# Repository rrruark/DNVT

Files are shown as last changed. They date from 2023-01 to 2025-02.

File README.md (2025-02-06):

# DNVT
Digital Non-secure Voice Terminal Test Code and Switch PCBA Design Files.

http://robruark.com/projects/DNVT/DNVT_overview.html

This repo contains the PCBA design files for the DNVT test interface boards, four phone switches which run Nick Andre's code, and the crappy support code I wrote to initially reverse engineering DNVTs. 

The Arduino code encodes and decodes Differential Manchester, and the Python scripts determine the codewords. There is also a Python script which decodes differential manchester based on a CSV capture from an oscilloscope. Example files are provided.

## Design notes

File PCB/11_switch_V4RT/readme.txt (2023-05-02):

Eagle Schematic: DNVT_box3rt.sch
Eagle Layout: DNVT_box3rt.brd
Schematic PDF: DNVT_box3rt.pdf

JLCPCB Gerbers: DNVT_box3rt_2023-05-02.zip
JLCPCB Top Placement: DNVT_box3rt_top_cpl.csv
JLCPCB BOM: DNVT_box3rt_top_bom.csv

Through Hole BOM: DNVT_box3rt_th_bom.csv
Additional BOM: DNVT_box3r_aux_bom.csv

Notes:

-The JLCPCB BOM maps all surface mount parts and all through hole parts aside from the DC barrel jack and transformers to parts available in JLCPCB's parts library.
-The bottom side parts are optional (additional chassis ground to Pico Ground capacitors and uSD card holder)
-The Digikey BOM lists through hole parts (DC barrel jack and transformers) which must be manually assembled.
-The additional BOM lists parts not captured in the Eagle BOM export: the case, OLED screen, Front and back plates, screws, nuts, cable for screen, and 48V power supply.

Designer Contact: Robert Ruark: rob@robruark.com

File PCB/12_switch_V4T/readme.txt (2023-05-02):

Eagle Schematic: DNVT_box4t.sch
Eagle Layout: DNVT_box4t.brd
Schematic PDF: DNVT_box4t.pdf

JLCPCB Gerbers: DNVT_box4t_2023-05-02.zip
JLCPCB Top Placement: DNVT_box4t_top_cpl.csv
JLCPCB BOM: DNVT_box4t_top_bom.csv

Through Hole BOM: DNVT_box4t_th_bom.csv
Additional BOM: DNVT_box4_aux_bom.csv

Notes:

-The JLCPCB BOM maps all surface mount parts and all through hole parts aside from the DC barrel jack, terminal blocks, and transformers to parts available in JLCPCB's parts library.
-The bottom side parts are optional (additional chassis ground to Pico Ground capacitors and uSD card holder)
-The Digikey BOM lists through hole parts which must be manually assembled as well as the LCSC alternatives for these parts where available.
-The additional BOM lists parts not captured in the Eagle BOM export: headers for the Pico, the case, OLED screen, Front and back plates, screws, nuts, cable for screen, and 48V power supply.

Designer Contact: Robert Ruark: rob@robruark.com

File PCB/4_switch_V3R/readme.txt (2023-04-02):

Eagle Schematic: DNVT_box3r.sch
Eagle Layout: DNVT_box3r.brd
Schematic PDF: DNVT_box3r.pdf

JLCPCB Gerbers: DNVT_box3r_2023-01-16.zip
JLCPCB Top Placement: DNVT_box3r_top_cpl.csv
JLCPCB BOM: DNVT_box3r_top_bom.csv

Through Hole BOM: DNVT_box3r_th_bom.csv
Additional BOM: DNVT_box3r_aux_bom.csv

Notes:

-The rotation of the inductors and RS422 transceivers must be manually corrected at the placement review step after uploading to JLCPCB.
-The JLCPCB BOM maps all surface mount parts to parts available in JLCPCB's parts library.
-The bottom side parts are optional (additional chassis ground to Pico Ground capacitors and uSD card holder)
-The Digikey BOM lists through hole parts which must be manually assembled as well as the LCSC alternatives for these parts where available.
-The additional BOM lists parts not captured in the Eagle BOM export: headers for the Pico, the case, OLED screen, Front and back plates, screws, nuts, cable for screen, and 48V power supply.

Designer Contact: Robert Ruark: rob@robruark.com

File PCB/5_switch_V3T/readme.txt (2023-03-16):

Eagle Schematic: DNVT_box3t.sch
Eagle Layout: DNVT_box3t.brd
Schematic PDF: DNVT_box3t.pdf

JLCPCB Gerbers: DNVT_box3t_2023-02-21.zip
JLCPCB Top Placement: DNVT_box3t_top_cpl.csv
JLCPCB BOM: DNVT_box3t_top_bom.csv

Through Hole BOM: DNVT_box3t_th_bom.csv
Additional BOM: DNVT_box3_aux_bom.csv

Notes:

-The rotation of the inductors and RS422 transceivers must be manually corrected at the placement review step after uploading to JLCPCB.
-The JLCPCB BOM maps all surface mount parts to parts available in JLCPCB's parts library.
-The bottom side parts are optional (additional chassis ground to Pico Ground capacitors and uSD card holder)
-The Digikey BOM lists through hole parts which must be manually assembled as well as the LCSC alternatives for these parts where available.
-The additional BOM lists parts not captured in the Eagle BOM export: headers for the Pico, the case, OLED screen, Front and back plates, screws, nuts, cable for screen, and 48V power supply.

Engineer Contact: Robert Ruark: rob@robruark.com

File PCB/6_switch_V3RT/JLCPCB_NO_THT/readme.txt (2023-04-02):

Eagle Schematic: DNVT_box3rt.sch
Eagle Layout: DNVT_box3rt.brd
Schematic PDF: DNVT_box3rt.pdf

JLCPCB Gerbers: DNVT_box3rt_2023-02-21.zip
JLCPCB Top Placement: DNVT_box3rt_top_cpl.csv
JLCPCB BOM: DNVT_box3rt_top_bom.csv

Through Hole BOM: DNVT_box3rt_th_bom.csv
Additional BOM: DNVT_box3r_aux_bom.csv

Notes:

-With this set of files, JLCPCB will only assemble the surface mount parts. This was used to order initial runs of the DNVT switch prior to when I figured out how to get them to assemble through holes parts (their scripts do not handle through hole parts, so you have to manually add them to the BOM and placement file).
-The rotation of the inductors and RS422 transceivers must be manually corrected at the placement review step after uploading to JLCPCB.
-The JLCPCB BOM maps all surface mount parts to parts available in JLCPCB's parts library.
-The bottom side parts are optional (additional chassis ground to Pico Ground capacitors and uSD card holder)
-The Digikey BOM lists through hole parts which must be manually assembled as well as the LCSC alternatives for these parts where available.
-The additional BOM lists parts not captured in the Eagle BOM export: headers for the Pico, the case, OLED screen, Front and back plates, screws, nuts, cable for screen, and 48V power supply.

Designer Contact: Robert Ruark: rob@robruark.com

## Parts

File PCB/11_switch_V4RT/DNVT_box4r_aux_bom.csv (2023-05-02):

Part | Quantity | Supplier 1 | Link or Ordering Number 1 | Supplier 2 | Link or Ordering Number 2
48V power supply | 1 | Digikey | 993-1303-ND
M3x6 Screw | 8 | Amazon | https://www.amazon.com/dp/B09D93RW6L?psc=1&ref=ppx_yo2ov_dt_b_product_details
M2x6 Screw | 4 | Amazon | https://www.amazon.com/dp/B09D93RW6L?psc=1&ref=ppx_yo2ov_dt_b_product_details
M2 Nut | 3 | Digikey | H761-ND | Amazon | https://a.co/d/bEnPR0s
4-pin Dupont Cable | 1 | Amazon | https://www.amazon.com/gp/product/B0789F523N/ref=ppx_yo_dt_b_search_asin_title?ie=UTF8&psc=1
OLED Screed | 1 | Amazon | https://www.amazon.com/gp/product/B09C5K91H7/ref=ppx_yo_dt_b_search_asin_title?ie=UTF8&psc=1
Front Plate | 1 | JLCPCB | https://github.com/rrruark/DNVT/tree/master/PCB/7_box_front
Back Plate | 1 | JLCPCB | https://github.com/rrruark/DNVT/tree/master/PCB/8_box_back_rj45
RASPBERRY PI PICO H | 1 | Digikey | 2648-SC0917-ND | Amazon | https://a.co/d/59dRezT

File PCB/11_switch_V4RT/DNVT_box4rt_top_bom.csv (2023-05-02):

Comment | Designator | Footprint | LCSC Part #
0 | R7 R34 R44 R54 | R0805
0.1uF | C6 C9 C12 C14 C41 C45 | 603
1M | R8 | 1206 | C17927
1k | R18 R19 | 603
1nF | C2 C3 C4 C7 C8 C10 | 805
1nF | C16 | 1206 | C9196
1nF | C18 C19 C20 C21 C22 C23 C25 C26 C27 C28 C29 C30 C32 C33 C34 C35 C36 C37 | 805
1uF | C1 C5 C11 C13 C15 C17 C24 C31 | 805
1uF | C40 | 1206
1uF | C42 | 805
10 | R1 R2 R4 R10 R17 R20 R21 R22 R23 R24 R25 R26 R27 R28 | 603
10 | R29 | 1206
10 | R31 | 603
10k | R3 R9 R15 | 603
33uH | L1 L2 L3 L4 L5 L6 L7 L8 L9 L10 L11 L12 L13 L14 L15 L16 | SDR0403 | C341014
49.9 | R12 R13 R37 R38 R47 R48 R57 R58 | R0805
100pF | C43 C44 | 603
120 | R14 R41 R51 R61 | 1206
470 | R5 R11 R32 R36 R42 R46 R52 R56 | R0805
600V | GDT1 GDT2 GDT3 GDT4 GDT5 GDT6 GDT7 GDT8 | 2036_GDT | C2908079
1206_FUSE | F1 F2 F3 F4 | 1206 | C135333
ES1JFL | CR1 CR2 | SOD123(AK) | C64898
ISL83490IBZ-T | U1 U2 U3 U5 | SOIC8 | C2932177
SMAJ5.0CA/TR7 | D3 D4 D8 D9 D10 D11 D12 D13 | DO-214AC_NO_POL | C78402
RJ45 | J1 J2 |  | C3010550
Welding terminal | J3 | 7779 or 8190 | C238168
6 pin header | JP1 |  | C2935935
4 pin header | JP3 |  | C2691448
20 pin header | JP4 JP5 |  | C429947
RA tactile sw | SW1 |  | C2845272
4 dip switch | SW2 |  | C962226

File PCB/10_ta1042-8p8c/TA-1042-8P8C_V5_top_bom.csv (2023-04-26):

Comment | Designator | Footprint | LCSC Part #
TPTP20R | BLUE BLUE-WHITE GREEN GREEN-WHITE | TP20R
RJ45 | J1 J2 |  | C3010550

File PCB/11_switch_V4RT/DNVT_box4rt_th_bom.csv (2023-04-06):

Qty | Value | Device | Package | Parts | Description | Assembled by JLCPCB | PARTNO
8 | 78615/9C | 78615/9C | 786T | T1, T2, T3, T4, T5, T6, T7, T8 | 10mH General Purpose Pulse Transformer 1CT:1CT 56Vus | No | 811-1261-5-ND
1 | PJ-002A | PJ-002A | PJ-002A | J4 | Power Barrel Connector Jack 2.10mm ID (0.083"), 5.50mm OD (0.217") Through Hole, Right Angle | No | CP-002A-ND

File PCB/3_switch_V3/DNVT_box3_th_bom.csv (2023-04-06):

Qty | Value | Device | Package | Parts | Description | Assembled by JLCPCB | PARTNO | LCSC | SPICEPREFIX | VALUE
1 |  | PINHD-1X4 | 1X04 | JP3 | PIN HEADER | No | 2057-PH1-04-UA-ND | C2691448
1 |  | PINHD-2X3/90 | 2X03/90 | JP1 | PIN HEADER | No | 2057-PH2RA-06-UA-ND | C2935935
1 |  | SW_DIP-4 | EDG-04 | SW2 | DIP SWITCH | No | 2449-KG04E-ND | C962226
4 | 0 | R-US_R0805 | R0805 | R7, R34, R44, R54 | RESISTOR, American symbol | Yes |  |  | R
5 | 0.1uF | 0603_CAPACITOR | 603 | C6, C9, C12, C14, C41 | 0603 Capacitor -- WARNING: NO DEFINED VALUE OR PART NUMBER | Yes |  |  |  | sel
15 | 10 | 0603_RESISTOR | 603 | R1, R2, R4, R10, R17, R20, R21, R22, R23, R24, R25, R26, R27, R28, R31 | 0603 Resistor -- WARNING: NO DEFINED PART NUMBER OR VALUE | Yes |  |  |  | sel
1 | 10 | 1206_RESISTOR | 1206 | R29 | NO DEFINED PN | Yes |  |  |  | sel
3 | 10k | 0603_RESISTOR | 603 | R3, R9, R15 | 0603 Resistor -- WARNING: NO DEFINED PART NUMBER OR VALUE | Yes |  |  |  | sel
4 | 120 | 1206_RESISTOR | 1206 | R14, R41, R51, R61 | NO DEFINED PN | Yes |  |  |  | sel
4 | 1206_FUSE | 1206_FUSE | 1206 | F1, F2, F3, F4 |  | Yes
1 | 1M | 1206_RESISTOR | 1206 | R8 | NO DEFINED PN | Yes |  |  |  | sel
2 | 1k | 0603_RESISTOR | 603 | R18, R19 | 0603 Resistor -- WARNING: NO DEFINED PART NUMBER OR VALUE | Yes |  |  |  | sel
24 | 1nF | 0805_CAPACITOR | 805 | C2, C3, C4, C7, C8, C10, C18, C19, C20, C21, C22, C23, C25, C26, C27, C28, C29, C30, C32, C33, C34, C35, C36, C37 | NO DEFINED PN | Yes
1 | 1nF | 1206_CAPACITOR | 1206 | C16 | NO DEFINED PN | Yes |  |  |  | sel
9 | 1uF | 0805_CAPACITOR | 805 | C1, C5, C11, C13, C15, C17, C24, C31, C42 | NO DEFINED PN | Yes
1 | 1uF | 1206_CAPACITOR | 1206 | C40 | NO DEFINED PN | Yes |  |  |  | sel
16 | 33uH | SDR0403-330KL | SDR0403 | L1, L2, L3, L4, L5, L6, L7, L8, L9, L10, L11, L12, L13, L14, L15, L16 | 33 µH Unshielded Drum Core, Wirewound Inductor 640 mA 540mOhm Max Nonstandard | Yes | SDR0403-330KLCT-ND |  |  | 33uH
8 | 470 | R-US_R0805 | R0805 | R5, R11, R32, R36, R42, R46, R52, R56 | RESISTOR, American symbol | Yes |  |  | R
8 | 49.9 | R-US_R0805 | R0805 | R12, R13, R37, R38, R47, R48, R57, R58 | RESISTOR, American symbol | Yes |  |  | R
8 | 600V | 2036-60-SM-RPLF | 2036_GDT | GDT1, GDT2, GDT3, GDT4, GDT5, GDT6, GDT7, GDT8 | Gas Discharge Tube 600 V 10000A (10kA) ±20% 3 Pole Surface Mount | Yes | 2036-60-SM-RPLFCT-ND |  |  | 600V
8 | 78602/9JC | 78602/9JC | 786 | T1, T2, T3, T4, T5, T6, T7, T8 | 10mH General Purpose Pulse Transformer 1CT:1CT Surface Mount 56Vus | No | 811-1261-5-ND
1 | 8190 | 8190 | 7781 | J3 | 4 Pin Screw Terminal, Power Tap 6-32 Through Hole, Right Angle | No | 36-8190-ND
2 | 1841513 | 1841513 | 1841513 | J6, J7 | 4x2 Position Wire to Board Terminal Block Horizontal with Board 0.138 | (3.50mm) | Through | Hole. | Compatible | with | Cixi | Kefa | Elec | KF207RH-3.5-2*4P" | 277-10317-ND
3 | DNP | 0603_RESISTOR | 603 | R16, R30, R35 | 0603 Resistor -- WARNING: NO DEFINED PART NUMBER OR VALUE | No |  |  |  | sel
2 | DNP | 1206_CAPACITOR | 1206 | C38, C39 | NO DEFINED PN | No |  |  |  | sel
4 | DNP | R-US_R0805 | R0805 | R6, R33, R43, R53 | RESISTOR, American symbol | No |  |  | R
2 | ES1JFL | ES1JFL | SOD123(AK) | CR1, CR2 | Diode Standard 600 V 1A Surface Mount SOD-123F | Yes | ES1JFLCT-ND
1 | EVQ-PF008K | EVQ-PF008K | EVQ-PF008K | SW1 | Tactile Switch SPST-NO Side Actuated Through Hole, Right Angle | No | P10880S-ND
1 | PJ-002A | PJ-002A | PJ-002A | J4 | Power Barrel Connector Jack 2.10mm ID (0.083"), 5.50mm OD (0.217") Through Hole, Right Angle | No | CP-002A-ND
4 | ISL83490IBZ-T | ISL83490IBZ-T | SOIC8 | U1, U2, U3, U5 | 1/1 Transceiver Full RS422, RS485 8-SOIC 3.3V | Yes | ISL83490IBZ-TCT-ND
1 | MEM2080-00-128-00-A | MEM2080-00-128-00-A | MEM2080 | J5 | 9 (8 + 1) Position Card Connector Secure Digital - microSD™ Surface Mount, Right Angle Gold | No | 2073-MEM2080-00-128-00-ACT-ND
1 | RASPBERRY_PICOTH | RASPBERRY_PICOTH | PICO-PKG-TH | U7 | Raspberry Pi Pico | No | 2648-SC0917-ND
8 | SMAJ5.0CA/TR7 | SMAJ5.0CA/TR7 | DO-214AC_NO_POL | D3, D4, D8, D9, D10, D11, D12, D13 | 9.2V Clamp 43.5A Ipp Tvs Diode Surface Mount DO-214AC (SMA) | Yes

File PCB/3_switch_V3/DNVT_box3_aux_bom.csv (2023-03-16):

Part | Quantity | Supplier 1 | Link or Ordering Number 1 | Supplier 2 | Link or Ordering Number 2
1x20 female header | 2 | Digikey | 952-1905-ND | LCSC | C5224030
48V power supply | 1 | Digikey | 993-1303-ND
M3x6 Screw | 8 | Amazon | https://www.amazon.com/dp/B09D93RW6L?psc=1&ref=ppx_yo2ov_dt_b_product_details
M2x6 Screw | 4 | Amazon | https://www.amazon.com/dp/B09D93RW6L?psc=1&ref=ppx_yo2ov_dt_b_product_details
M2 Nut | 3 | Digikey | H761-ND | Amazon | https://www.amazon.com/gp/product/B01KCOH60K/ref=ppx_yo_dt_b_search_asin_title?ie=UTF8&th=1
4-pin Dupont Cable | 1 | Amazon | https://www.amazon.com/gp/product/B0789F523N/ref=ppx_yo_dt_b_search_asin_title?ie=UTF8&psc=1
OLED Screen | 1 | Amazon | https://www.amazon.com/gp/product/B09C5K91H7/ref=ppx_yo_dt_b_search_asin_title?ie=UTF8&psc=1
Front Plate | 1 | JLCPCB | https://github.com/rrruark/DNVT/tree/master/PCB/7_box_front
Back Plate | 1 | JLCPCB | https://github.com/rrruark/DNVT/tree/master/PCB/9_box_back

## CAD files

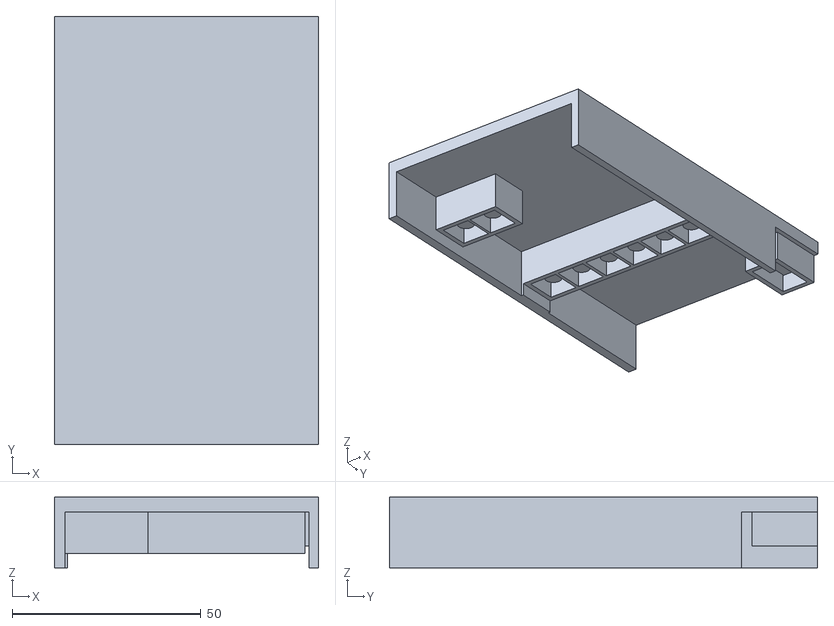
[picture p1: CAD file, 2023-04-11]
PCB/Soldring_fixture.stl
70.0 x 113.4 x 18.8

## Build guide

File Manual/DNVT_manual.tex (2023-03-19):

%% Example data sheet
%% Feel free to modify and use this file for any purpose, under
%% either the LaTeX Project Public License or under public domain.

% Options here are passed to the article class.
% Most common options: 10pt, 11pt, 12pt
\documentclass[10pt]{datasheet}

% Input encoding and typographical rules for English language
\usepackage[utf8]{inputenc}
\usepackage[english]{babel}
\usepackage[english]{isodate}
\usepackage[final]{pdfpages}

% tikz is used to draw images in this example, but you can
% also use \includegraphics{}.
\usepackage{tikz}
\usepackage{pgfplots}
\usepackage{circuitikz}

\usetikzlibrary{calc}

% These define global texts that are used in headers and titles.
\title{DNVT Switch}
\author{Robert Ruark}
\date{March 2023}
\revision{Revision 1}
\companylogo{\Huge }

\begin{document}
\maketitle

\section{Features}

\begin{itemize}
\item{4 DNVT (Digital Non-Secure Voice Terminal) Phone Interfaces supporting 16 kHz or 32 kHz operation.}
\item{Rugged extruded aluminum case.}
\item{128x64 pixel OLED display.}
\item{Front panel expansion header.}
\item{Foolproof USB firmware update.}
\item{Terminal block and RJ45 DNVT interface options.}
\item{Transient voltage protection.}
\end{itemize}

\section{Applications}

\begin{itemize}
\item{Stand-alone local switching of four DNVTs}
\item{VOIP to DNVT adapters.}
\item{DNVT operation for functional film props.}
\end{itemize}

\section{Supported Phones}

\begin{itemize}
\item{TA-1042/U}
\item{TA-1035/U}
\item{TA-954/TT}
\item{CA-67A/U (Untested)}
\item{KY-68 (Assumed compatible in non-secure mode)}
\end{itemize}

\section{General Description}
This PCBA is a Raspberry Pi Pico carrier board which interfaces DNVTs with a Raspberry Pi Pico. This document describes the function of the carrier board subassembly and does not cover custom software which may run on the Raspberry Pi Pico microcontroller.

DNVTs are powered in common battery (CB) mode through center-tapped isolation transformers from a 48 V DC barrel jack input allowing phones to operate at a distance of up to 4 km from the switch through CAT5e or equivilent wiring. RS422 transceivers translate the 3.3 V logic level signals of the Raspberry Pi Pico to the differential signals required to interface with the DNVTs.

The design files for this switch can be found in the project's \href{https://github.com/PetteriAimonen/latex-datasheet-template/}{Github repository}, and Nick Andre's example firmware can be found in his \href{https://github.com/PetteriAimonen/latex-datasheet-template/}{Github repository}. Details on the design of this board and the process of reverse engineering the DNVT's control codes can be found \href{https://github.com/PetteriAimonen/latex-datasheet-template/}{here}.

This project is entirely open source. Design files for the PCBAs and vill of materials for the case and auxillary components can be found at the above linked repository.

\begin{figure}
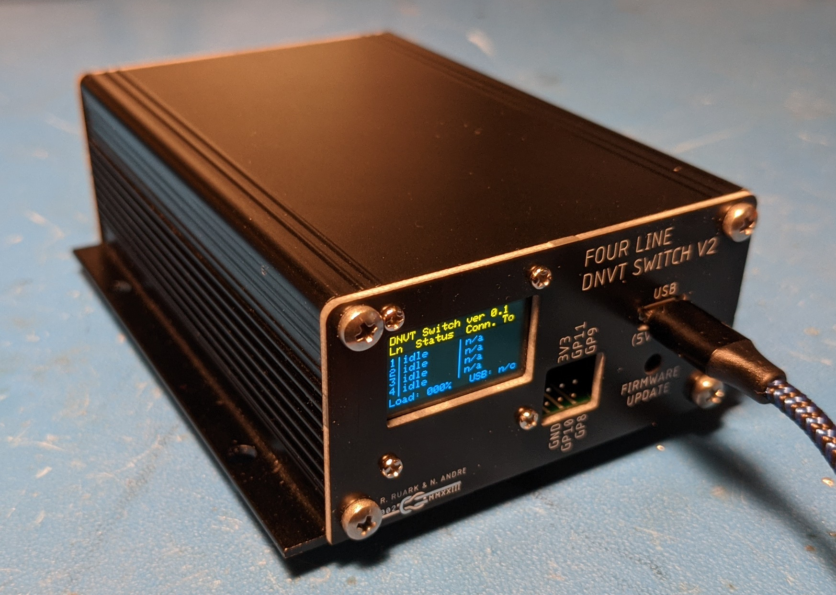
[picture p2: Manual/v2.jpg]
  
  \caption{Front View of DNVT Switch}
  \label{fig:boat1}
\end{figure}

% For wide tables, a single column layout is better. It can be switched
% page-by-page.
\onecolumn

\section{Electrical Specifications}
All specifications are in $0\degree C \leq T_A \leq 70\degree C$. All components are rated to -40 to +85 aside from the line transformers which are rated to $0\degree C$ to $70\degree C$ but which have been tested in qualification to $-20\degree C$ to $+85\degree C$.

\begin{table}[h]
\begin{threeparttable}
\caption{Example Data Sheet Specifications}
\begin{tabularx}{\textwidth}{l | c | c c c | c | X}
    \thickhline
    \textbf{Parameter} & \textbf{Symbol} & \textbf{Min.} & \textbf{Typ.} & \textbf{Max.} &
    \textbf{Unit} & \textbf{Conditions} \\
    \hline
    DNVT PWR Input Voltage  & $V_{in}$ & 24 & 48 & 56 & $V$ & {Standard A4 paper} \\
    \hline
    DNVT PWR Input Current & $I_{in}$ & 29.6 & 29.7 & 29.8 & $A$ & All phones consuming maximum specified power with 4 km CAT5e Cable\\
    \hline
    DNVT Current Limit & $I_{ph-max}$ &  & 150 &  & $mA$ & Current limit per phone\\    
    \hline
    Input Differential Swing & $\Delta V_{TH}$ & 50 &  & & $mV$ & $VIN_{P}-VIN_N$\\
    \hline
    Output Differential Swing & $E_{max}$ & & 3 & & $V$ & $VOUT_P-VOUT_N$\\        
    \thickhline
\end{tabularx}
\end{threeparttable}
\end{table}

\section{Absolute Maximum Ratings}

\begin{table}[h]
\caption{Absolute Maximum Ratings of Example Data Sheet}
\begin{tabularx}{\textwidth}{l | X}
    \thickhline
    \textbf{Parameter} & \textbf{Rating} \hspace{5cm} \\
    \hline
    DNVT PWR Input Voltage & 60 V \\
    \hline
    Storage Temperature & 100$\degree C$ \\
    \hline
    Operating Temperature & 85$\degree C$ \\
    \thickhline
\end{tabularx}
\end{table}

\textbf{Note:} Stresses above those listed under Absolute Maximum Ratings can
cause permanent damage to the device. This is a stress rating only. Functional
operation of the device is not implied in any conditions above those indicated
in the Electrical Specifications section.

\includepdf[pages=-]{DNVT_box3rt.pdf}

\subsection{Important Notice}

Information relating to this product and the application or design described herein is believed to be reliable, however such information
is provided as a guide only and the author assumes no liability for any errors in this document, or for the application or design described
herein.

THIS PRODUCT IS NOT DESIGNED, INTENDED, AUTHORIZED OR WARRANTED TO BE SUITABLE FOR USE IN LIFE-SUPPORT
APPLICATIONS, SEARH AND RESCUE APPLICATIONS, OR IN APPLICATIONS IN WHICH THE FAILURE COULD BE REASONABLY EXPECTED TO
RESULT IN PERSONAL INJURY, LOSS OF LIFE OR SEVERE PROPERTY OR ENVIRONMENTAL DAMAGE. INCLUSION OF THIS PRODUCT IN
SUCH APPLICATIONS IS UNDERSTOOD TO BE UNDERTAKEN SOLELY AT THE CUSTOMER’S OWN RISK. 

This product alone does not provide protection to structures from the ingress of lightning and other hazardous transient conditions. Any installation of this product in a structure (house, barn, telephone exchange, etc.) must be made in compliance with NFPA 70 article 800 which requires the use of a secondary protection device at the point of entry to the structure.

Should a customer purchase or use this product for any such unauthorized application, the customer shall indemnify and hold Robert Ruark, Nick Andre, affiliates, and distributors harmless against all claims, costs damages and attorney fees which could arise. The product described in this document may be altered or discontinued without further
notice. No warranty, representation or guarantee, express or implied, regarding the suitability of its products for any
particular purpose is conveyed by the contents of this document. 

© Robert Ruark 2023
\end{document}

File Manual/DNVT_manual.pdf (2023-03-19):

# DNVT Switch

## Features

4 DNVT (Digital Non-Secure Voice Terminal) Phone Interfaces supporting 16 kHz or 32 kHz operation.

Rugged extruded aluminum case.

128x64 pixel OLED display.

Front panel expansion header.

Foolproof USB firmware update.

Terminal block and RJ45 DNVT interface options.

Transient voltage protection.

## Applications

Stand-alone local switching of four DNVTs

VOIP to DNVT adapters.

DNVT operation for functional film props.

## Supported Phones

TA-1042/U

TA-1035/U

TA-954/TT

CA-67A/U (Untested)

KY-68 (Assumed compatible in non-secure mode)


Figure 1: Front View of DNVT Switch

## General Description

This PCBA is a Raspberry Pi Pico carrier board which interfaces DNVTs with a Raspberry Pi Pico. This document describes the function of the carrier board sub-assembly and does not cover custom software which may run on the Raspberry Pi Pico microcontroller.

DNVTs are powered in common battery (CB) mode through center-tapped isolation transformers from a 48 V DC barrel jack input allowing phones to operate at a distance of up to 4 km from the switch through CAT5e or equivilent wiring. RS422 transceivers translate the 3.3 V logic level signals of the Raspberry Pi Pico to the differential signals required to interface with the DNVTs.

The design files for this switch can be found in the project’s Github repository, (https://github.com/PetteriAimonen/latex-datasheet-template/) and Nick Andre’s example firmware can be found in his Github repository. (https://github.com/PetteriAimonen/latex-datasheet-template/) Details on the design of this board and the process of reverse en-gineering the DNVT’s control codes can be found here. (https://github.com/PetteriAimonen/latex-datasheet-template/)

This project is entirely open source. Design files for the PCBAs and vill of materials for the case and auxillary components can be found at the above linked repository.

Revision 1 | March 2023 | Page 1 of 6

Robert Ruark | DNVT Switch | March 2023

## Electrical Specifications

All specifications are in 0◦C ≤ TA ≤ 70◦C. All components are rated to -40 to +85 aside from the line transformers which are rated to 0◦C to 70◦C but which have been tested in qualification to −20◦C to +85◦C.

Table 1: Example Data Sheet Specifications

Parameter | Symbol | Min. | Typ. | Max. | Unit | Conditions
DNVT PWR Input Voltage | Vin | 24 | 48 | 56 | V | Standard A4 paper
DNVT PWR Input Current | Iin | 29.6 | 29.7 | 29.8 | A | All phones consuming maximum specified power with 4 km CAT5e Cable
DNVT Current Limit | Iph−max | | 150 | | mA | Current limit per phone
Input Differential Swing | ∆VTH | 50 | | | mV | V INP − V INN
Output Differential Swing | Emax | | 3 | | V | V OUTP − V OUTN

## Absolute Maximum Ratings

Table 2: Absolute Maximum Ratings of Example Data Sheet

Parameter | Rating
DNVT PWR Input Voltage | 60 V
Storage Temperature | 100◦C
Operating Temperature | 85◦C

Note: Stresses above those listed under Absolute Maximum Ratings can cause permanent damage to the device. This is a stress rating only. Functional operation of the device is not implied in any conditions above those indicated in the Electrical Specifications section.

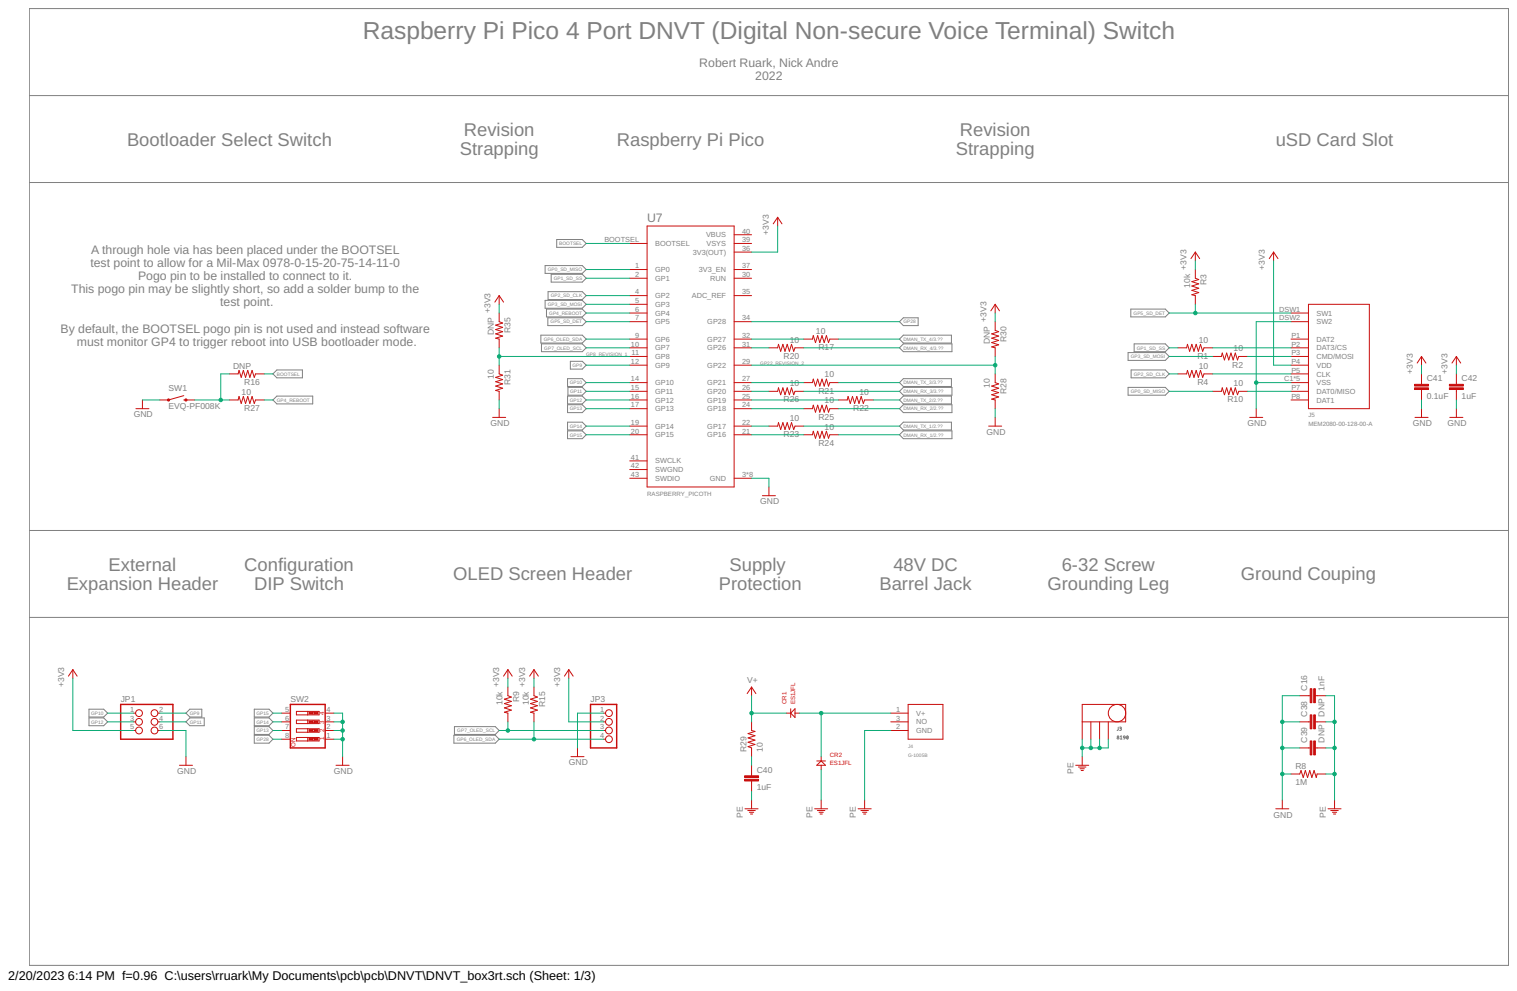
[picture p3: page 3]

Raspberry Pi Pico 4 Port DNVT (Digital Non-secure Voice Terminal) Switch

Robert Ruark, Nick Andre

A through hole via has been placed under the BOOTSEL
test point to allow for a Mil-Max 0978-0-15-20-75-14-11-0
Pogo pin to be installed to connect to it. This pogo pin may be slightly short, so add a solder bump to the

test point. By default, the BOOTSEL pogo pin is not used and instead software

must monitor GP4 to trigger reboot into USB bootloader mode. Configuration

2/20/2023 6:14 PM f=0.96 C:\users\rruark\My Documents\pcb\pcb\DNVT\DNVT_box3rt.sch (Sheet: 1/3)

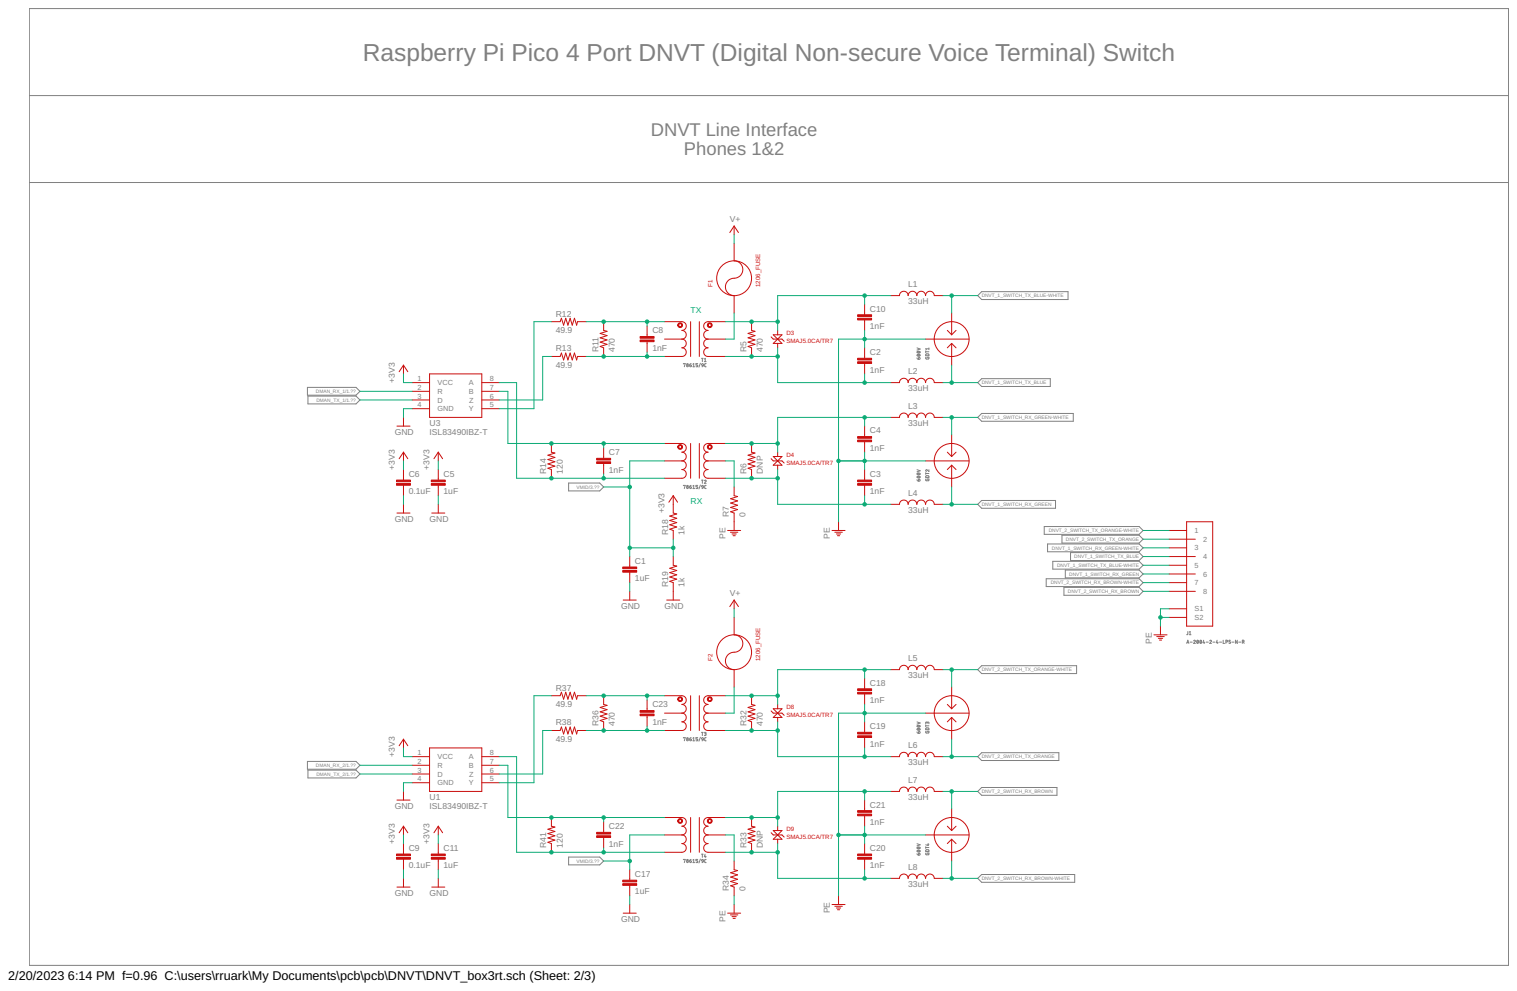
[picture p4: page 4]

Raspberry Pi Pico 4 Port DNVT (Digital Non-secure Voice Terminal) Switch

2/20/2023 6:14 PM f=0.96 C:\users\rruark\My Documents\pcb\pcb\DNVT\DNVT_box3rt.sch (Sheet: 2/3)

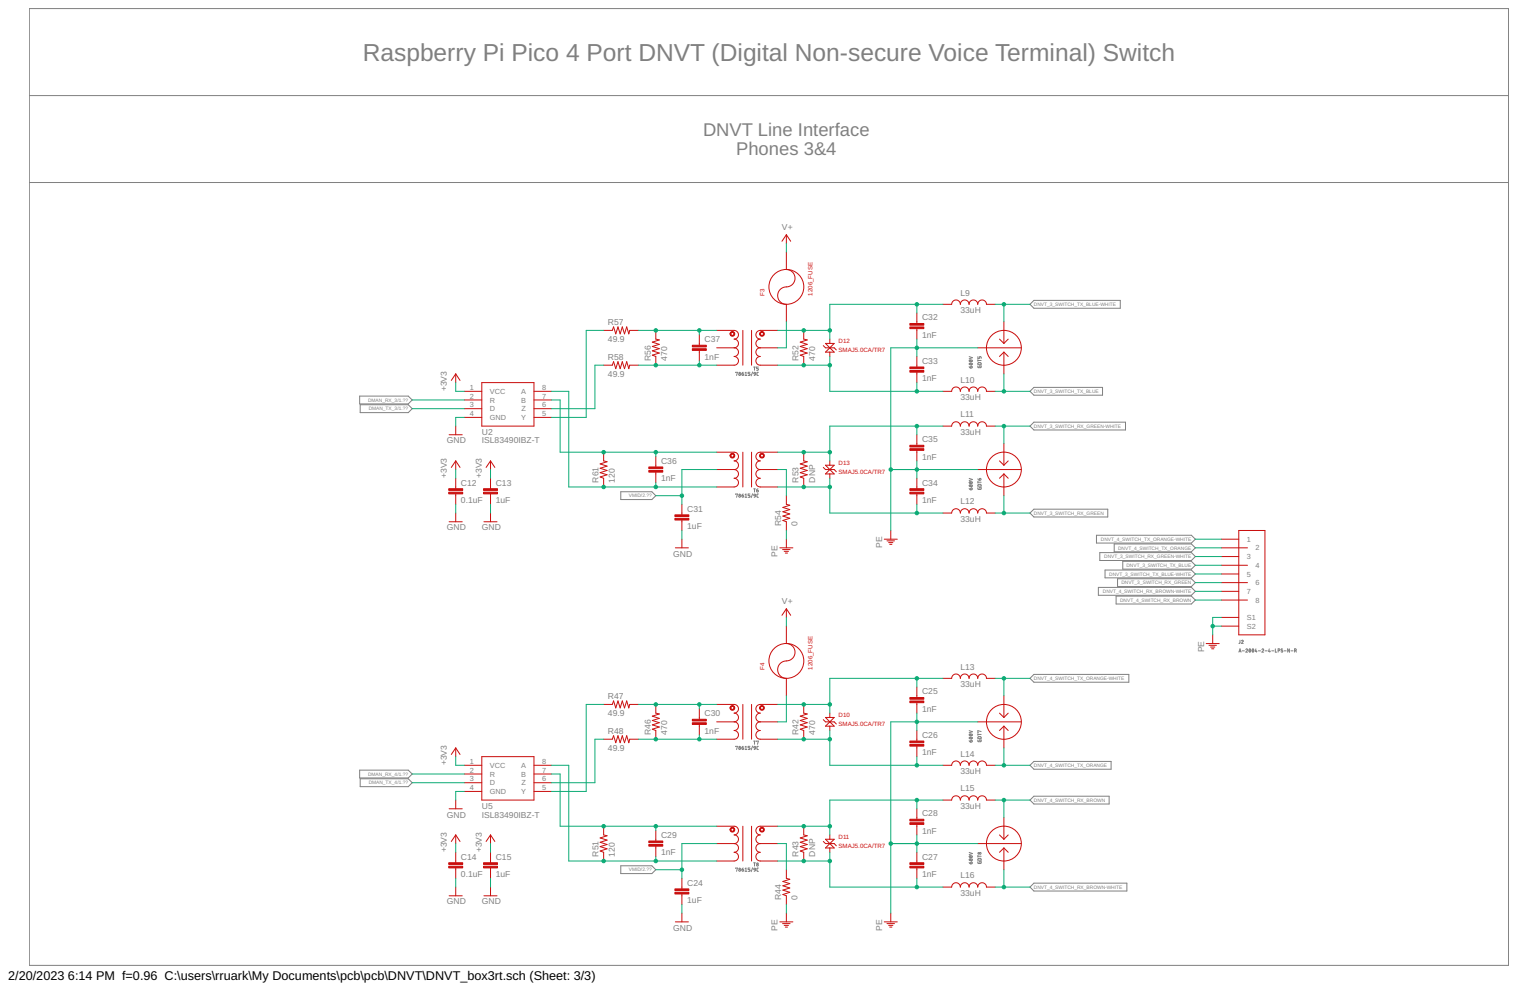
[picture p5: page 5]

Raspberry Pi Pico 4 Port DNVT (Digital Non-secure Voice Terminal) Switch

2/20/2023 6:14 PM f=0.96 C:\users\rruark\My Documents\pcb\pcb\DNVT\DNVT_box3rt.sch (Sheet: 3/3)

Robert Ruark | DNVT Switch | March 2023

Important Notice

Information relating to this product and the application or design described herein is believed to be reliable, however such information is provided as a guide only and the author assumes no liability for any errors in this document, or for the application or design described herein.

THIS PRODUCT IS NOT DESIGNED, INTENDED, AUTHORIZED OR WARRANTED TO BE SUITABLE FOR USE IN LIFE-SUPPORT APPLICATIONS, SEARH AND RESCUE APPLICATIONS, OR IN APPLICATIONS IN WHICH THE FAILURE COULD BE REASONABLY EXPECTED TO RESULT IN PERSONAL INJURY, LOSS OF LIFE OR SEVERE PROPERTY OR ENVIRONMENTAL DAMAGE. INCLUSION OF THIS PROD-UCT IN SUCH APPLICATIONS IS UNDERSTOOD TO BE UNDERTAKEN SOLELY AT THE CUSTOMER’S OWN RISK.

This product alone does not provide protection to structures from the ingress of lightning and other hazardous transient conditions. Any installation of this product in a structure (house, barn, telephone exchange, etc.) must be made in compliance with NFPA 70 article 800 which requires the use of a secondary protection device at the point of entry to the structure.

Should a customer purchase or use this product for any such unauthorized application, the customer shall indemnify and hold Robert Ruark, Nick Andre, affiliates, and distributors harmless against all claims, costs damages and attorney fees which could arise. The product described in this document may be altered or discontinued without further notice. No warranty, representation or guarantee, express or implied, regarding the suitability of its products for any particular purpose is conveyed by the contents of this document.

© Robert Ruark 2023

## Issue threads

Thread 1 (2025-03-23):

Looking for CVSD help

elitewill1200, 2025-03-23:
I saw on your website that you included a pretty good CVSD implementation in this project. I’ve been working on my own implementation but have been struggling getting it to the point where it produces intelligible voice. Did you include your implementation in this repo somewhere for reference? I couldn’t find it.

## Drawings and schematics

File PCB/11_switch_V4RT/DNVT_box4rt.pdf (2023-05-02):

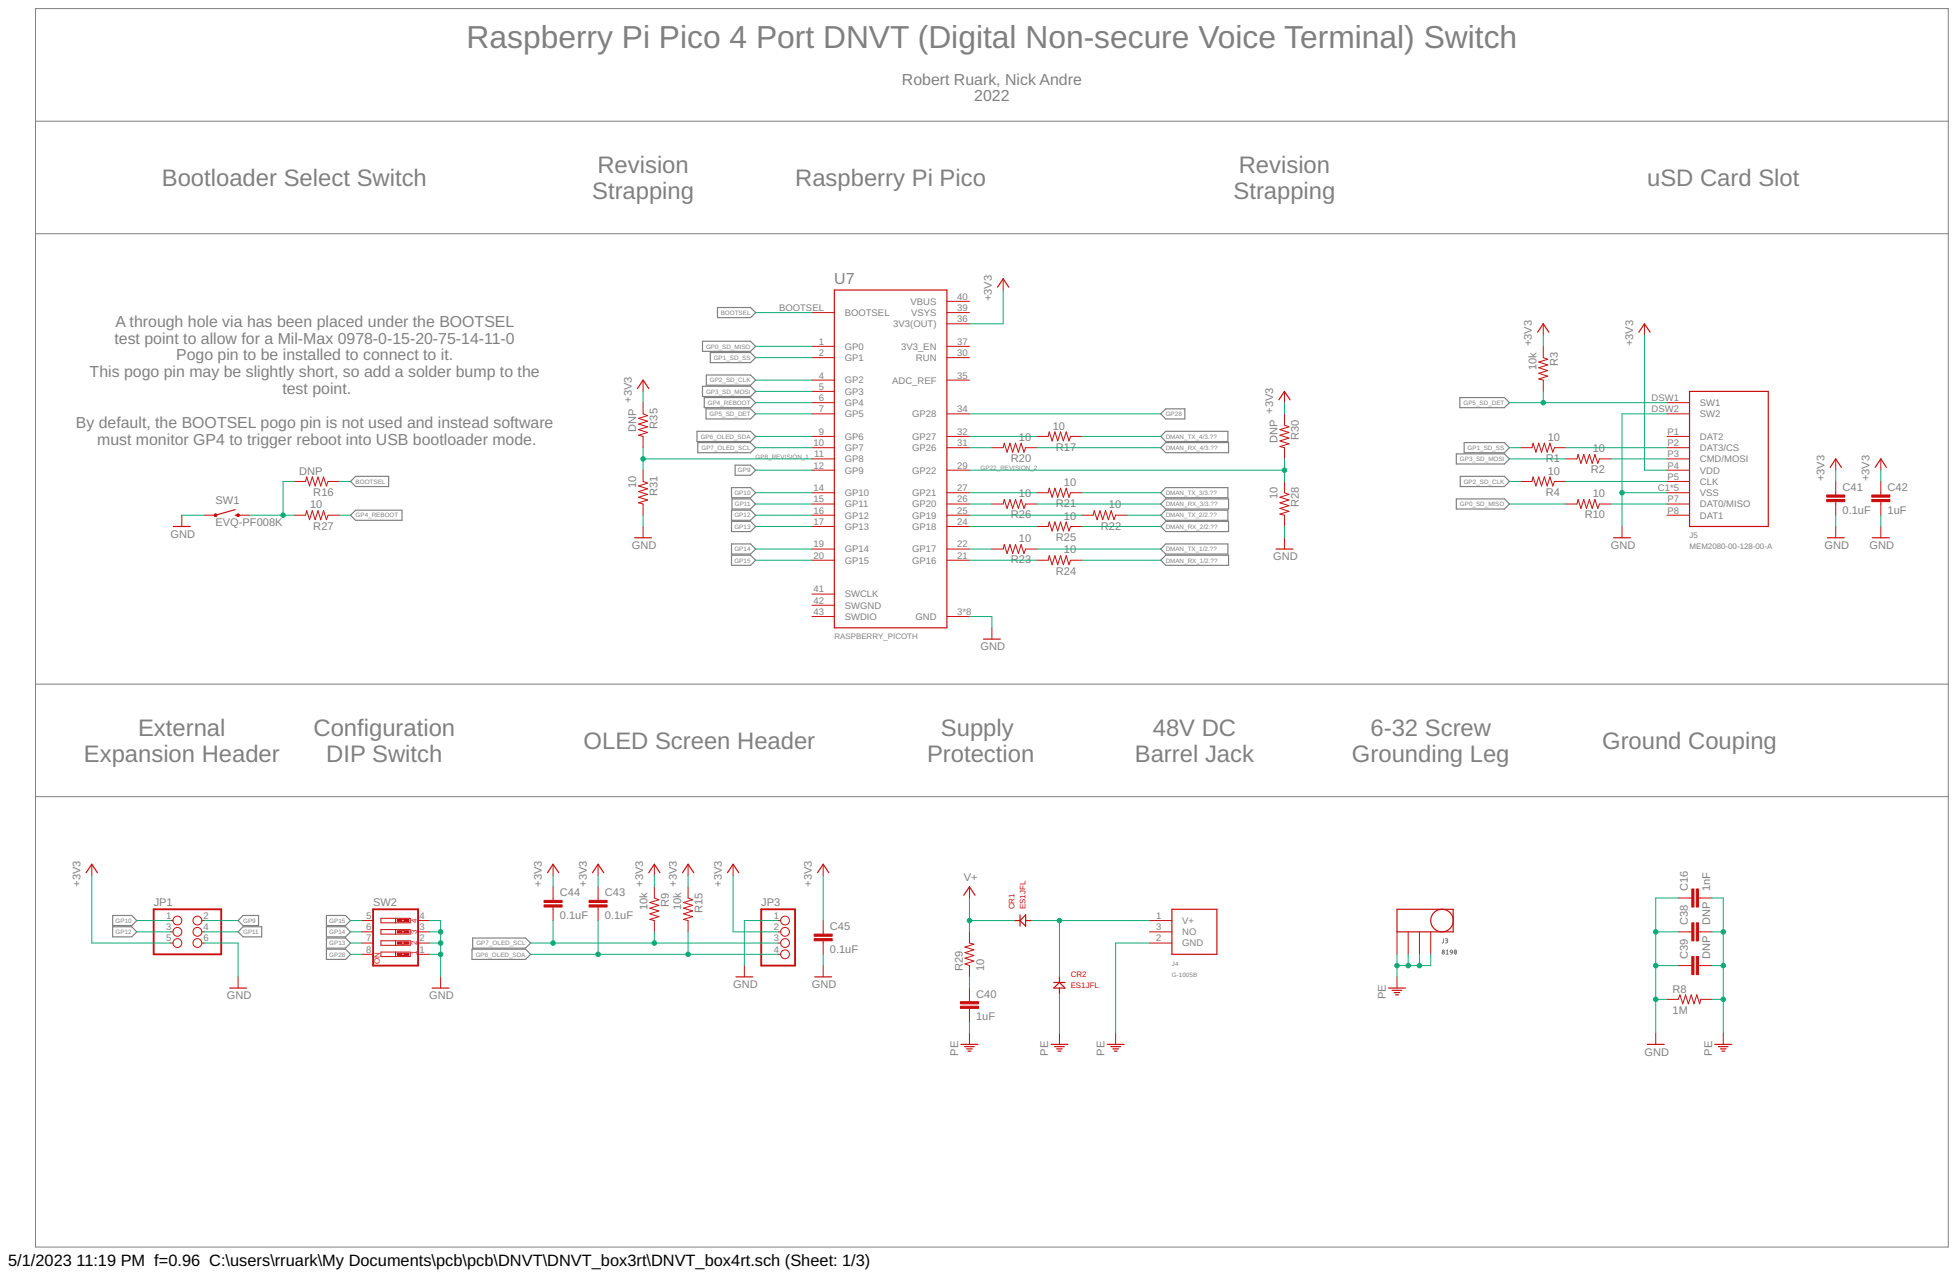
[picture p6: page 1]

Raspberry Pi Pico 4 Port DNVT (Digital Non-secure Voice Terminal) Switch

Robert Ruark, Nick Andre

A through hole via has been placed under the BOOTSEL
test point to allow for a Mil-Max 0978-0-15-20-75-14-11-0
Pogo pin to be installed to connect to it. This pogo pin may be slightly short, so add a solder bump to the

test point. By default, the BOOTSEL pogo pin is not used and instead software

must monitor GP4 to trigger reboot into USB bootloader mode.

5/1/2023 11:19 PM f=0.96 C:\users\rruark\My Documents\pcb\pcb\DNVT\DNVT_box3rt\DNVT_box4rt.sch (Sheet: 1/3)

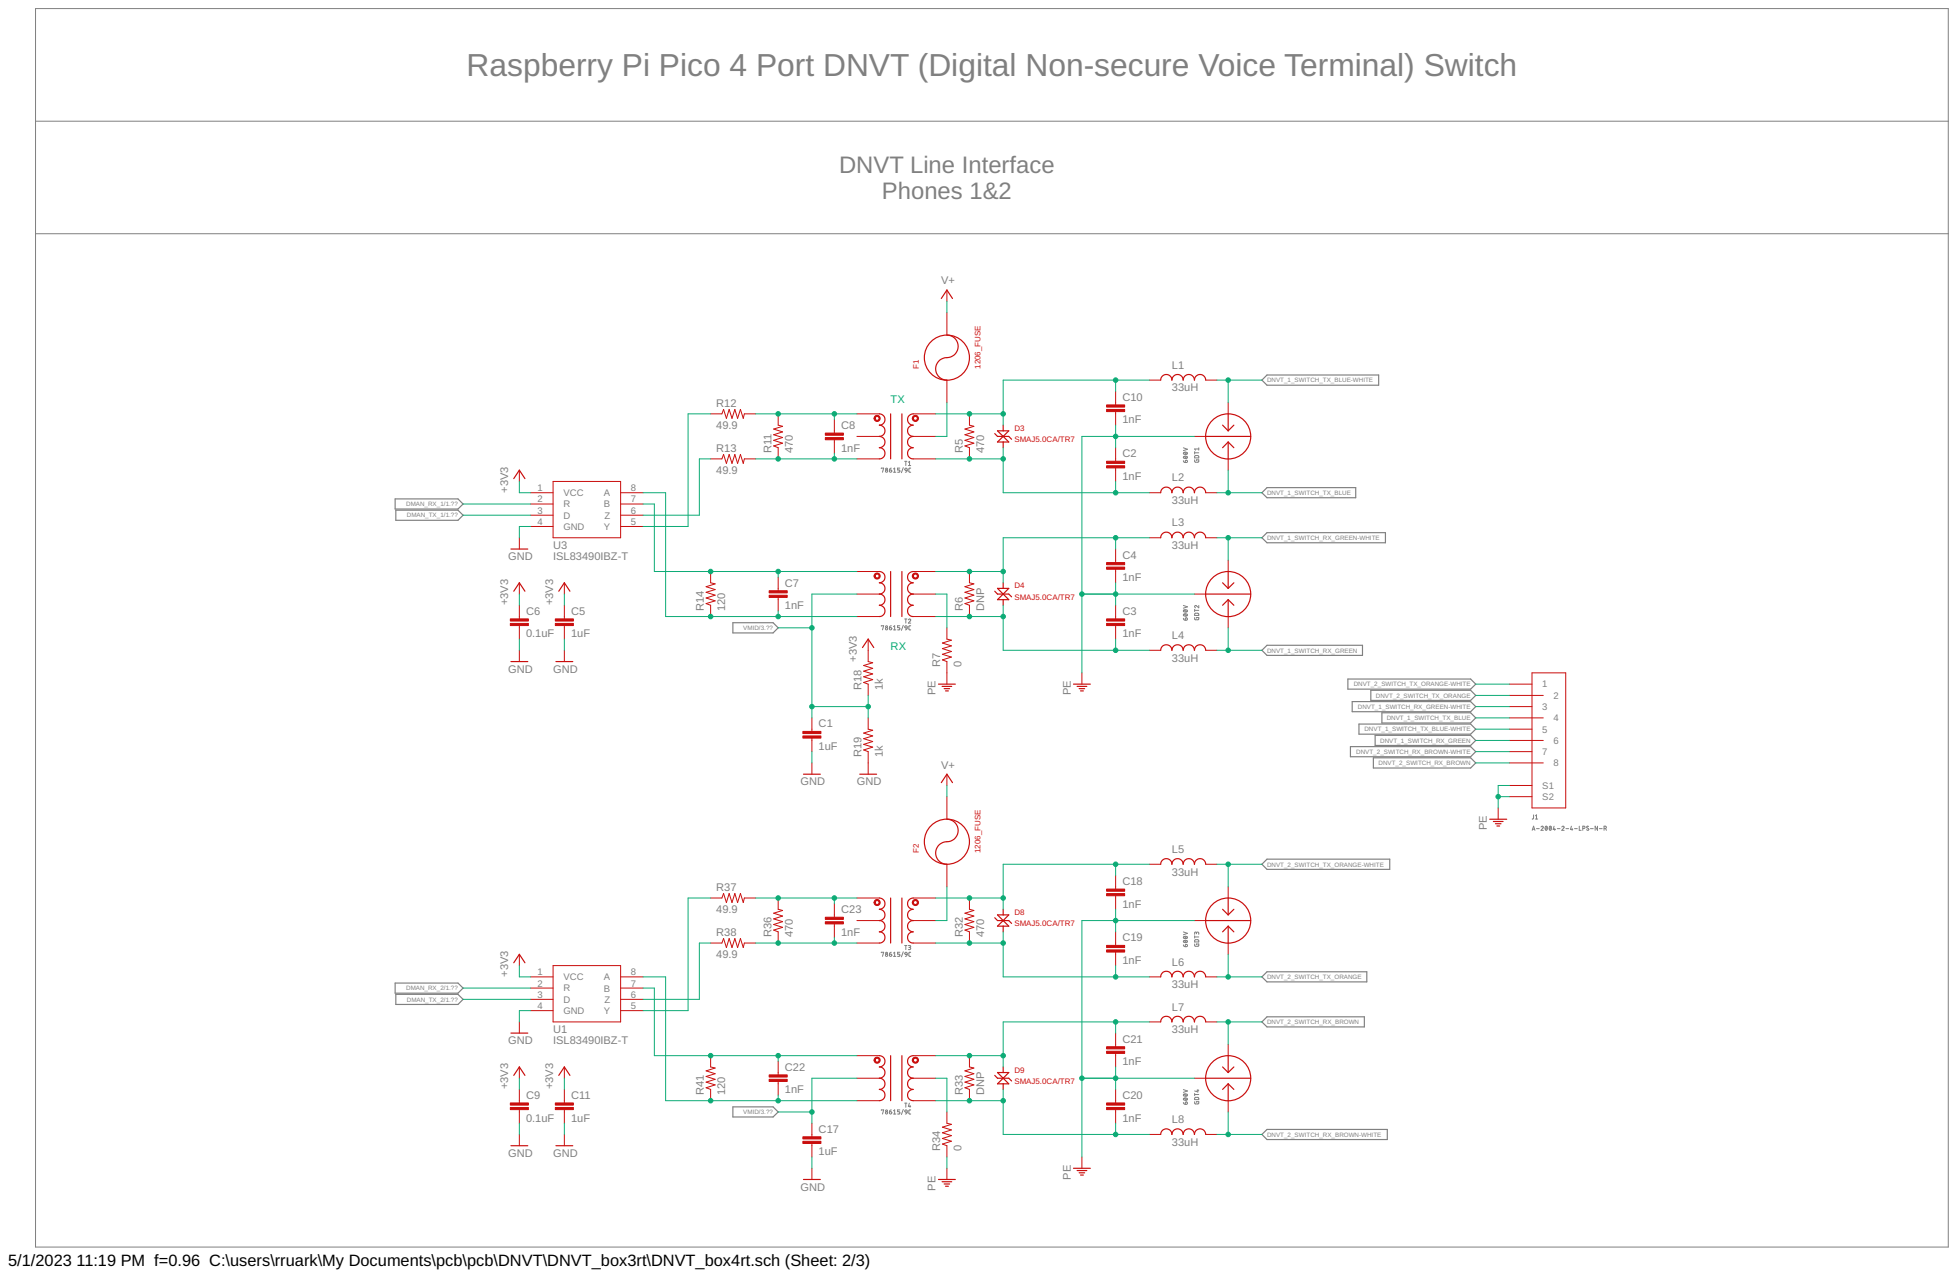
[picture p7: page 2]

5/1/2023 11:19 PM f=0.96 C:\users\rruark\My Documents\pcb\pcb\DNVT\DNVT_box3rt\DNVT_box4rt.sch (Sheet: 2/3)

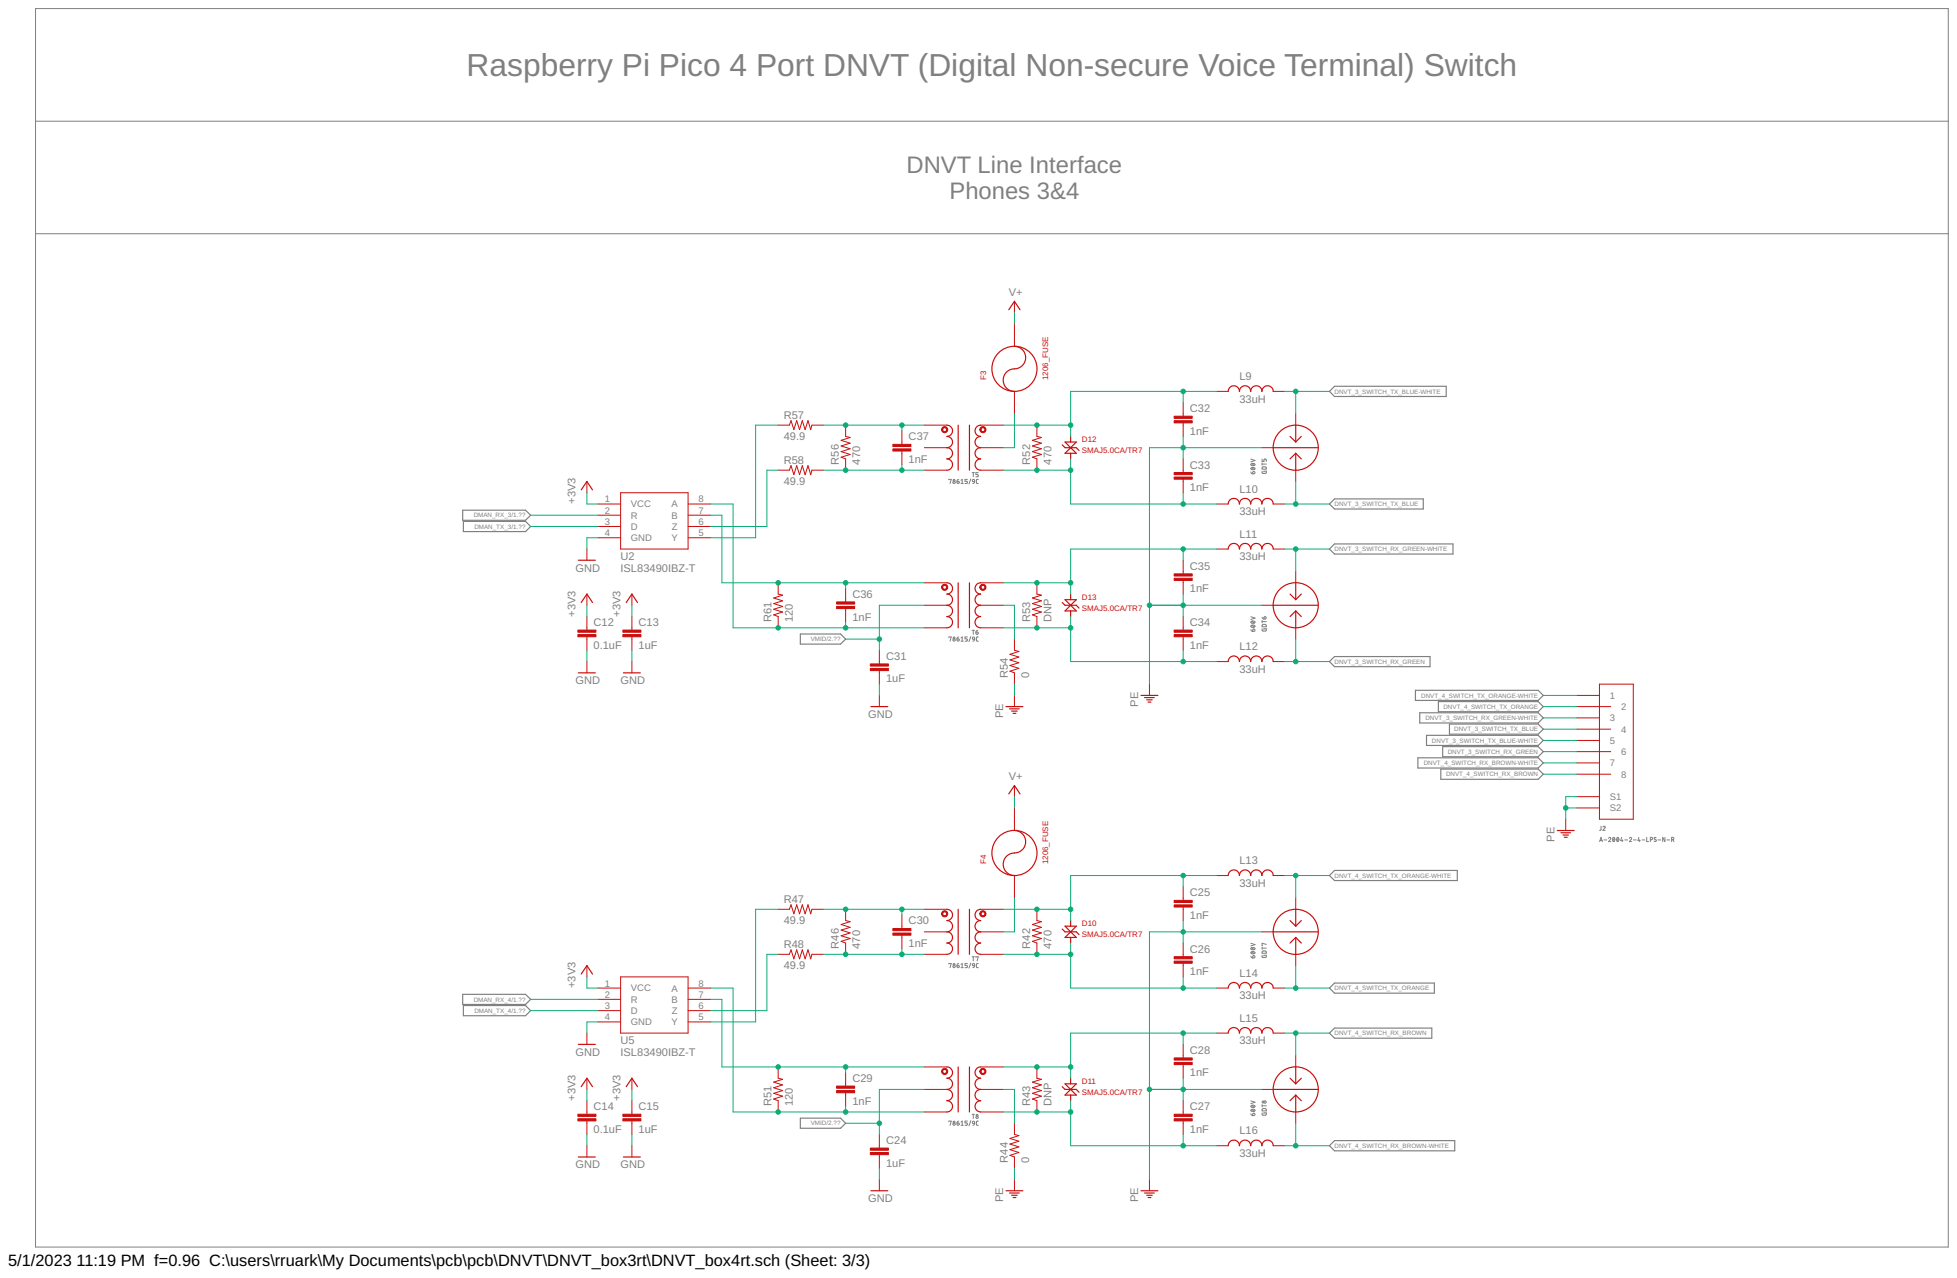
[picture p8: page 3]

5/1/2023 11:19 PM f=0.96 C:\users\rruark\My Documents\pcb\pcb\DNVT\DNVT_box3rt\DNVT_box4rt.sch (Sheet: 3/3)

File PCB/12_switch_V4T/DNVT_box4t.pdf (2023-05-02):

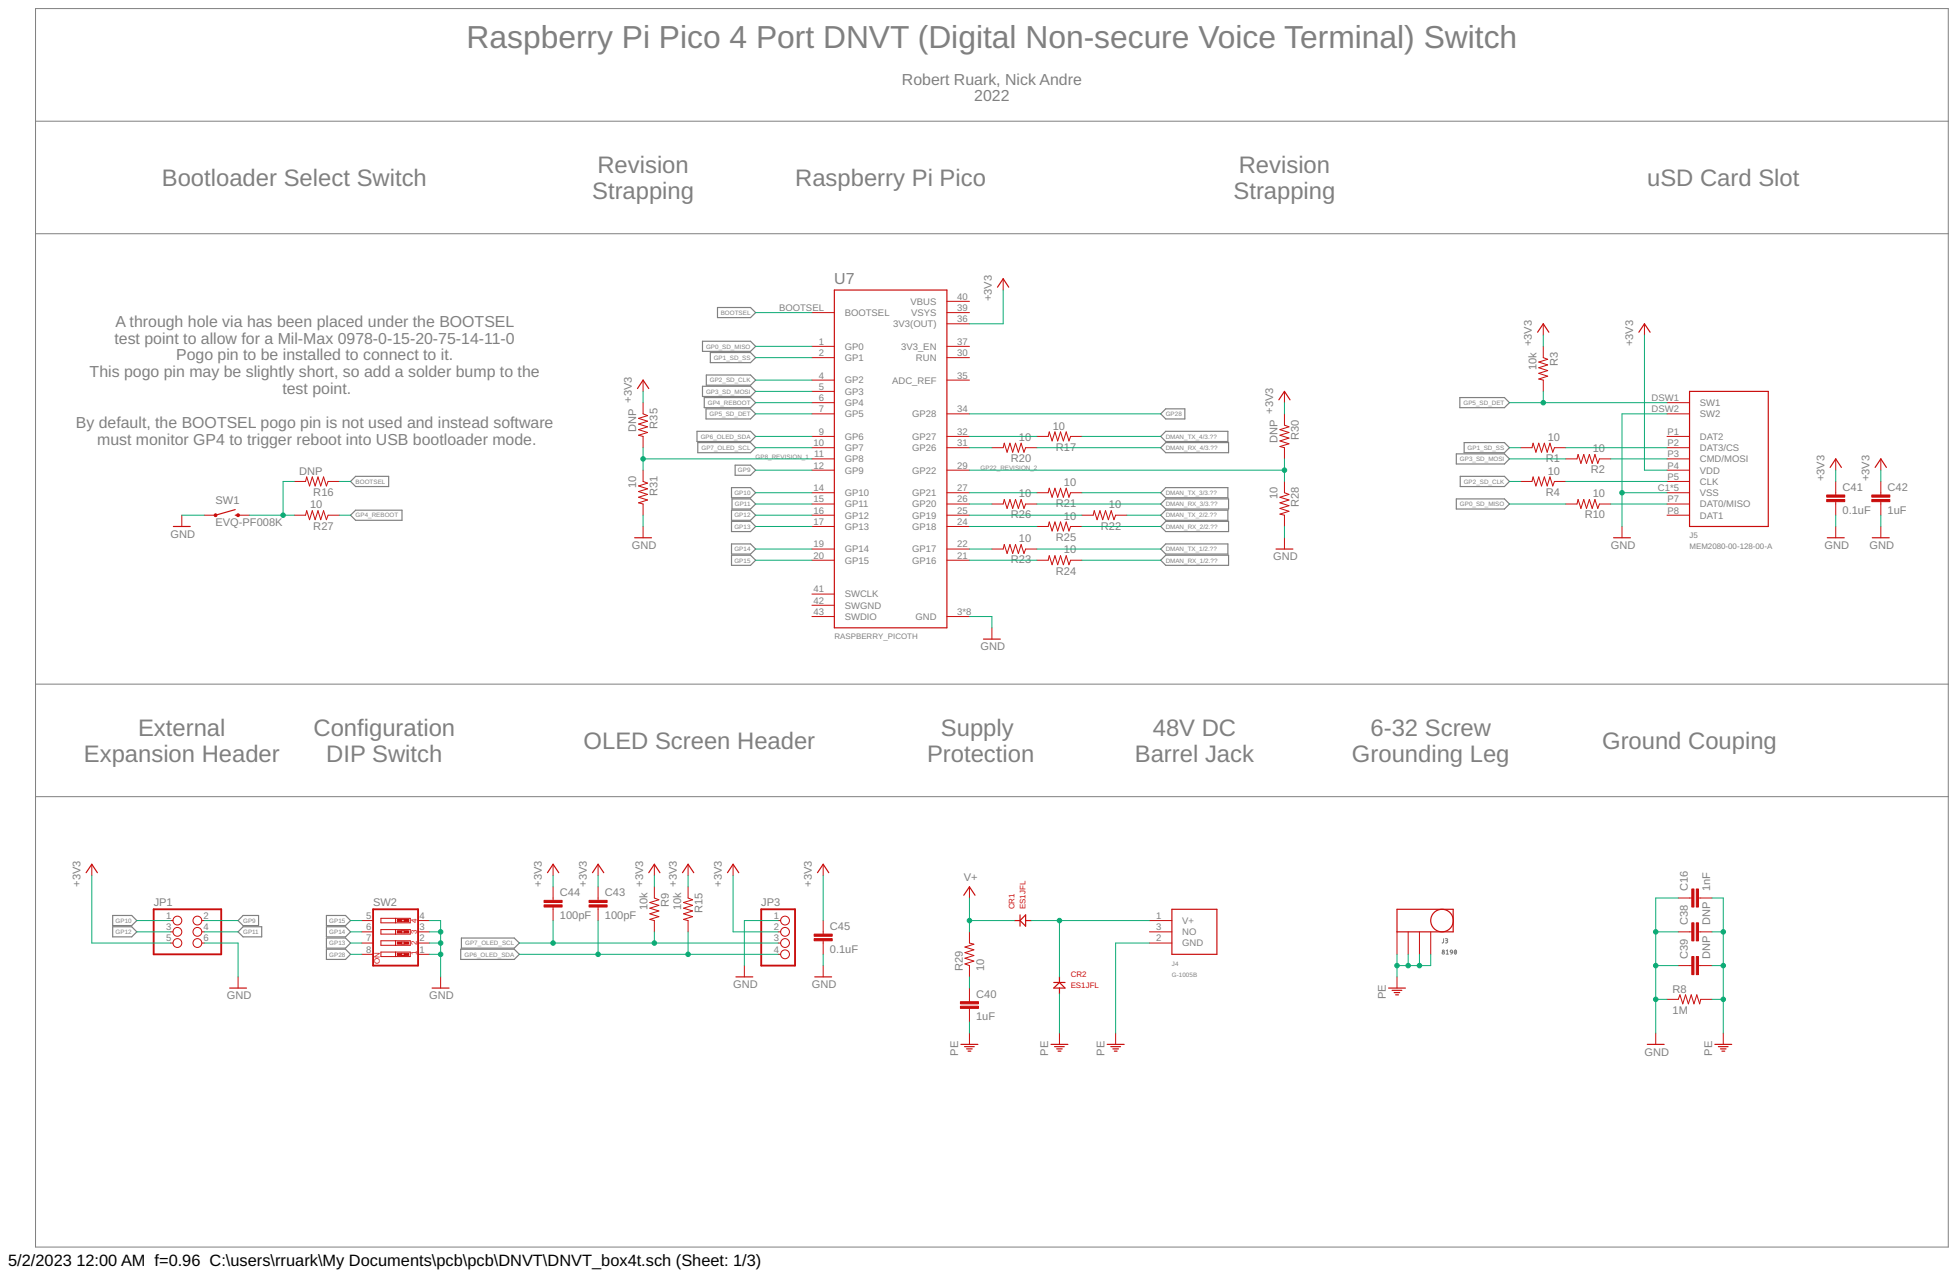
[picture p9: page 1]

Raspberry Pi Pico 4 Port DNVT (Digital Non-secure Voice Terminal) Switch

Robert Ruark, Nick Andre

A through hole via has been placed under the BOOTSEL
test point to allow for a Mil-Max 0978-0-15-20-75-14-11-0
Pogo pin to be installed to connect to it. This pogo pin may be slightly short, so add a solder bump to the

test point. By default, the BOOTSEL pogo pin is not used and instead software

must monitor GP4 to trigger reboot into USB bootloader mode.

5/2/2023 12:00 AM f=0.96 C:\users\rruark\My Documents\pcb\pcb\DNVT\DNVT_box4t.sch (Sheet: 1/3)

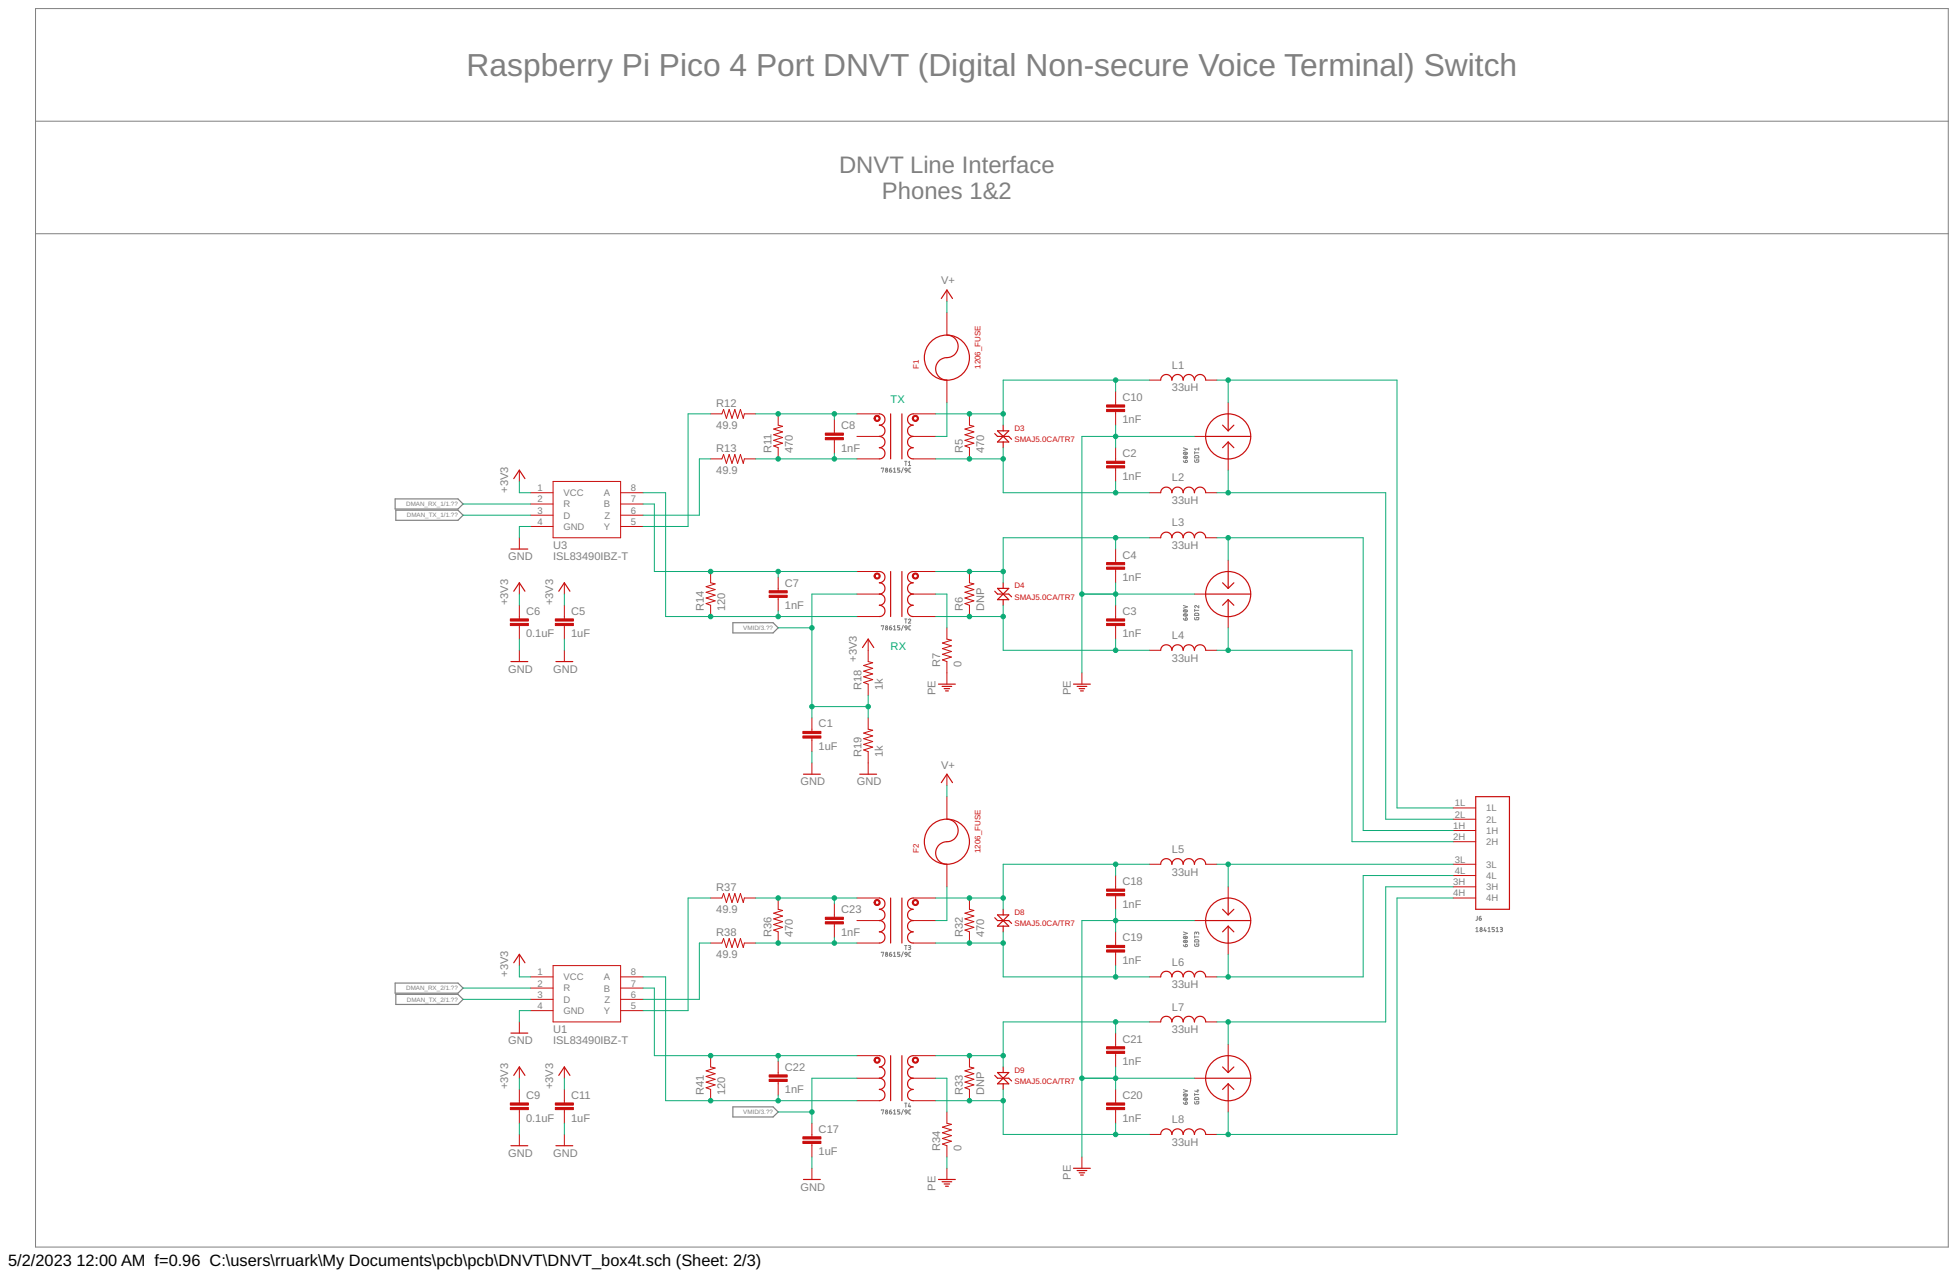
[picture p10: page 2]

5/2/2023 12:00 AM f=0.96 C:\users\rruark\My Documents\pcb\pcb\DNVT\DNVT_box4t.sch (Sheet: 2/3)

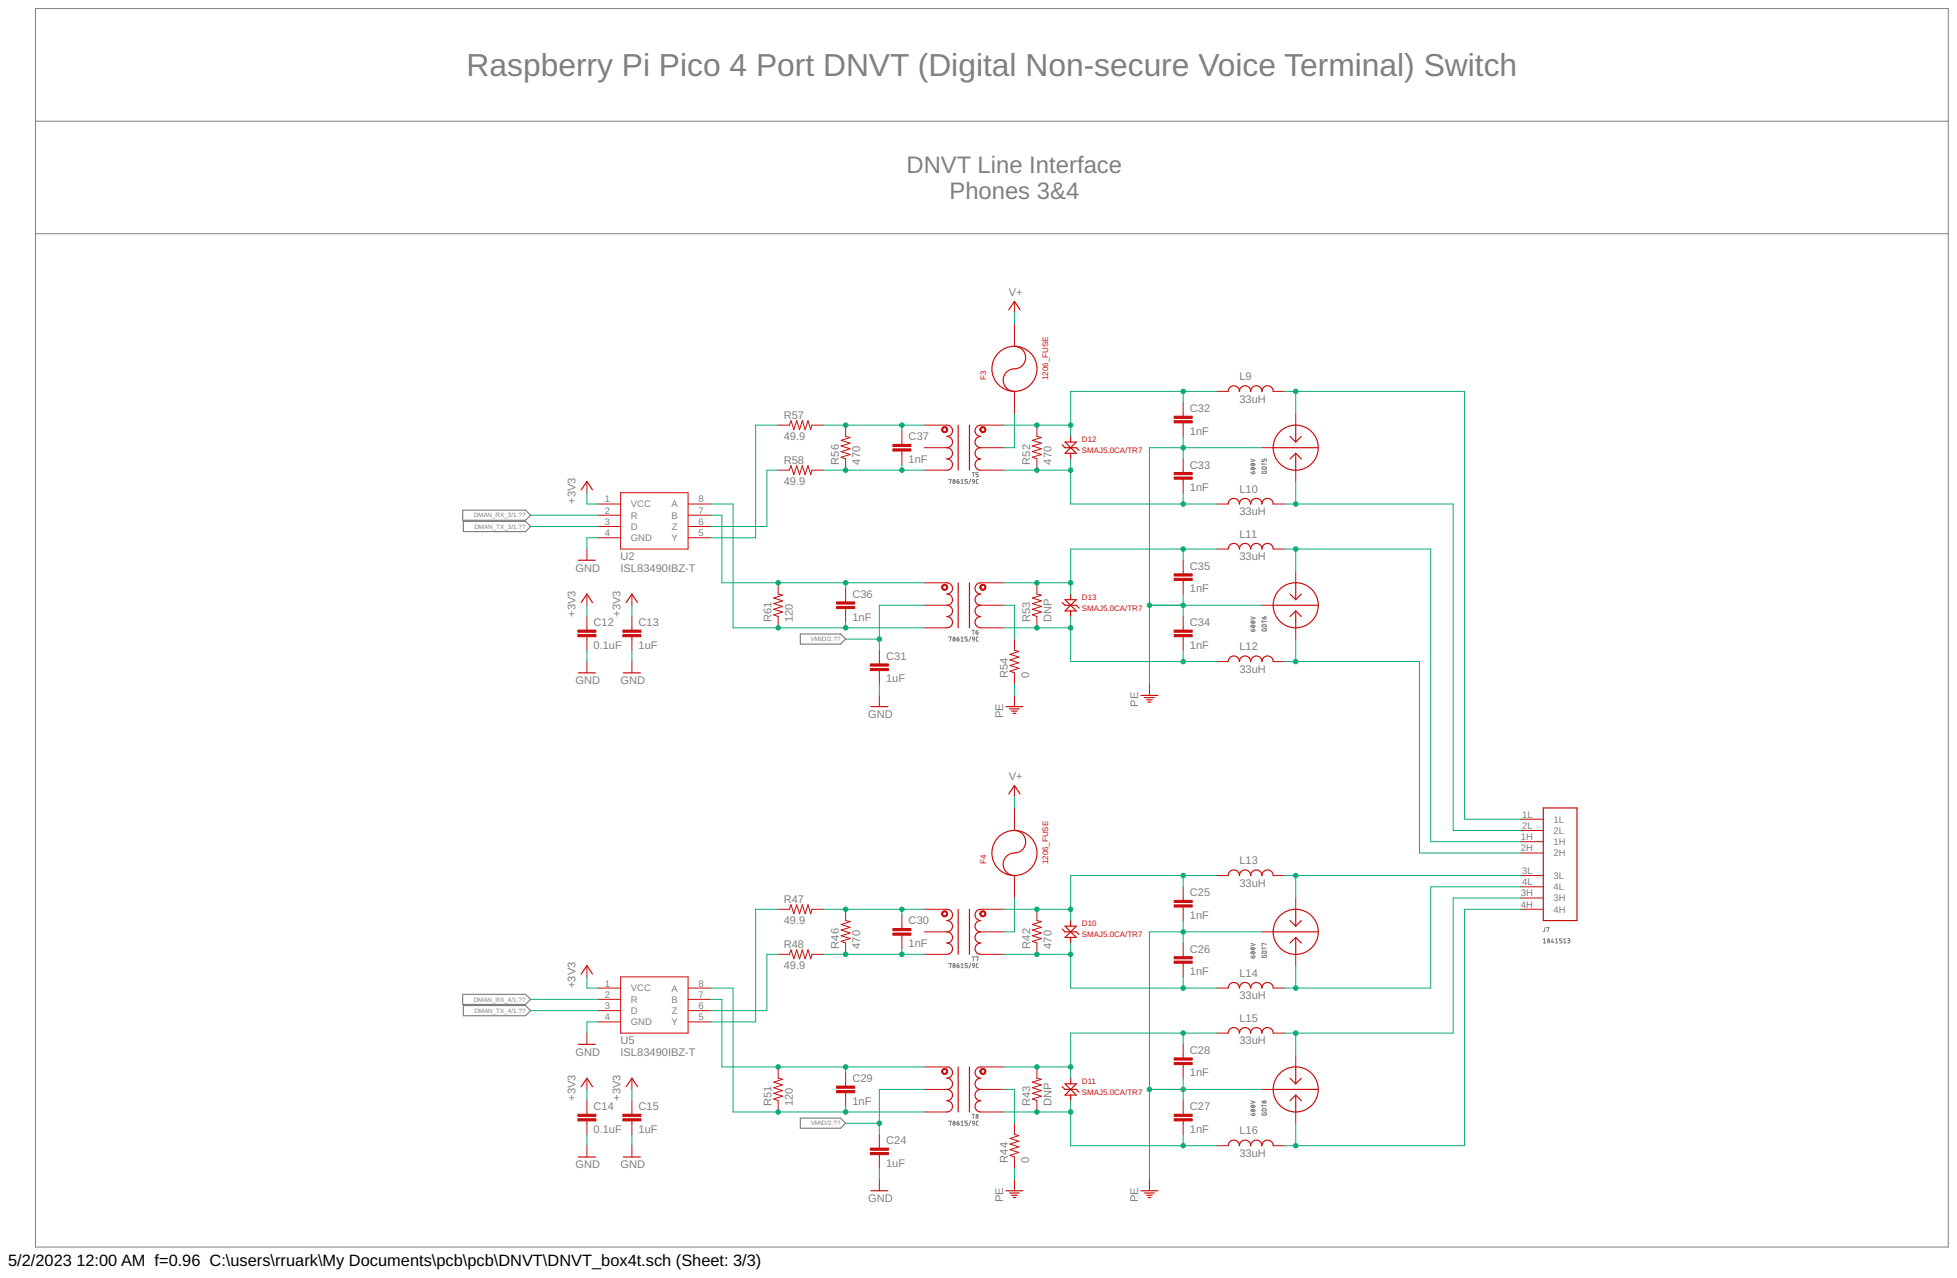
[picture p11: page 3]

5/2/2023 12:00 AM f=0.96 C:\users\rruark\My Documents\pcb\pcb\DNVT\DNVT_box4t.sch (Sheet: 3/3)

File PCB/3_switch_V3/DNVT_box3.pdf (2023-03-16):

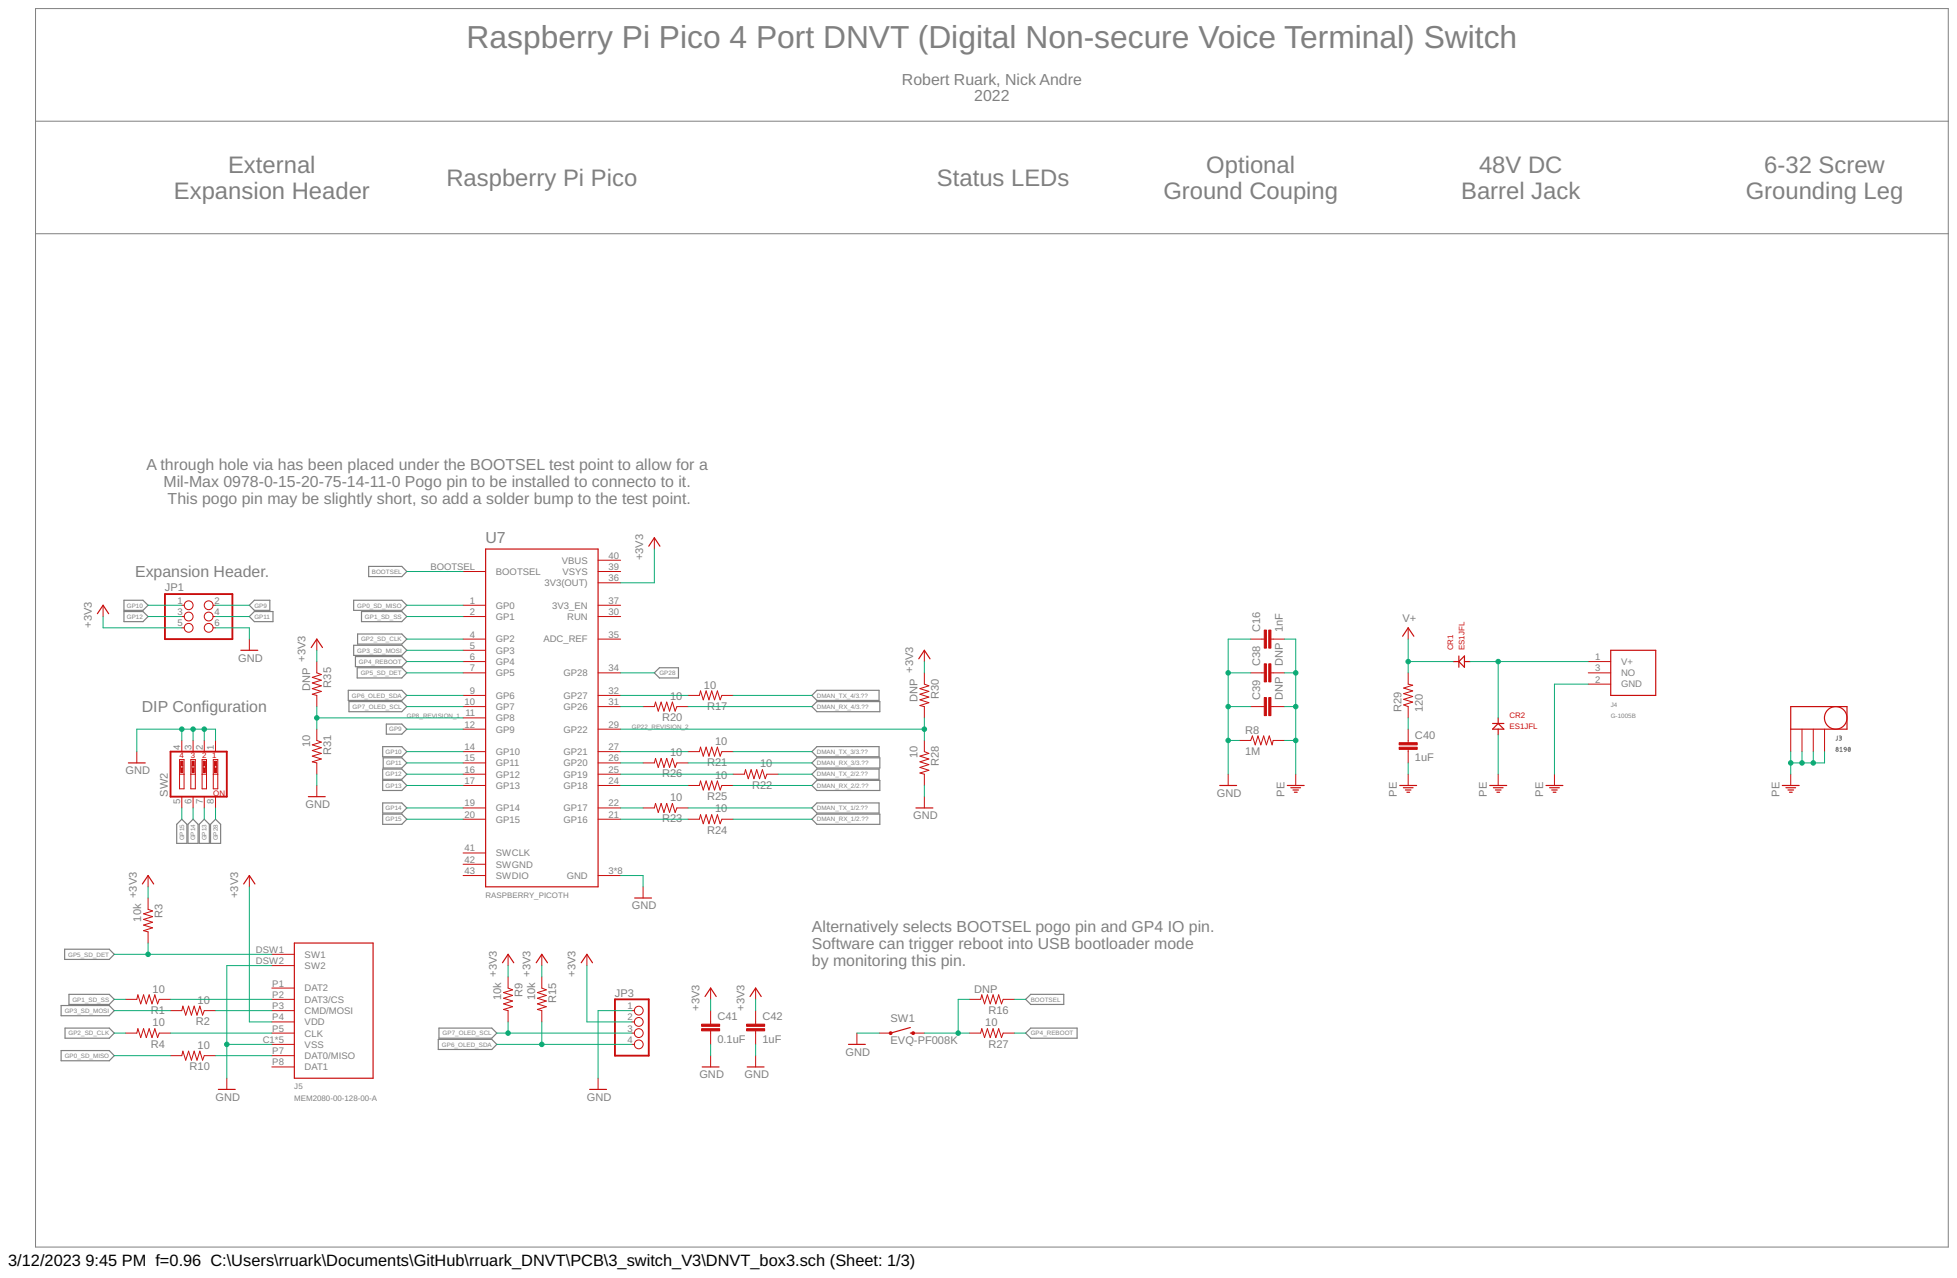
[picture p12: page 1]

Raspberry Pi Pico 4 Port DNVT (Digital Non-secure Voice Terminal) Switch

Robert Ruark, Nick Andre

A through hole via has been placed under the BOOTSEL test point to allow for a
Mil-Max 0978-0-15-20-75-14-11-0 Pogo pin to be installed to connecto to it. This pogo pin may be slightly short, so add a solder bump to the test point.

Alternatively selects BOOTSEL pogo pin and GP4 IO pin. Software can trigger reboot into USB bootloader mode

by monitoring this pin.

3/12/2023 9:45 PM f=0.96 C:\Users\rruark\Documents\GitHub\rruark_DNVT\PCB\3_switch_V3\DNVT_box3.sch (Sheet: 1/3)

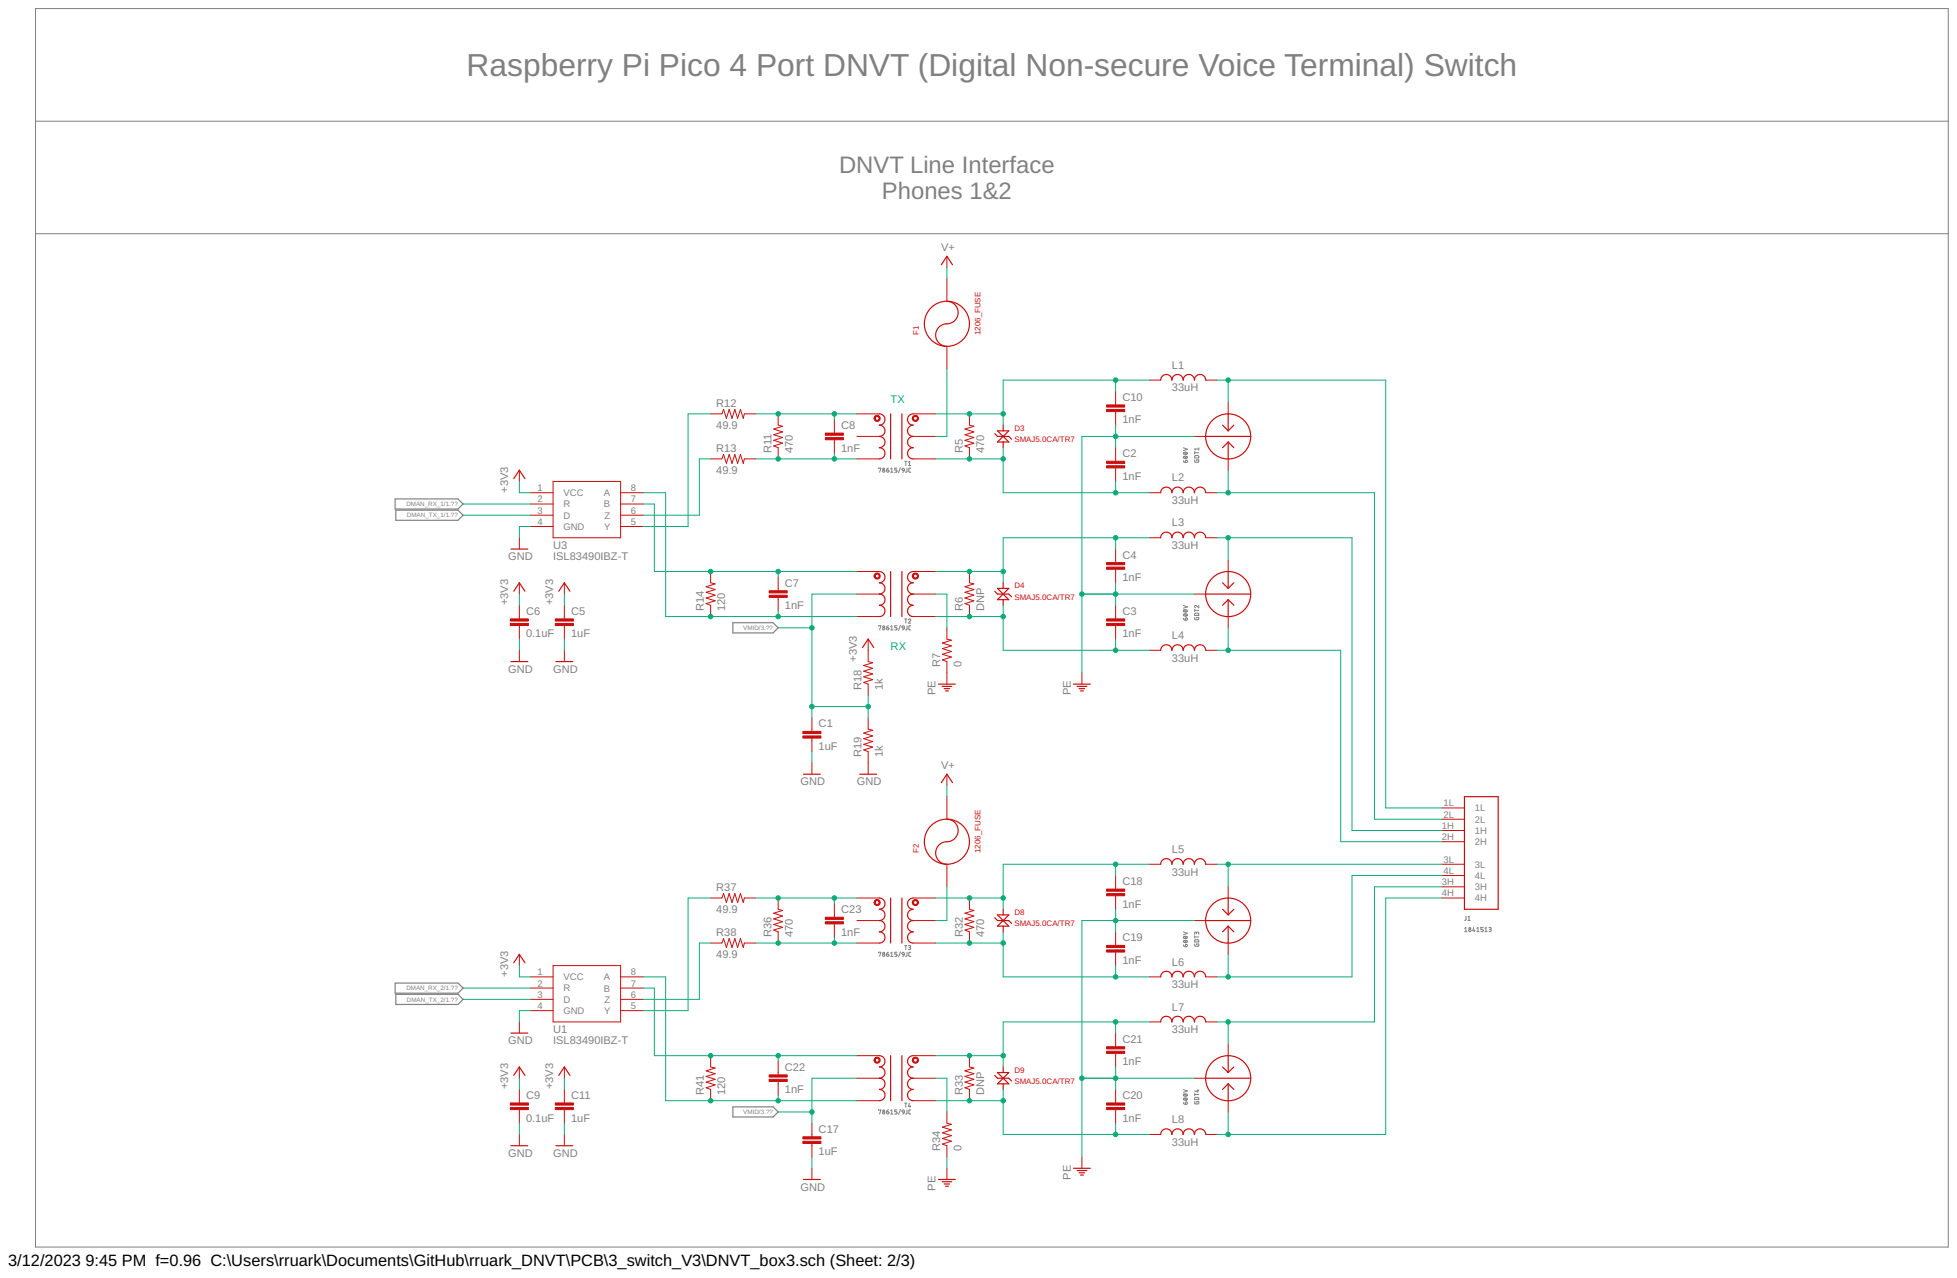
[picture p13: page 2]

3/12/2023 9:45 PM f=0.96 C:\Users\rruark\Documents\GitHub\rruark_DNVT\PCB\3_switch_V3\DNVT_box3.sch (Sheet: 2/3)

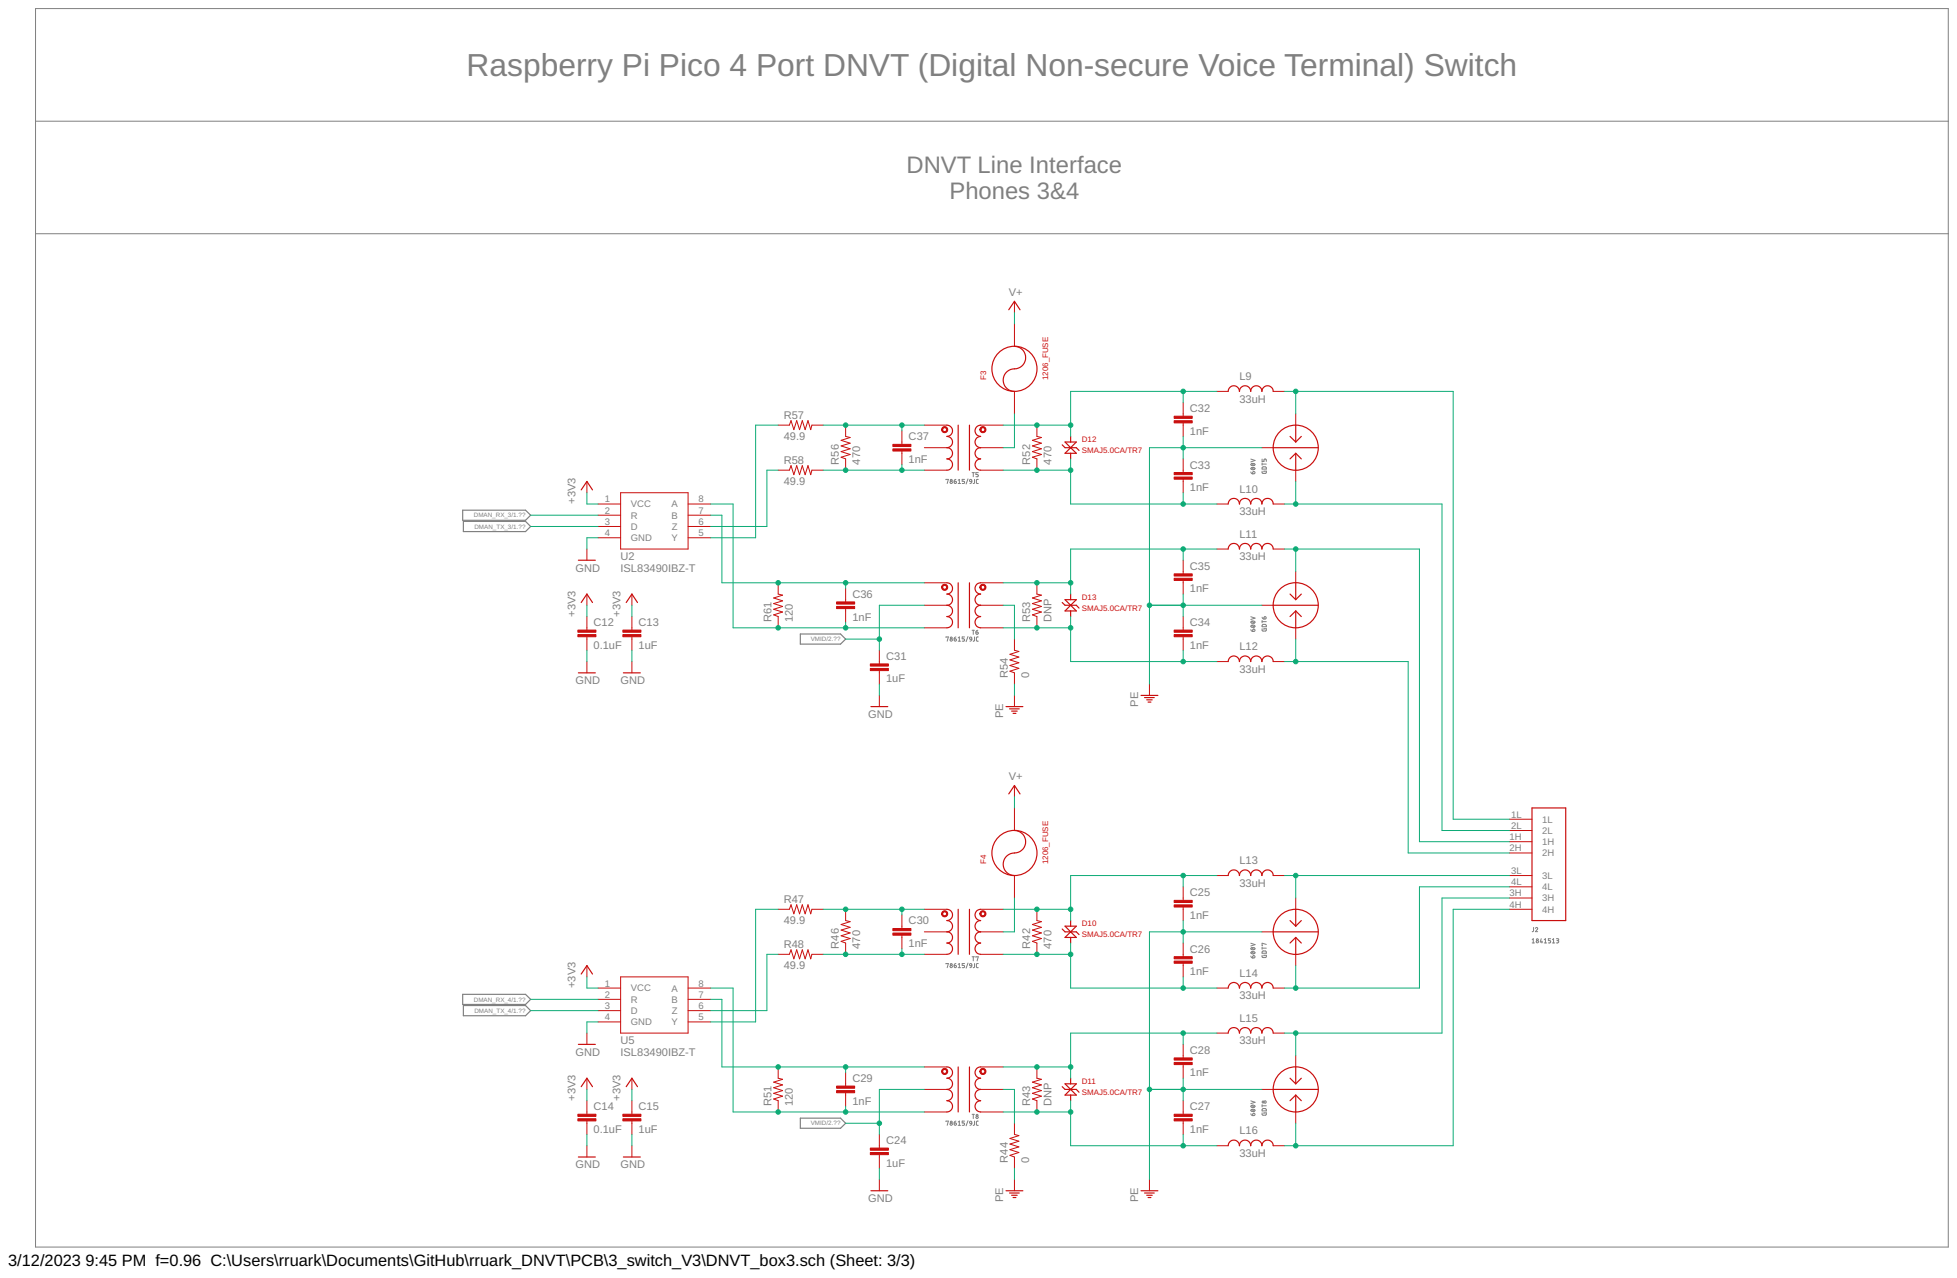
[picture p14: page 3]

3/12/2023 9:45 PM f=0.96 C:\Users\rruark\Documents\GitHub\rruark_DNVT\PCB\3_switch_V3\DNVT_box3.sch (Sheet: 3/3)

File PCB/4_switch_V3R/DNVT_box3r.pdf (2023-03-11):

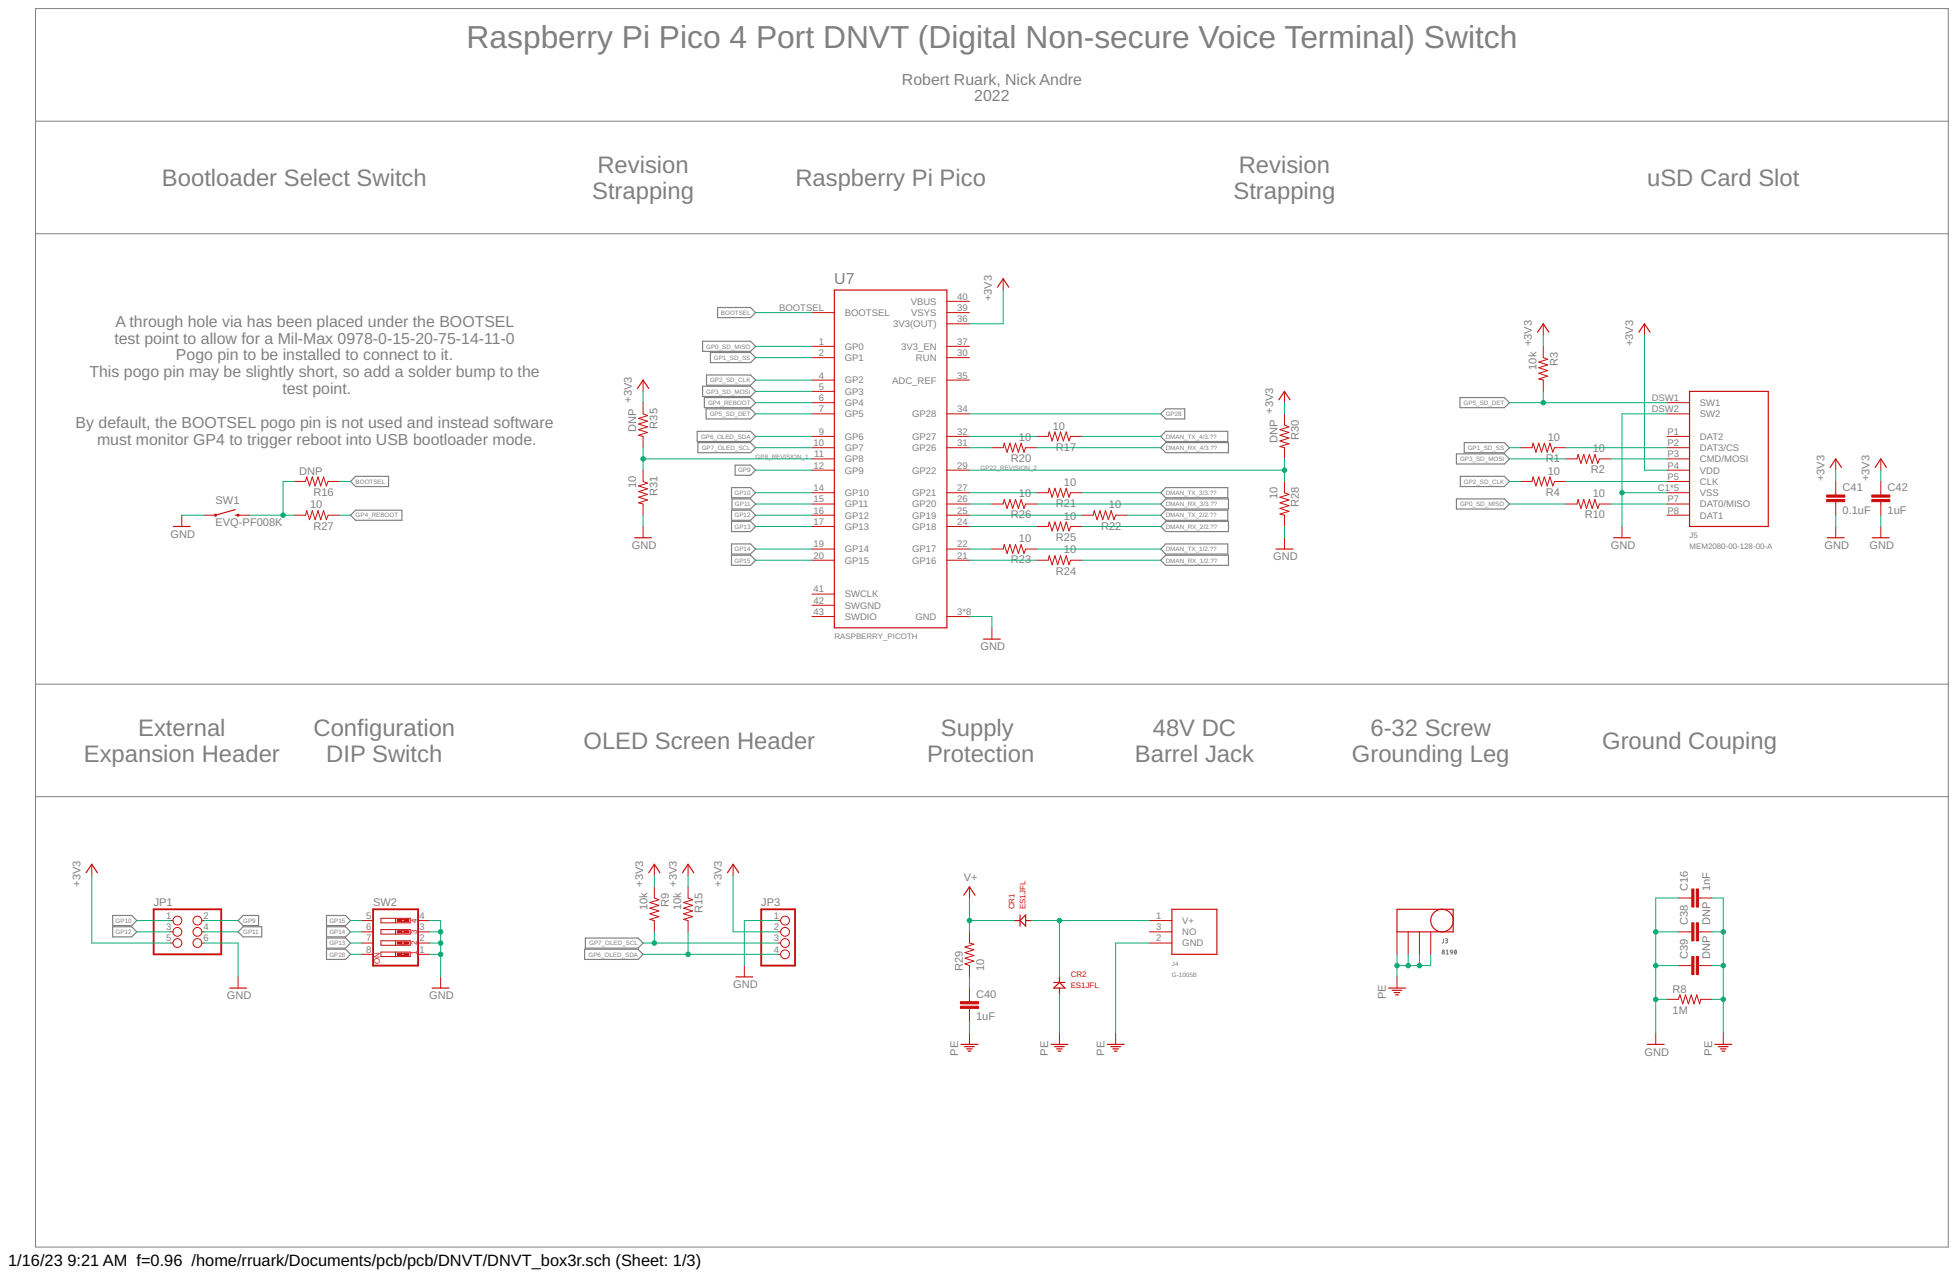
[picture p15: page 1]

Raspberry Pi Pico 4 Port DNVT (Digital Non-secure Voice Terminal) Switch

Robert Ruark, Nick Andre

A through hole via has been placed under the BOOTSEL
test point to allow for a Mil-Max 0978-0-15-20-75-14-11-0
Pogo pin to be installed to connect to it. This pogo pin may be slightly short, so add a solder bump to the
test point. By default, the BOOTSEL pogo pin is not used and instead software

must monitor GP4 to trigger reboot into USB bootloader mode.

1/16/23 9:21 AM f=0.96 /home/rruark/Documents/pcb/pcb/DNVT/DNVT_box3r.sch (Sheet: 1/3)

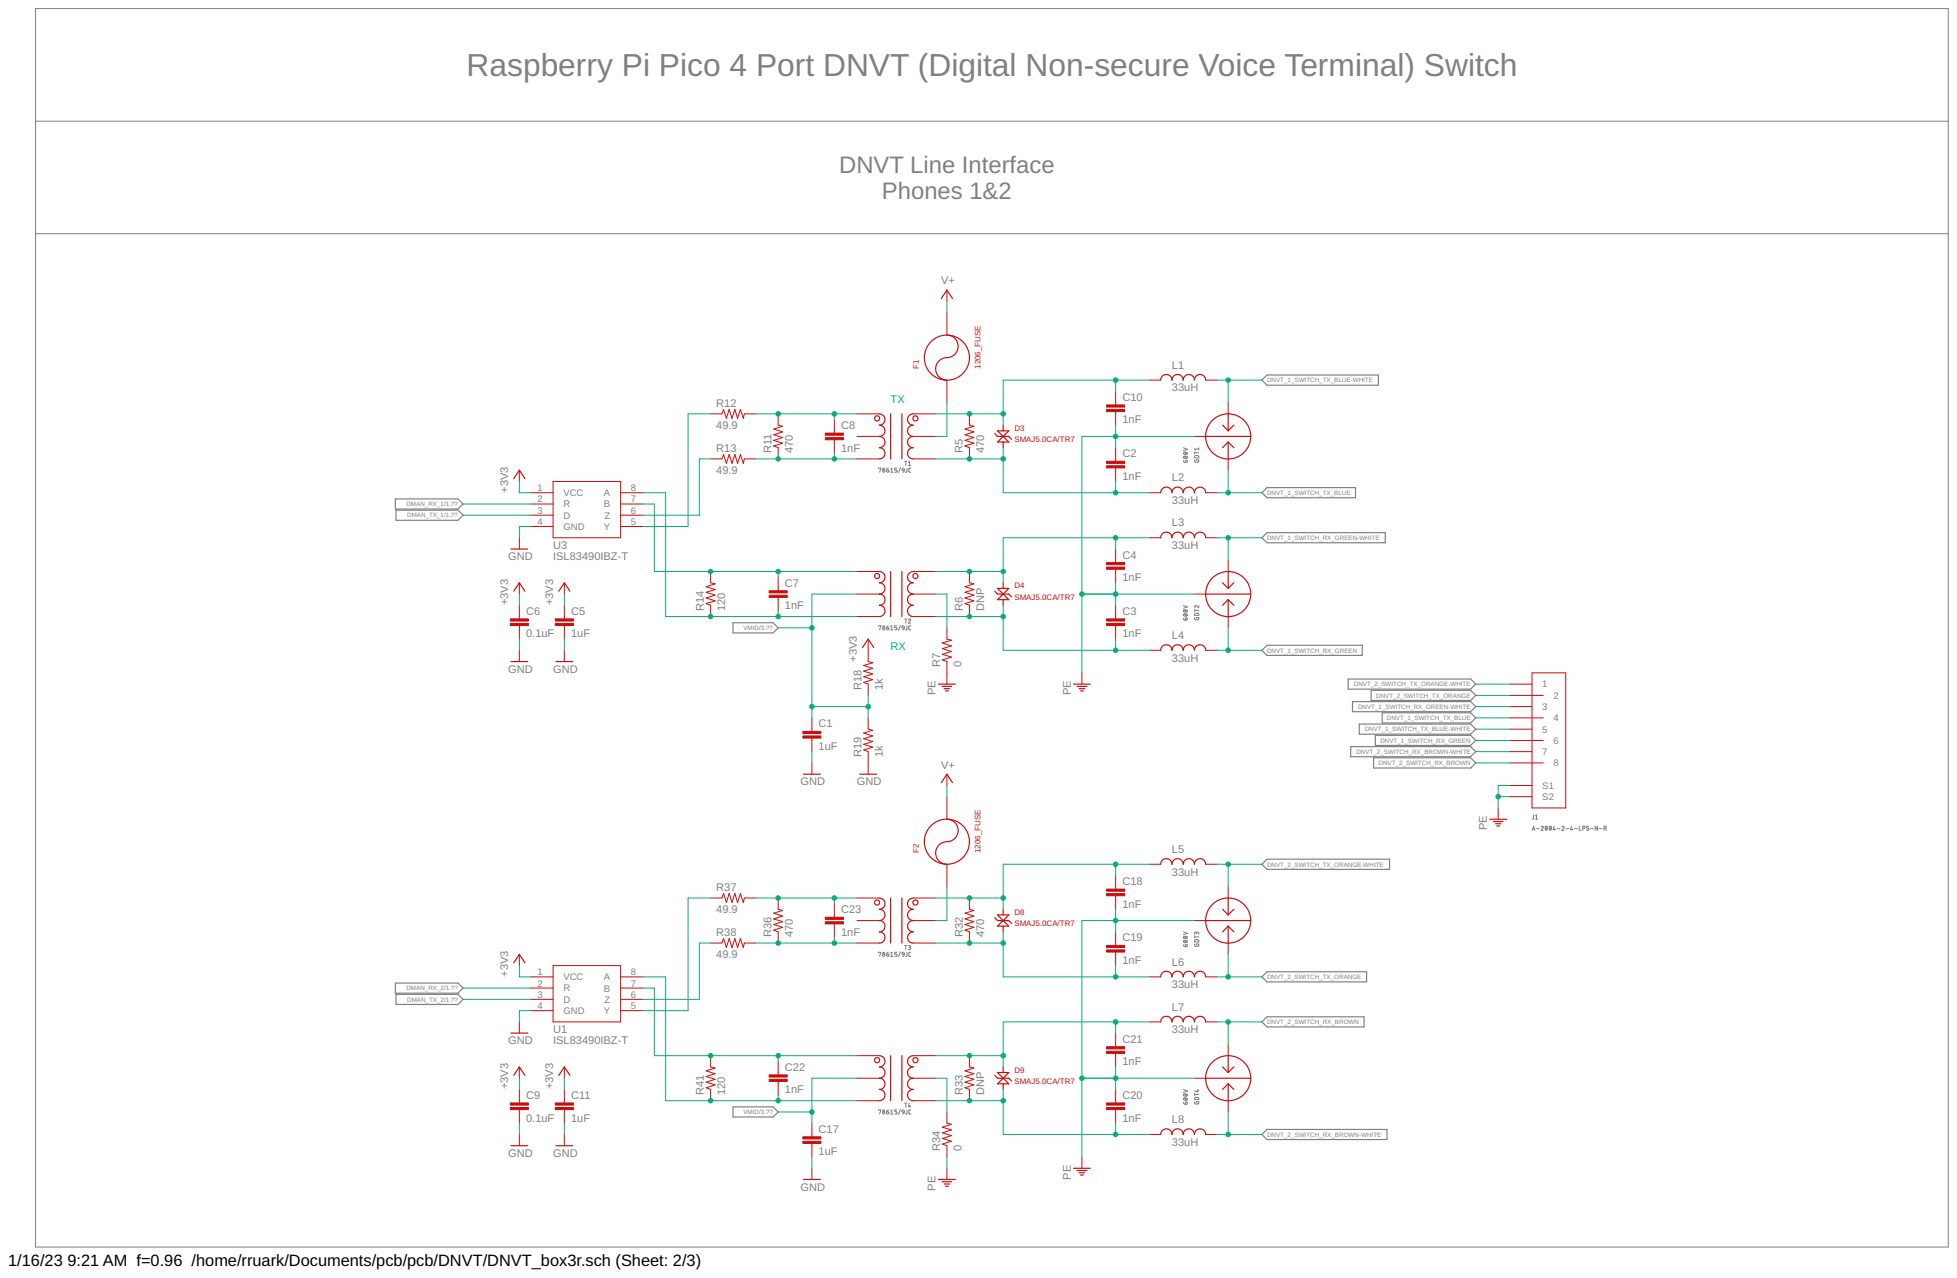
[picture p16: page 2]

1/16/23 9:21 AM f=0.96 /home/rruark/Documents/pcb/pcb/DNVT/DNVT_box3r.sch (Sheet: 2/3)

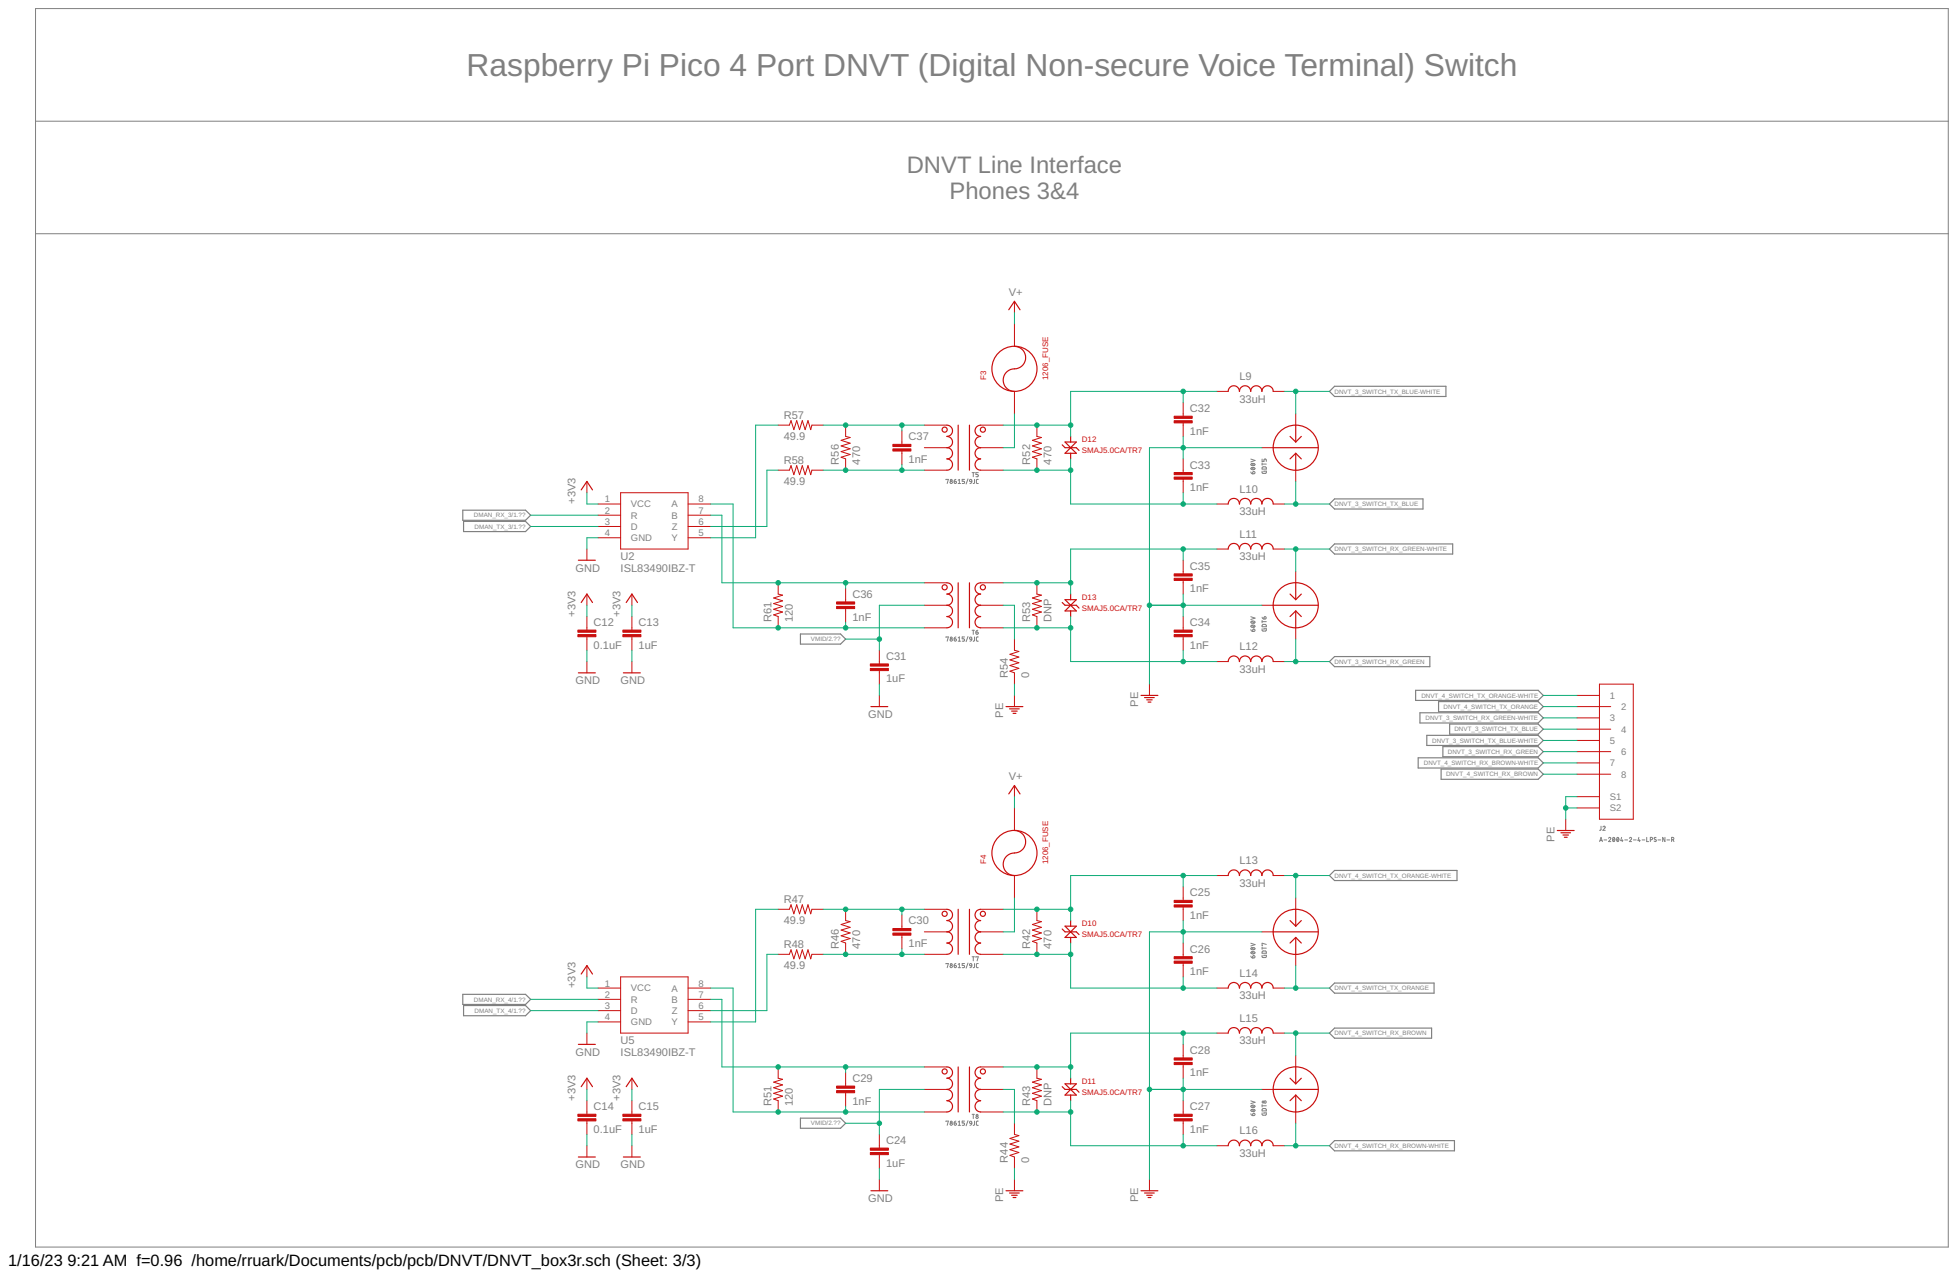
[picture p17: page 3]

1/16/23 9:21 AM f=0.96 /home/rruark/Documents/pcb/pcb/DNVT/DNVT_box3r.sch (Sheet: 3/3)

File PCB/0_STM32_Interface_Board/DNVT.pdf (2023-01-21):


1/21/2023 10:49 AM C:\Users\rruark\Documents\GitHub\rruark_DNVT\PCB\0_STM32_Interface_Board\DNVT.sch (Sheet: 1/1)

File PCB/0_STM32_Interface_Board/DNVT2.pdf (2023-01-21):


1/21/2023 10:50 AM f=0.94 C:\Users\rruark\Documents\GitHub\rruark_DNVT\PCB\0_STM32_Interface_Board\DNVT2.sch (Sheet: 1/1)

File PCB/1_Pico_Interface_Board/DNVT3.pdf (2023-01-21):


NOTE: The 5V net is actually 3.3V

This is a leftover from using a 5V line driver. Configurable LEDs for debugging

This board can be used in master mode or in slave mode depending on whether or not the Raspberry Pi Pico is installed. When the Pico is installed, the board is in master mode and when it is not installed the board is in slave mode. Each board has one line driver and set of transformers to interface with a phone. P1 is connected to this line driver. Connector P1 on boards in slave mode is connected to connectors P2-P4 on the master board. This allows the Pico on the Master board to use the line drivers of the slave boards so that a single Pico can interface with four phones. Slave boards are powered through these headers.

Expansion Header. This has all the pins needed to

Line Driver and Common Battery Power Injection

10/30/2022 1:16 PM f=0.96 C:\EAGLE-7.2.0\DNVT\DNVT3.sch (Sheet: 1/1)

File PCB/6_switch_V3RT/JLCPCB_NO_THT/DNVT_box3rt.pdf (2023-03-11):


Raspberry Pi Pico 4 Port DNVT (Digital Non-secure Voice Terminal) Switch

Robert Ruark, Nick Andre

A through hole via has been placed under the BOOTSEL
test point to allow for a Mil-Max 0978-0-15-20-75-14-11-0
Pogo pin to be installed to connect to it. This pogo pin may be slightly short, so add a solder bump to the

test point. By default, the BOOTSEL pogo pin is not used and instead software

must monitor GP4 to trigger reboot into USB bootloader mode.

2/20/2023 6:14 PM f=0.96 C:\users\rruark\My Documents\pcb\pcb\DNVT\DNVT_box3rt.sch (Sheet: 1/3)


2/20/2023 6:14 PM f=0.96 C:\users\rruark\My Documents\pcb\pcb\DNVT\DNVT_box3rt.sch (Sheet: 2/3)


2/20/2023 6:14 PM f=0.96 C:\users\rruark\My Documents\pcb\pcb\DNVT\DNVT_box3rt.sch (Sheet: 3/3)

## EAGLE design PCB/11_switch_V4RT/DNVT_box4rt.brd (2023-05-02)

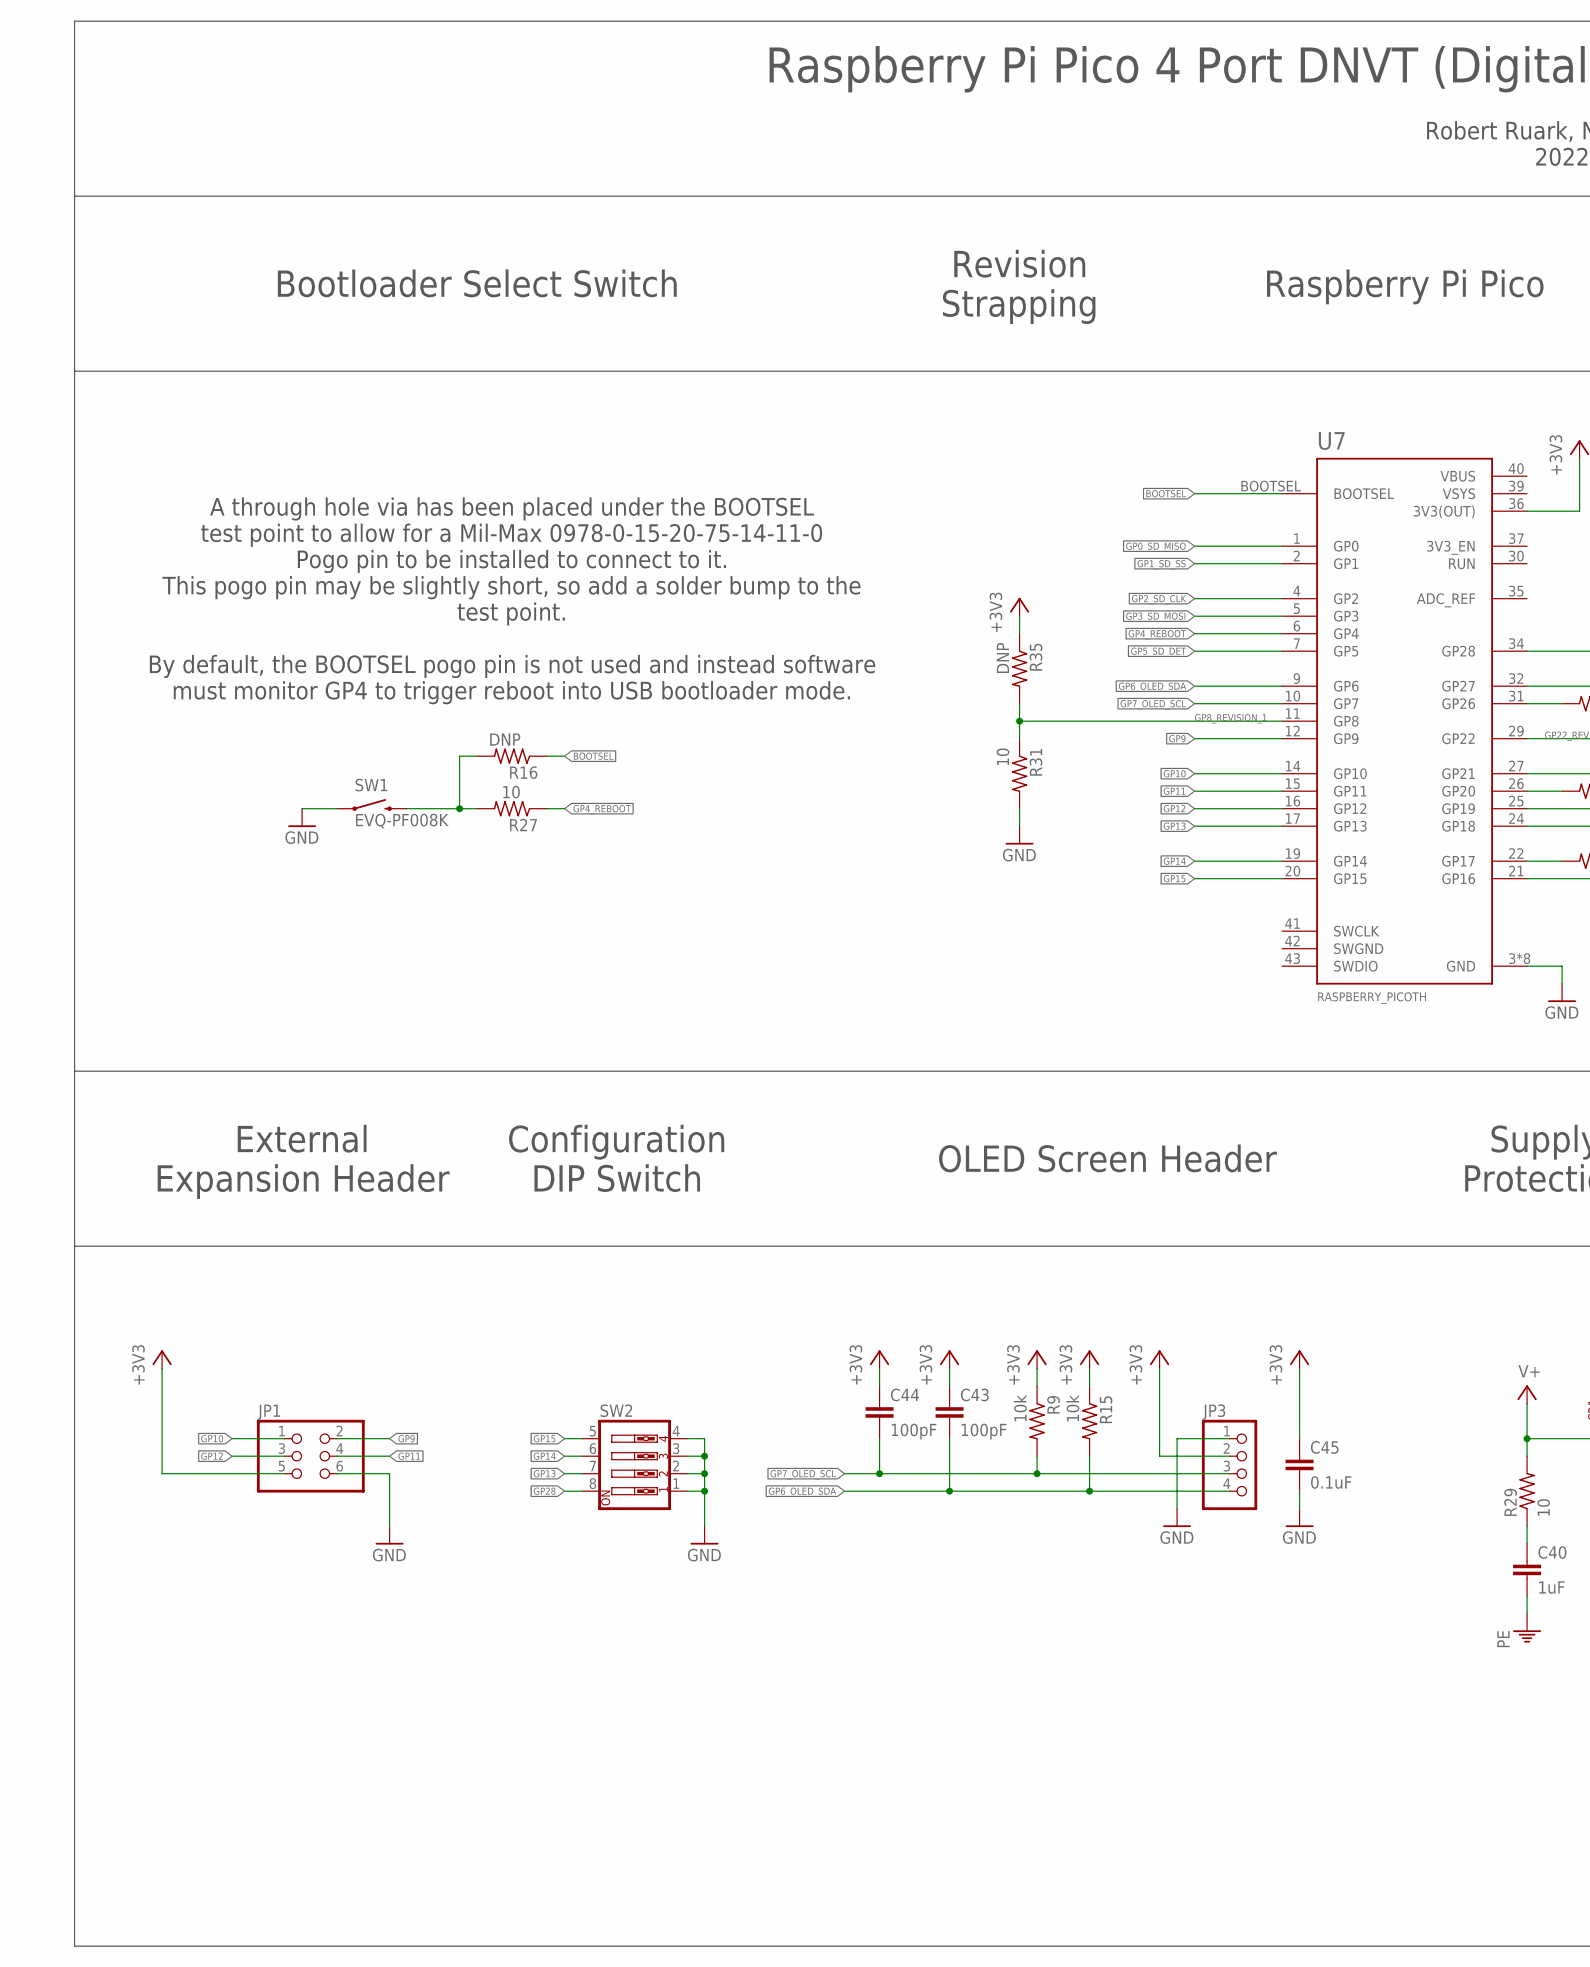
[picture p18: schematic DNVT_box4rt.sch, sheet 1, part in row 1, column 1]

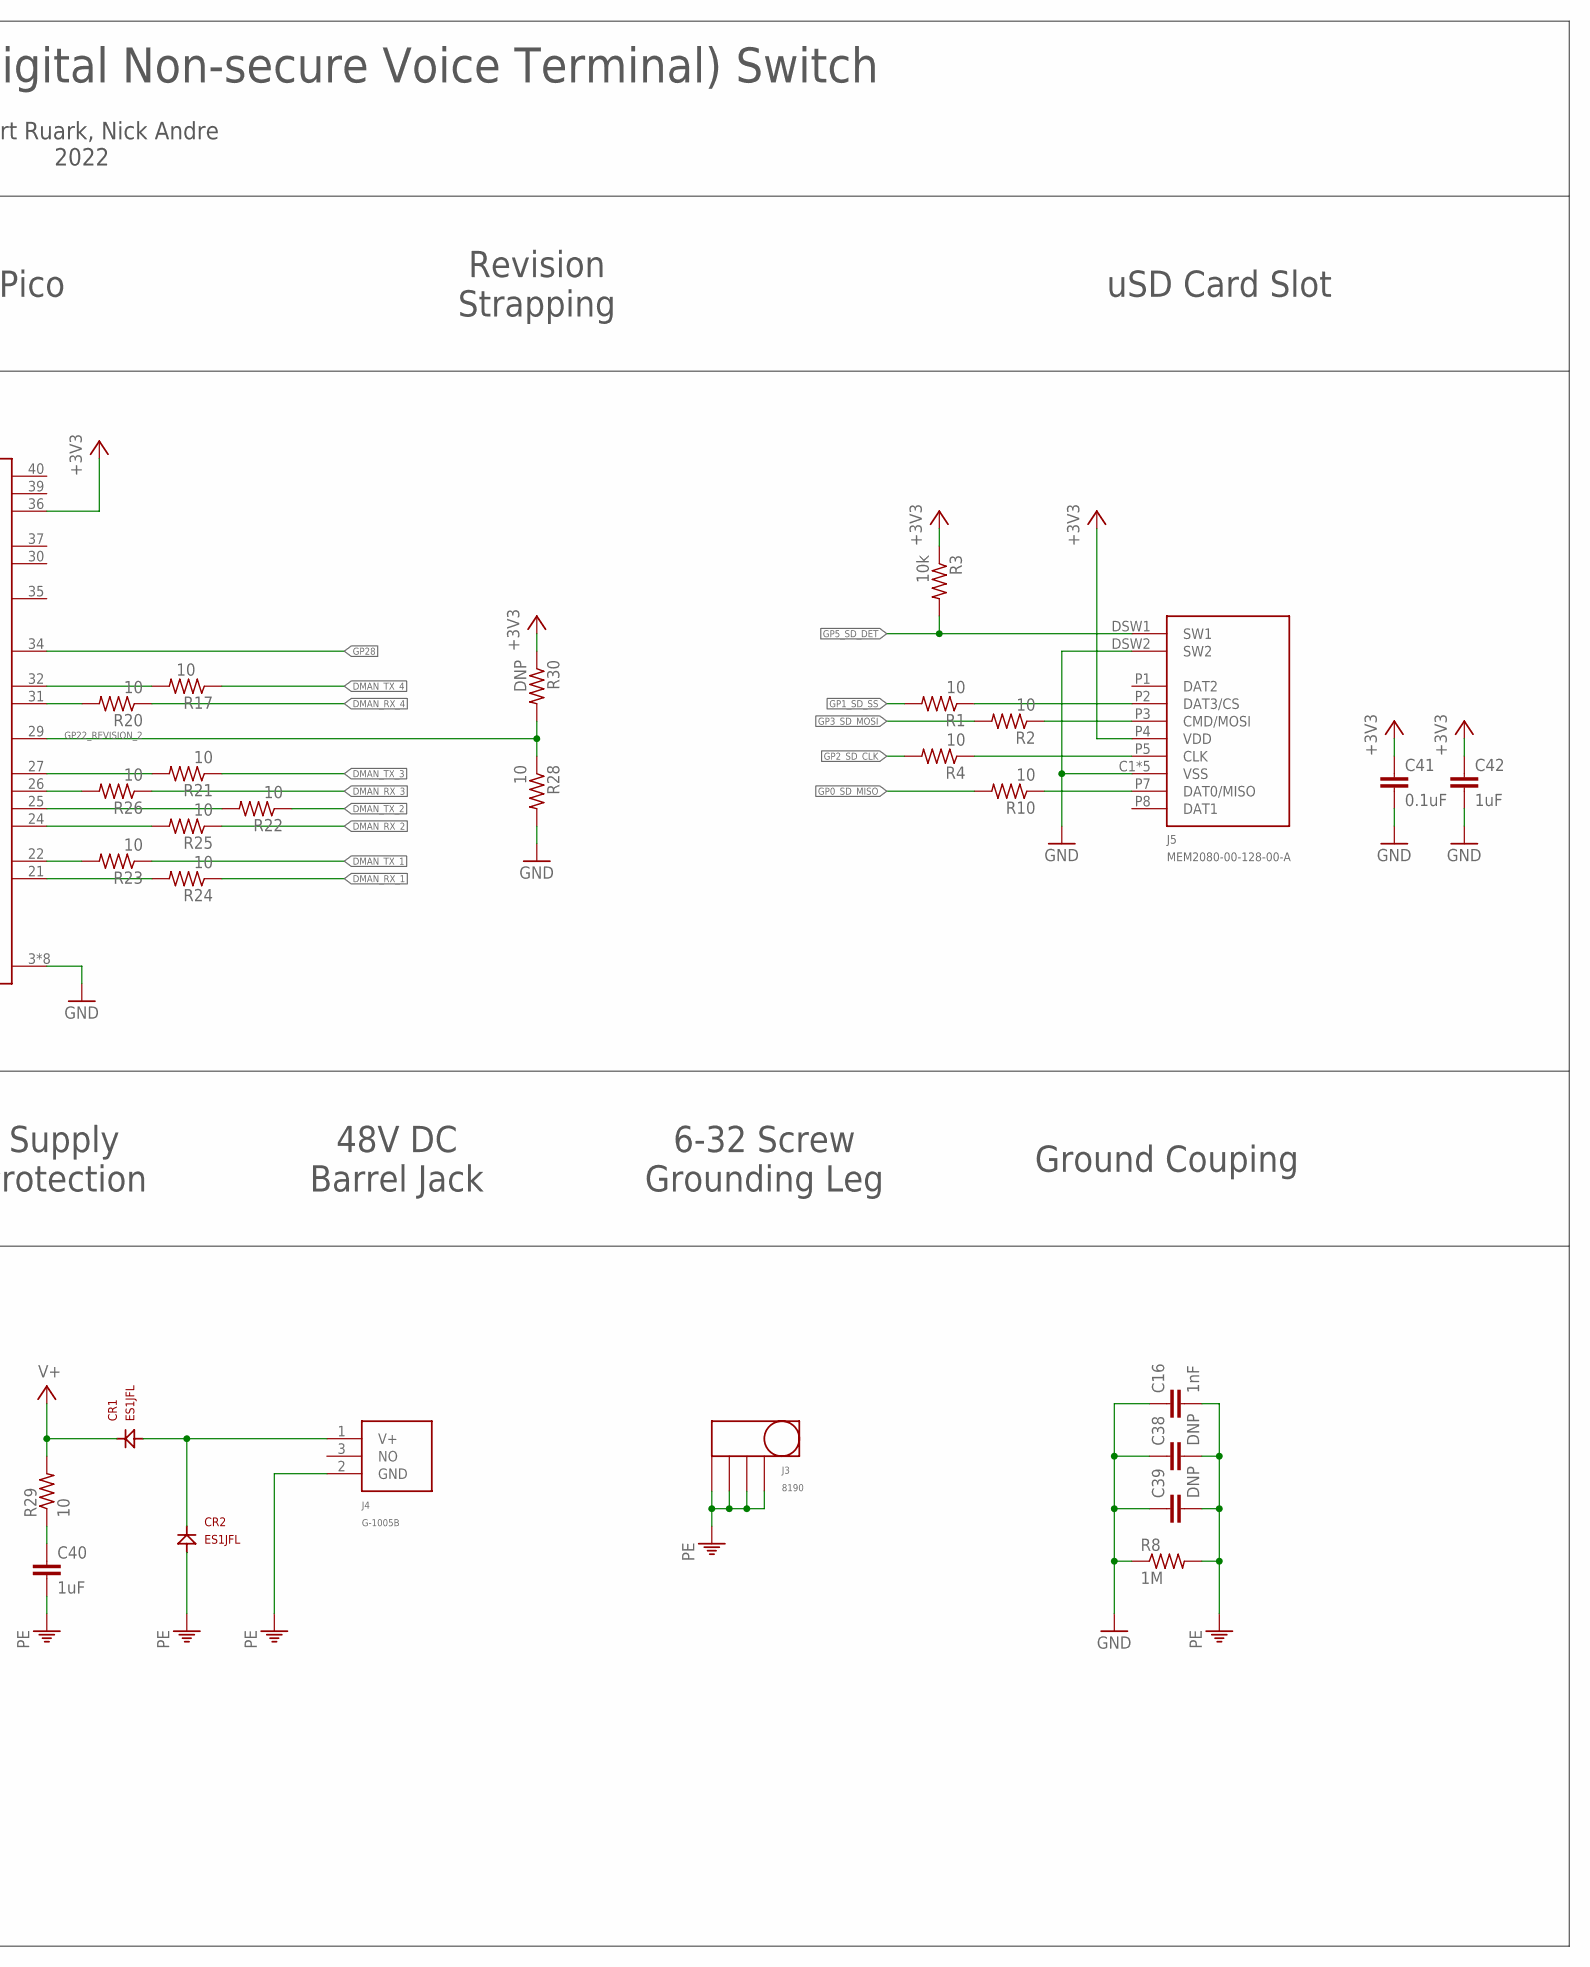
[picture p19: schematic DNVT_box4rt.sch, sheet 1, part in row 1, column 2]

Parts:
C16: 1nF; 1206
C38, C39: DNP; 1206
C40: 1uF; 1206
C41, C45: 0.1uF; 0603
C42: 1uF; 0805
C43, C44: 100pF; 0603
CR1, CR2: ES1JFL; SOD123(AK)
J3: 8190; 7781
J4: G-1005B
J5: MEM2080-00-128-00-A; MEM2080
JP1: PINHD-2X3/90; 2X03/90
JP3: PINHD-1X4; 1X04
R1, R2, R4, R10, R17, R20, R21, R22, R23, R24, R25, R26, R27, R28, R31: 10; 0603
R3, R9, R15: 10k; 0603
R8: 1M; 1206
R16, R30, R35: DNP; 0603
R29: 10; 1206
SW1: EVQ-PF008K
SW2: SW_DIP-4; EDG-04
U7: RASPBERRY_PICOTH; PICO-PKG-TH

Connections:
+3V3: C41.1, C42.1, C43.1, C44.1, C45.1, J5.P4 (VDD), JP1.5, JP3.2, R3.1, R9.1, R15.1, R30.1, R35.1, U7.36 (3V3(OUT)); also elsewhere on the board
BOOTSEL: R16.1, U7.BOOTSEL
DMAN_RX_1: R24.1; also elsewhere on the board
DMAN_RX_2: R25.1; also elsewhere on the board
DMAN_RX_3: R26.1; also elsewhere on the board
DMAN_RX_4: R20.1; also elsewhere on the board
DMAN_TX_1: R23.1; also elsewhere on the board
DMAN_TX_2: R22.1; also elsewhere on the board
DMAN_TX_3: R21.1; also elsewhere on the board
DMAN_TX_4: R17.1; also elsewhere on the board
GND: C16.1, C38.1, C39.1, C41.2, C42.2, C45.2, J5.C1 (VSS), J5.C2 (VSS), J5.C3 (VSS), J5.C4 (VSS), J5.DSW2 (SW2), J5.P6 (VSS), JP1.6, JP3.1, R8.1, R28.2, R31.2, SW1.S1 (1), SW2.1, SW2.2, SW2.3, SW2.4, U7.3 (GND), U7.8 (GND), U7.13 (GND), U7.18 (GND), U7.23 (GND), U7.28 (GND), U7.33 (GND), U7.38 (GND); also elsewhere on the board
GP0_SD_MISO: R10.2, U7.1 (GP0)
GP1_SD_SS: R1.2, U7.2 (GP1)
GP2_SD_CLK: R4.2, U7.4 (GP2)
GP3_SD_MOSI: R2.2, U7.5 (GP3)
GP4_REBOOT: R27.1, U7.6 (GP4)
GP5_SD_DET: J5.DSW1 (SW1), R3.2, U7.7 (GP5)
GP6_OLED_SDA: C43.2, JP3.4, R15.2, U7.9 (GP6)
GP7_OLED_SCL: C44.2, JP3.3, R9.2, U7.10 (GP7)
GP8_REVISION_1: R31.1, R35.2, U7.11 (GP8)
GP9: JP1.2, U7.12 (GP9)
GP10: JP1.1, U7.14 (GP10)
GP11: JP1.4, U7.15 (GP11)
GP12: JP1.3, U7.16 (GP12)
GP13: SW2.7, U7.17 (GP13)
GP14: SW2.6, U7.19 (GP14)
GP15: SW2.5, U7.20 (GP15)
GP22_REVISION_2: R28.1, R30.2, U7.29 (GP22)
GP28: SW2.8, U7.34 (GP28)
unnamed: R20.2, U7.31 (GP26)
unnamed: R17.2, U7.32 (GP27)
unnamed: R24.2, U7.21 (GP16)
unnamed: R23.2, U7.22 (GP17)
unnamed: R16.2, R27.2, SW1.S2 (2)
unnamed: CR1.A, CR2.K, J4.1 (V+)
unnamed: R25.2, U7.24 (GP18)
unnamed: R22.2, U7.25 (GP19)
unnamed: R21.2, U7.27 (GP21)
unnamed: R26.2, U7.26 (GP20)
unnamed: J5.P5 (CLK), R4.1
unnamed: C40.1, R29.1
unnamed: J5.P7 (DAT0/MISO), R10.1
unnamed: J5.P3 (CMD/MOSI), R2.1
unnamed: J5.P2 (DAT3/CS), R1.1
PE: C16.2, C38.2, C39.2, C40.2, CR2.A, J3.P$1, J3.P$2, J3.P$3, J3.P$4, J4.2 (GND), R8.2; also elsewhere on the board
SWGND: U7.42 (SWGND)
V+: CR1.K, R29.2; also elsewhere on the board
VBUS: U7.40 (VBUS)
VSYS: U7.39 (VSYS)

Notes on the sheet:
Raspberry Pi Pico 4 Port DNVT (Digital Non-secure Voice Terminal) Switch
Robert Ruark, Nick Andre 2022
Raspberry Pi Pico
Ground Couping
External Expansion Header
OLED Screen Header
48V DC Barrel Jack
6-32 Screw Grounding Leg
A through hole via has been placed under the BOOTSEL test point to allow for a Mil-Max 0978-0-15-20-75-14-11-0 Pogo pin to be installed to connect to it. This pogo pin may be slightly short, so add a solder bump to the test point. By default, the BOOTSEL pogo pin is not used and instead software mu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
Configuration DIP Switch
Supply Protection
Revision Strapping
Bootloader Select Switch
uSD Card Slot

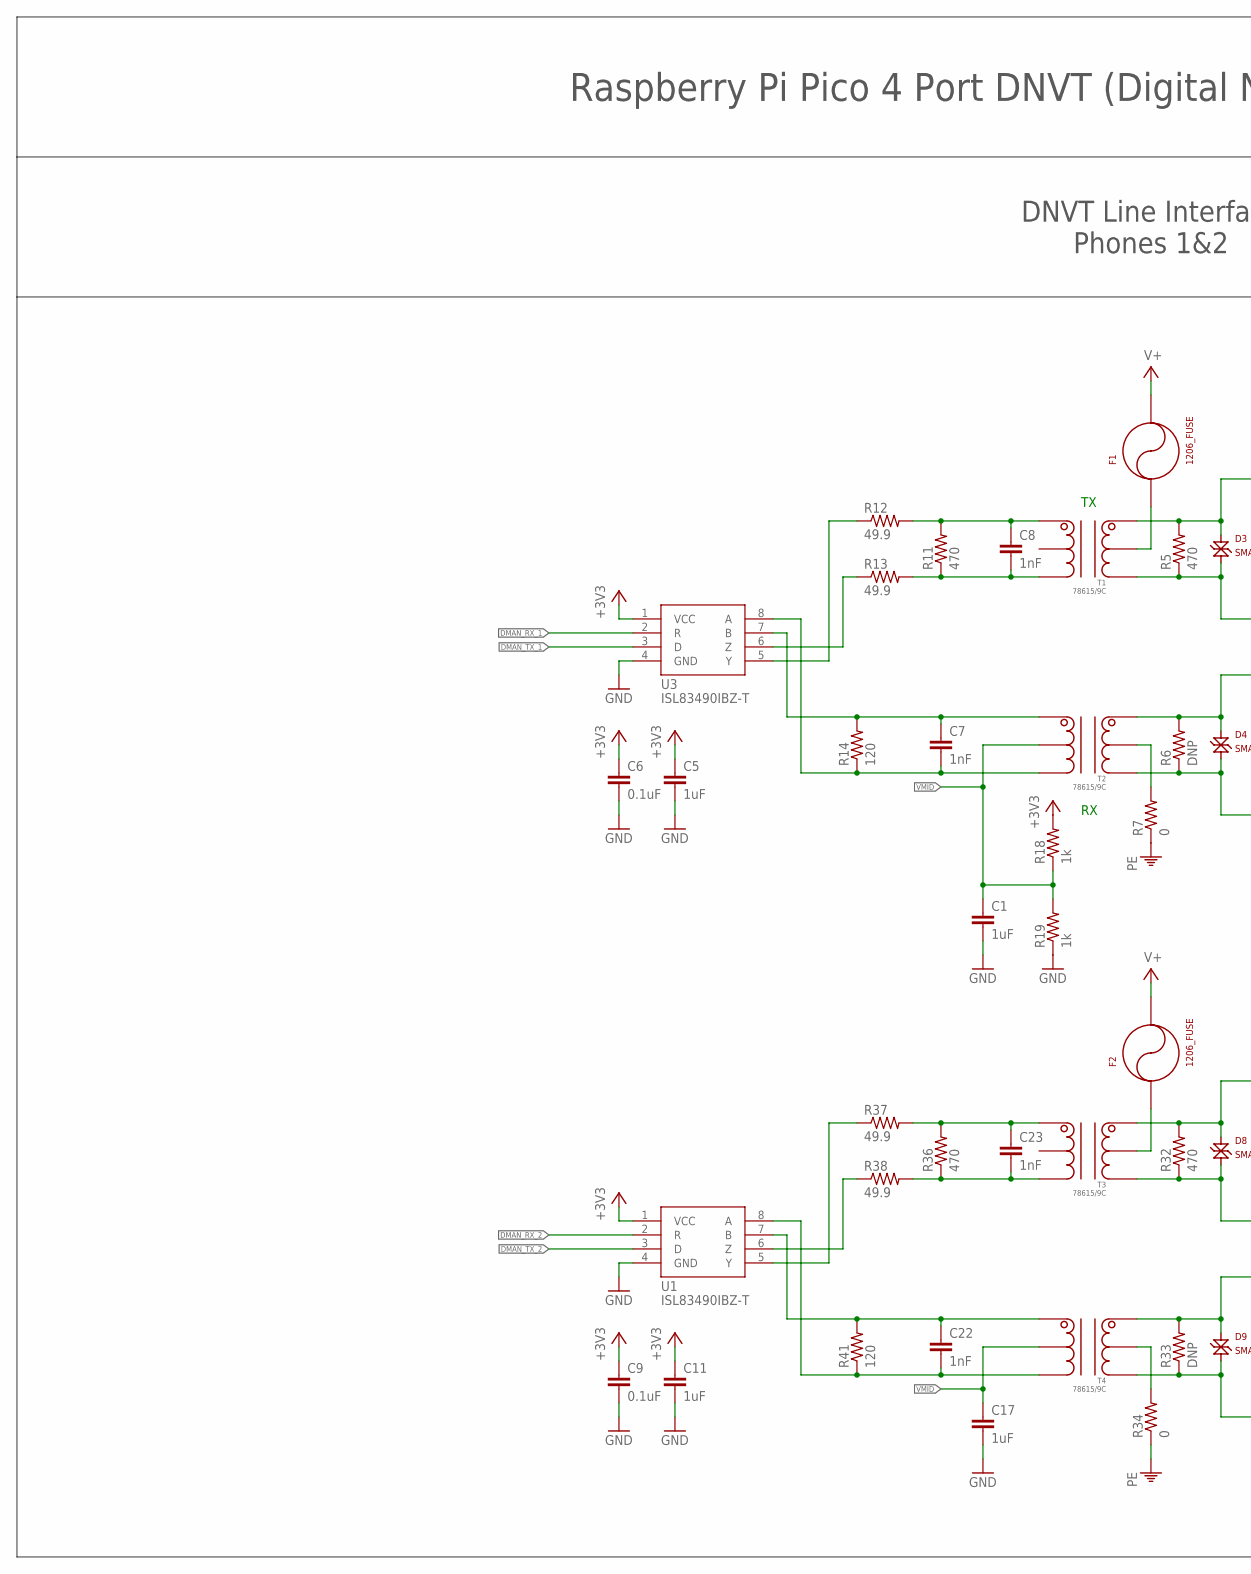
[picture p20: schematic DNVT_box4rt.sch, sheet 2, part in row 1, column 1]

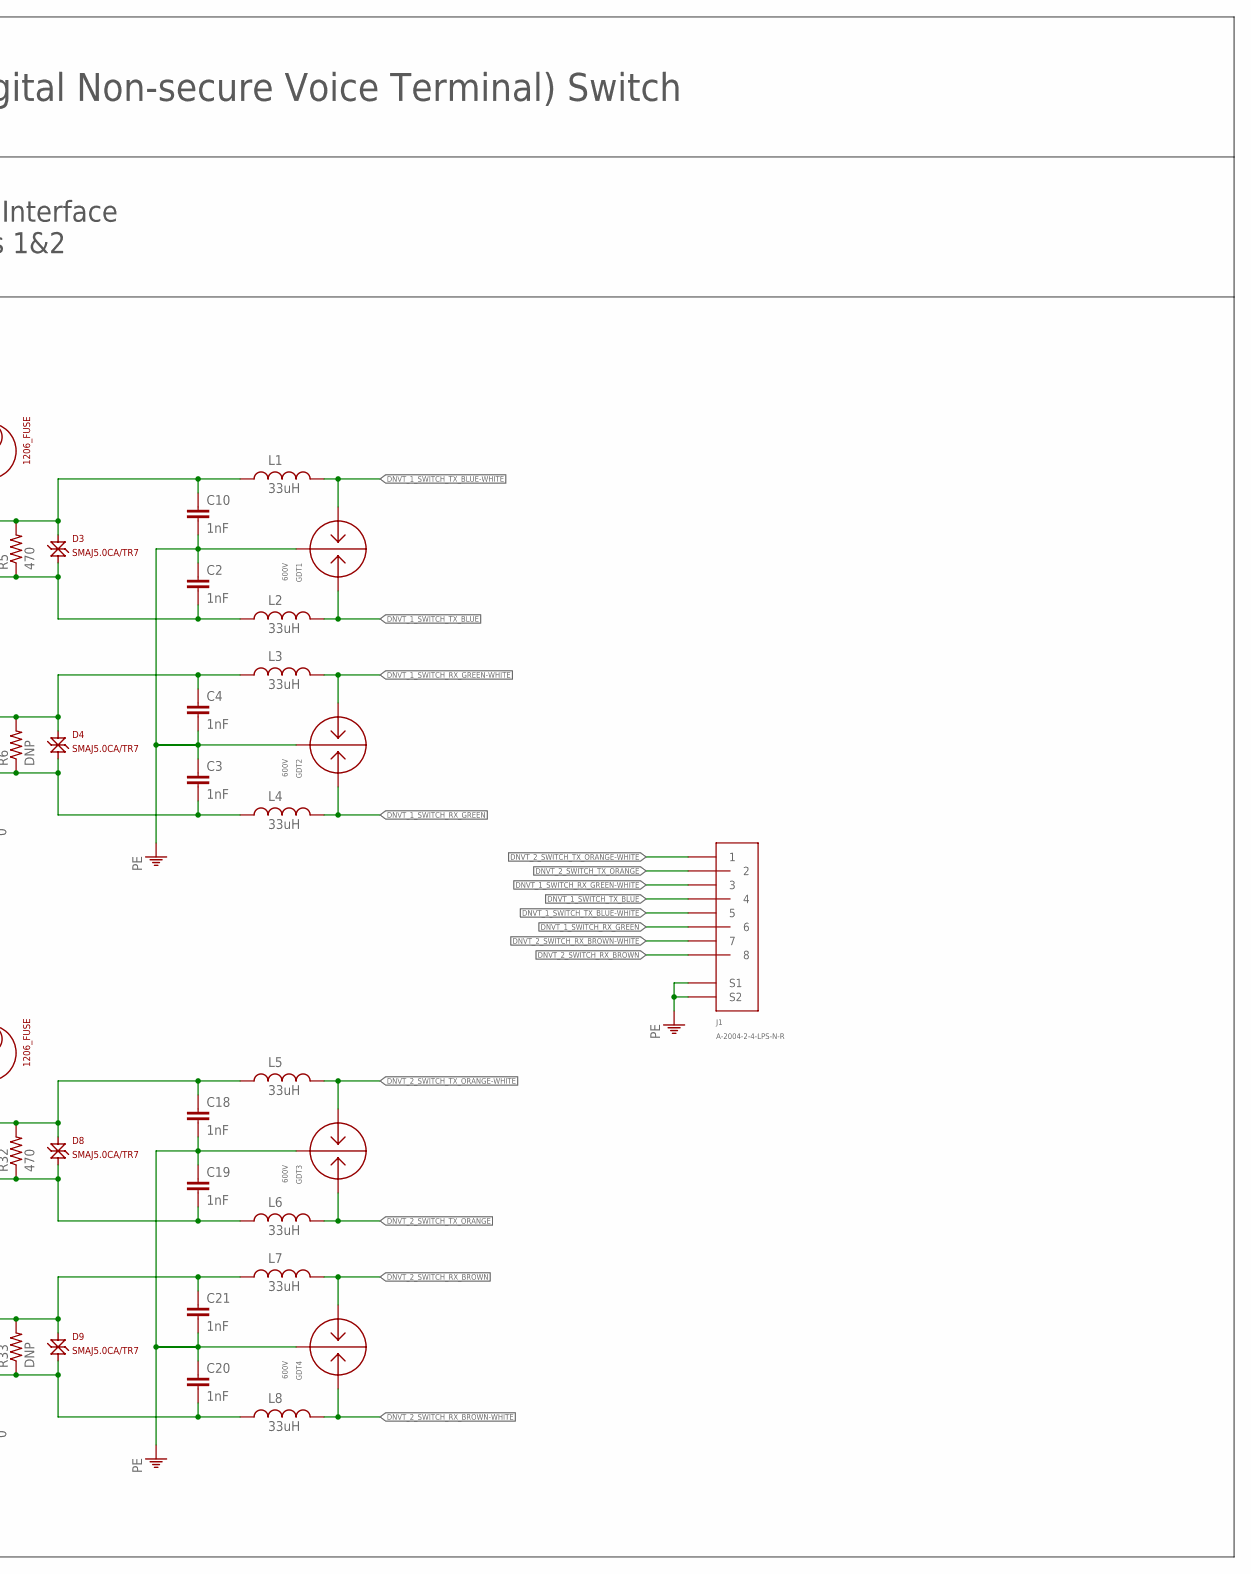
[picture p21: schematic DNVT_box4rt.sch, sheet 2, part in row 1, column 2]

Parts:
C1, C5, C11, C17: 1uF; 0805
C2, C3, C4, C7, C8, C10, C18, C19, C20, C21, C22, C23: 1nF; 0805
C6, C9: 0.1uF; 0603
D3, D4, D8, D9: SMAJ5.0CA/TR7; DO-214AC_NO_POL
F1, F2: 1206_FUSE; 1206
GDT1, GDT2, GDT3, GDT4: 600V; 2036_GDT
J1: A-2004-2-4-LPS-N-R
L1, L2, L3, L4, L5, L6, L7, L8: 33uH; SDR0403
R5, R11, R32, R36: 470; R0805
R6, R33: DNP; R0805
R7, R34: 0; R0805
R12, R13, R37, R38: 49.9; R0805
R14, R41: 120; 1206
R18, R19: 1k; 0603
T1, T2, T3, T4: 78615/9C; 786T
U1, U3: ISL83490IBZ-T; SOIC8

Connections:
+3V3: C5.1, C6.1, C9.1, C11.1, R18.2, U1.1 (VCC), U3.1 (VCC); also elsewhere on the board
DMAN_RX_1: U3.2 (R); also elsewhere on the board
DMAN_RX_2: U1.2 (R); also elsewhere on the board
DMAN_TX_1: U3.3 (D); also elsewhere on the board
DMAN_TX_2: U1.3 (D); also elsewhere on the board
DNVT_1_SWITCH_RX_GREEN: GDT2.L2, J1.6, L4.2
DNVT_1_SWITCH_RX_GREEN-WHITE: GDT2.L1, J1.3, L3.2
DNVT_1_SWITCH_TX_BLUE: GDT1.L2, J1.4, L2.2
DNVT_1_SWITCH_TX_BLUE-WHITE: GDT1.L1, J1.5, L1.2
DNVT_2_SWITCH_RX_BROWN: GDT4.L1, J1.8, L7.2
DNVT_2_SWITCH_RX_BROWN-WHITE: GDT4.L2, J1.7, L8.2
DNVT_2_SWITCH_TX_ORANGE: GDT3.L2, J1.2, L6.2
DNVT_2_SWITCH_TX_ORANGE-WHITE: GDT3.L1, J1.1, L5.2
GND: C1.2, C5.2, C6.2, C9.2, C11.2, C17.2, R19.1, U1.4 (GND), U3.4 (GND); also elsewhere on the board
unnamed: C10.1, D3.C (K), L1.1, R5.2, T1.1
unnamed: C2.2, D3.A, L2.1, R5.1, T1.3
unnamed: C4.1, D4.C (K), L3.1, R6.2, T2.1
unnamed: C3.2, D4.A, L4.1, R6.1, T2.3
unnamed: R7.2, T2.2
unnamed: F1.1, T1.2
unnamed: C22.1, R41.2, T4.6, U1.7 (B)
unnamed: C7.1, R14.2, T2.6, U3.7 (B)
unnamed: C7.2, R14.1, T2.4, U3.8 (A)
unnamed: C8.2, R11.1, R13.2, T1.4
unnamed: C8.1, R11.2, R12.2, T1.6
unnamed: R12.1, U3.5 (Y)
unnamed: R13.1, U3.6 (Z)
unnamed: C22.2, R41.1, T4.4, U1.8 (A)
unnamed: C18.1, D8.C (K), L5.1, R32.2, T3.1
unnamed: C19.2, D8.A, L6.1, R32.1, T3.3
unnamed: C21.1, D9.C (K), L7.1, R33.2, T4.1
unnamed: C20.2, D9.A, L8.1, R33.1, T4.3
unnamed: R34.2, T4.2
unnamed: F2.1, T3.2
unnamed: C23.1, R36.2, R37.2, T3.6
unnamed: R37.1, U1.5 (Y)
unnamed: R38.1, U1.6 (Z)
unnamed: C23.2, R36.1, R38.2, T3.4
PE: C2.1, C3.1, C4.2, C10.2, C18.2, C19.1, C20.1, C21.2, GDT1.C, GDT2.C, GDT3.C, GDT4.C, J1.S1, J1.S2, R7.1, R34.1; also elsewhere on the board
V+: F1.2, F2.2; also elsewhere on the board
VMID: C1.1, C17.1, R18.1, R19.2, T2.5, T4.5; also elsewhere on the board

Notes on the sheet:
Raspberry Pi Pico 4 Port DNVT (Digital Non-secure Voice Terminal) Switch
DNVT Line Interface Phones 1&2

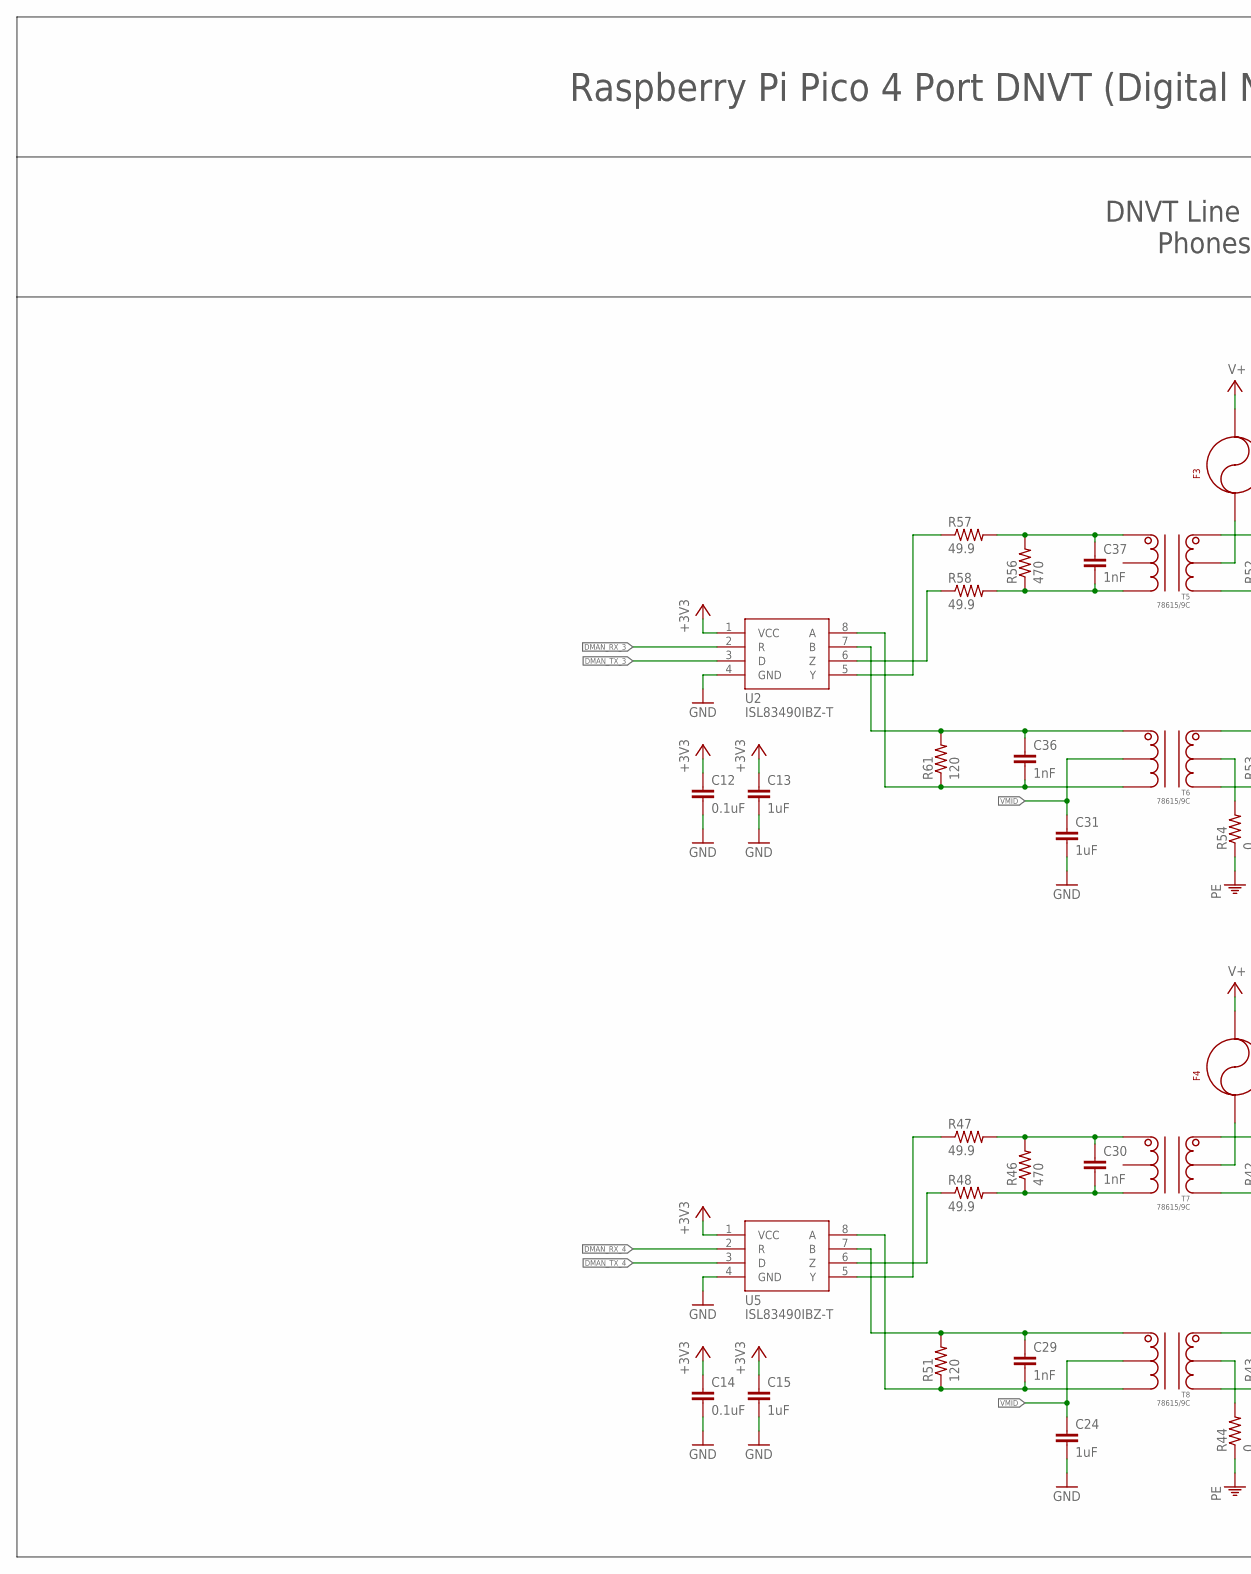
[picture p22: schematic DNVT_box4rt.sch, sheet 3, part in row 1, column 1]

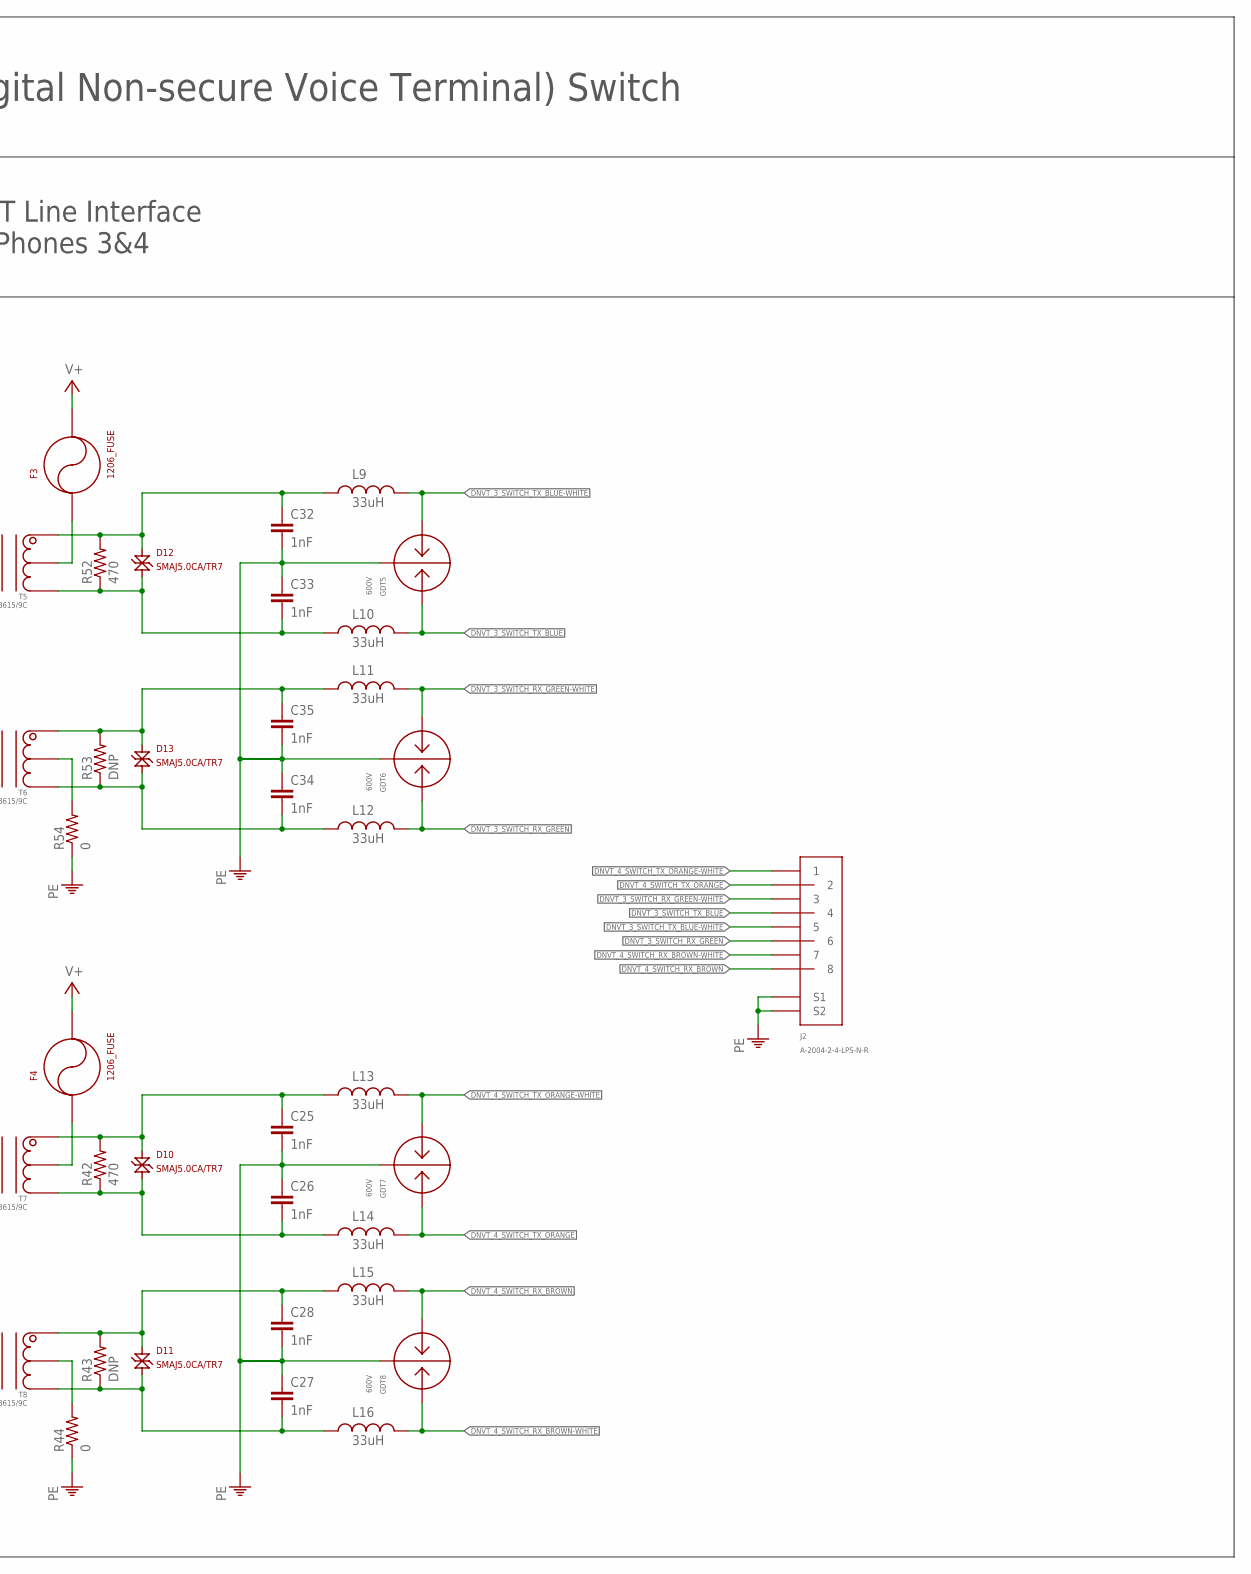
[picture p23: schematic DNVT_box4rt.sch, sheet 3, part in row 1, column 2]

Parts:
C12, C14: 0.1uF; 0603
C13, C15, C24, C31: 1uF; 0805
C25, C26, C27, C28, C29, C30, C32, C33, C34, C35, C36, C37: 1nF; 0805
D10, D11, D12, D13: SMAJ5.0CA/TR7; DO-214AC_NO_POL
F3, F4: 1206_FUSE; 1206
GDT5, GDT6, GDT7, GDT8: 600V; 2036_GDT
J2: A-2004-2-4-LPS-N-R
L9, L10, L11, L12, L13, L14, L15, L16: 33uH; SDR0403
R42, R46, R52, R56: 470; R0805
R43, R53: DNP; R0805
R44, R54: 0; R0805
R47, R48, R57, R58: 49.9; R0805
R51, R61: 120; 1206
T5, T6, T7, T8: 78615/9C; 786T
U2, U5: ISL83490IBZ-T; SOIC8

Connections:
+3V3: C12.1, C13.1, C14.1, C15.1, U2.1 (VCC), U5.1 (VCC); also elsewhere on the board
DMAN_RX_3: U2.2 (R); also elsewhere on the board
DMAN_RX_4: U5.2 (R); also elsewhere on the board
DMAN_TX_3: U2.3 (D); also elsewhere on the board
DMAN_TX_4: U5.3 (D); also elsewhere on the board
DNVT_3_SWITCH_RX_GREEN: GDT6.L2, J2.6, L12.2
DNVT_3_SWITCH_RX_GREEN-WHITE: GDT6.L1, J2.3, L11.2
DNVT_3_SWITCH_TX_BLUE: GDT5.L2, J2.4, L10.2
DNVT_3_SWITCH_TX_BLUE-WHITE: GDT5.L1, J2.5, L9.2
DNVT_4_SWITCH_RX_BROWN: GDT8.L1, J2.8, L15.2
DNVT_4_SWITCH_RX_BROWN-WHITE: GDT8.L2, J2.7, L16.2
DNVT_4_SWITCH_TX_ORANGE: GDT7.L2, J2.2, L14.2
DNVT_4_SWITCH_TX_ORANGE-WHITE: GDT7.L1, J2.1, L13.2
GND: C12.2, C13.2, C14.2, C15.2, C24.2, C31.2, U2.4 (GND), U5.4 (GND); also elsewhere on the board
unnamed: C36.1, R61.2, T6.6, U2.7 (B)
unnamed: C36.2, R61.1, T6.4, U2.8 (A)
unnamed: C25.1, D10.C (K), L13.1, R42.2, T7.1
unnamed: C26.2, D10.A, L14.1, R42.1, T7.3
unnamed: C28.1, D11.C (K), L15.1, R43.2, T8.1
unnamed: C27.2, D11.A, L16.1, R43.1, T8.3
unnamed: R44.2, T8.2
unnamed: F4.1, T7.2
unnamed: C29.1, R51.2, T8.6, U5.7 (B)
unnamed: C30.1, R46.2, R47.2, T7.6
unnamed: R47.1, U5.5 (Y)
unnamed: R48.1, U5.6 (Z)
unnamed: C30.2, R46.1, R48.2, T7.4
unnamed: C29.2, R51.1, T8.4, U5.8 (A)
unnamed: C32.1, D12.C (K), L9.1, R52.2, T5.1
unnamed: C33.2, D12.A, L10.1, R52.1, T5.3
unnamed: C35.1, D13.C (K), L11.1, R53.2, T6.1
unnamed: C34.2, D13.A, L12.1, R53.1, T6.3
unnamed: R54.2, T6.2
unnamed: F3.1, T5.2
unnamed: C37.1, R56.2, R57.2, T5.6
unnamed: R57.1, U2.5 (Y)
unnamed: R58.1, U2.6 (Z)
unnamed: C37.2, R56.1, R58.2, T5.4
PE: C25.2, C26.1, C27.1, C28.2, C32.2, C33.1, C34.1, C35.2, GDT5.C, GDT6.C, GDT7.C, GDT8.C, J2.S1, J2.S2, R44.1, R54.1; also elsewhere on the board
V+: F3.2, F4.2; also elsewhere on the board
VMID: C24.1, C31.1, T6.5, T8.5; also elsewhere on the board

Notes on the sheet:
Raspberry Pi Pico 4 Port DNVT (Digital Non-secure Voice Terminal) Switch
DNVT Line Interface Phones 3&4

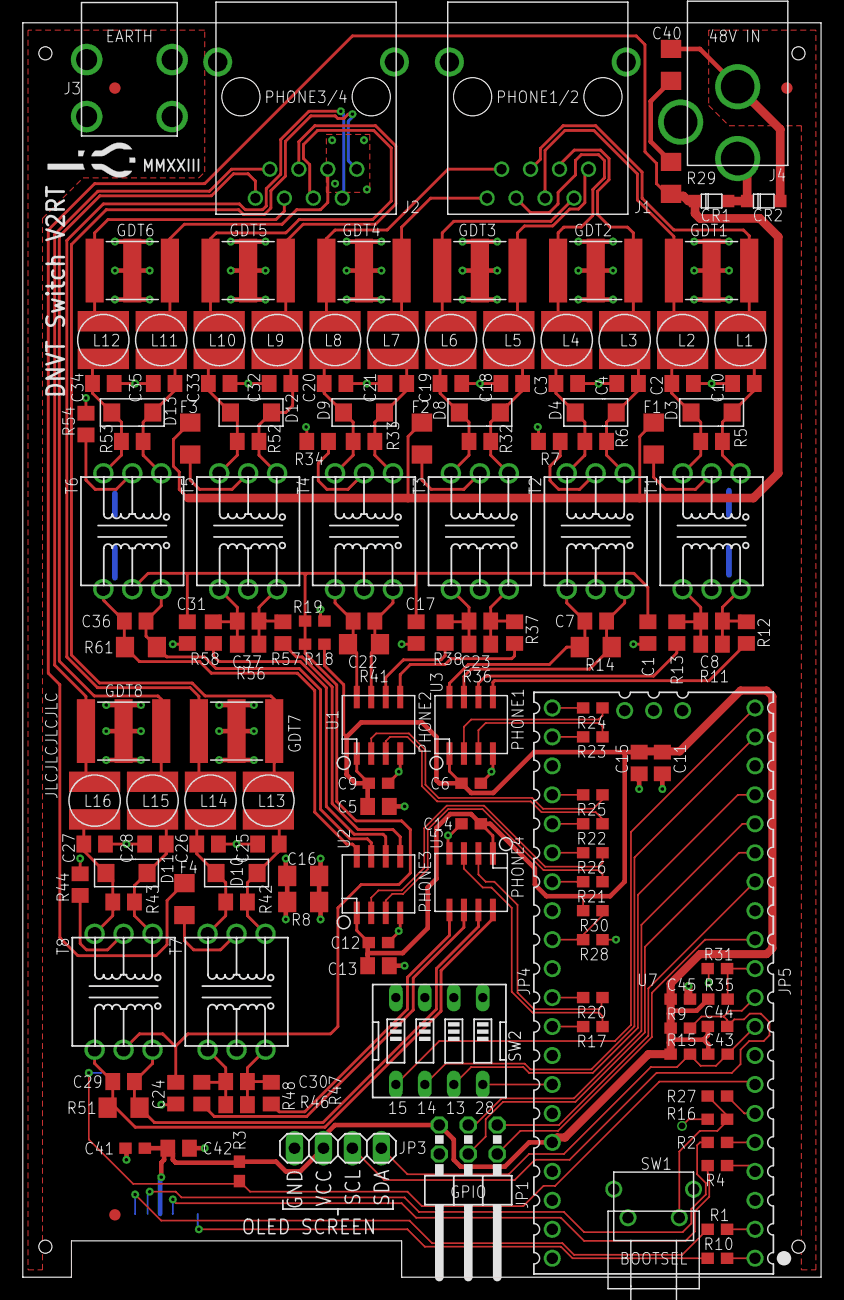
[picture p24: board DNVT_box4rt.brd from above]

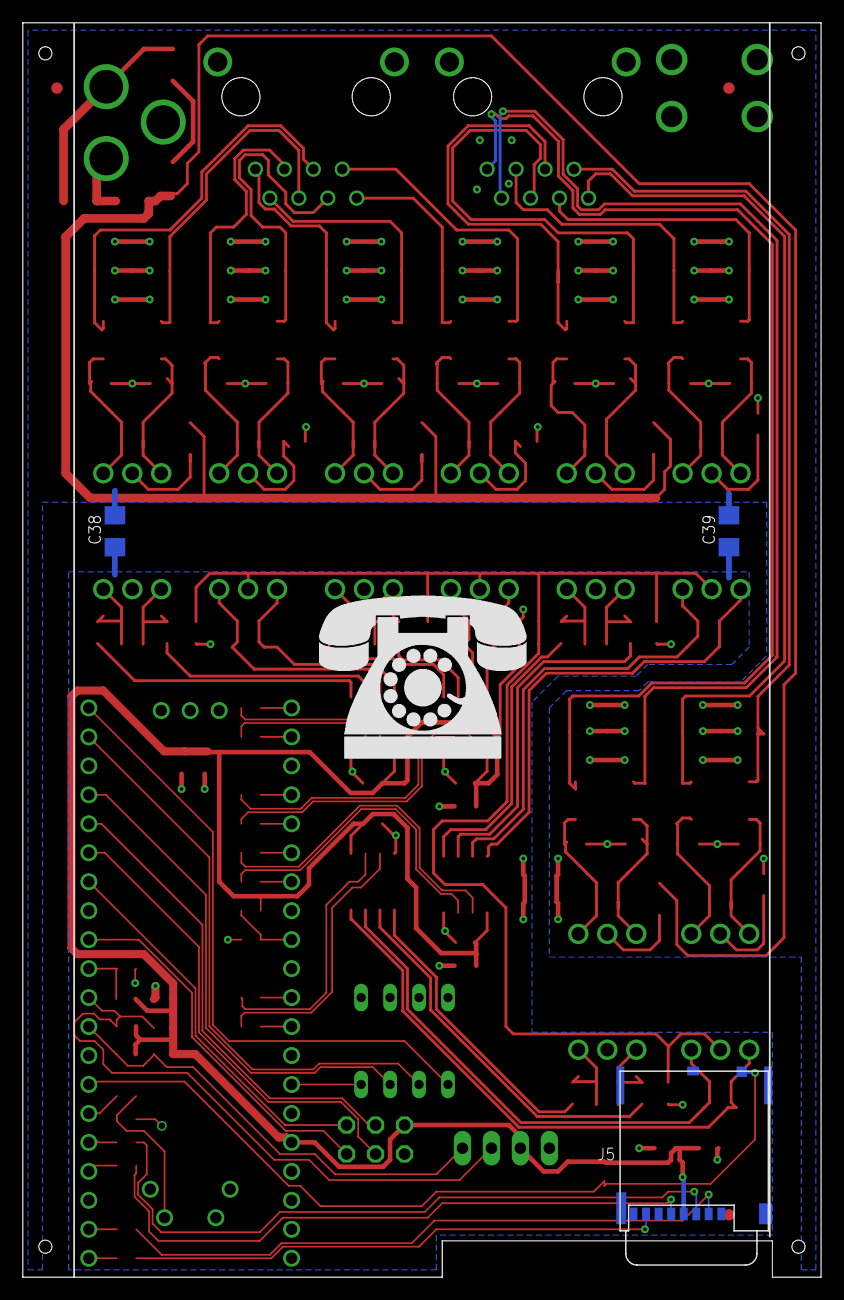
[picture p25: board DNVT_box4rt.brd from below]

Board: 2 copper layers, 70.0 x 110.0 mm, 158 parts (3 on the bottom side), 111 nets.

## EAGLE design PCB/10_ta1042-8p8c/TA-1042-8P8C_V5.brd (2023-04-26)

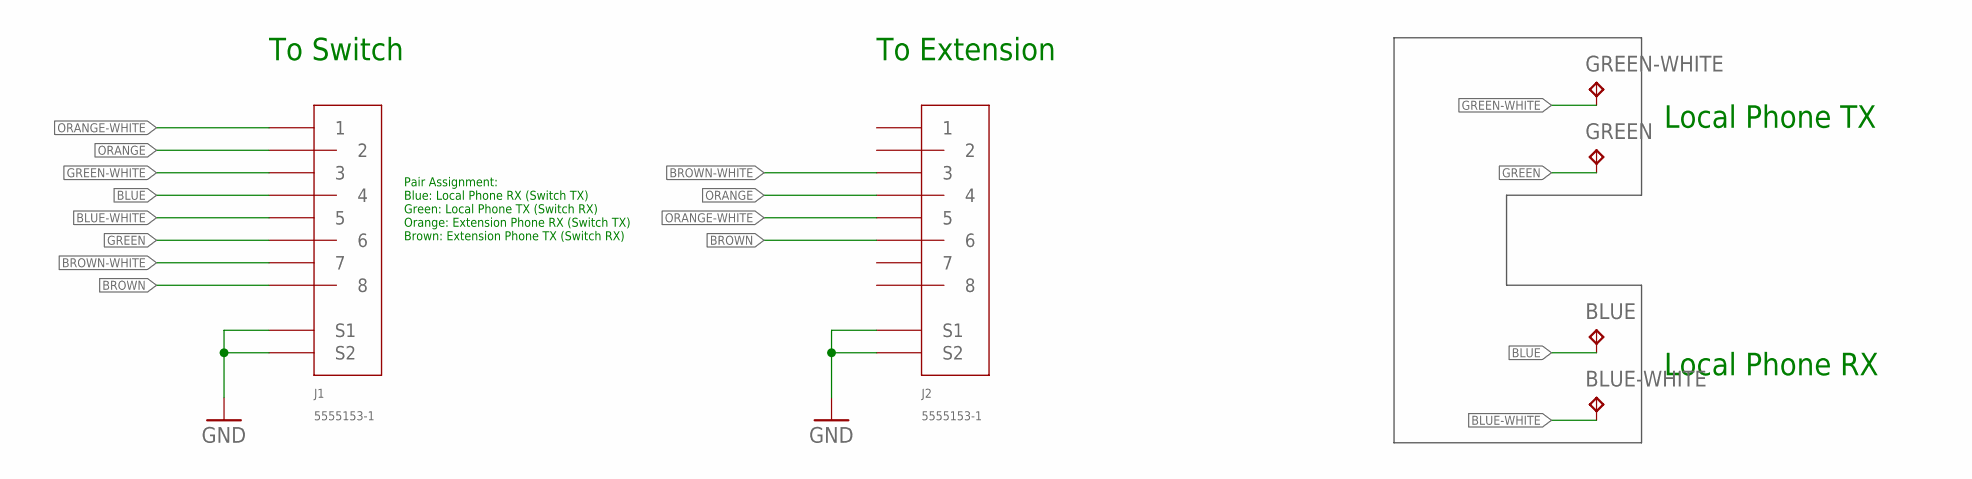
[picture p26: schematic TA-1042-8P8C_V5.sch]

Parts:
BLUE: TPTP20R; TP20R
BLUE-WHITE: TPTP20R; TP20R
GREEN: TPTP20R; TP20R
GREEN-WHITE: TPTP20R; TP20R
J1, J2: 5555153-1

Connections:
BLUE: BLUE.TP, J1.4
BLUE-WHITE: BLUE-WHITE.TP, J1.5
BROWN: J1.8, J2.6
BROWN-WHITE: J1.7, J2.3
GND: J1.S1, J1.S2, J2.S1, J2.S2
GREEN: GREEN.TP, J1.6
GREEN-WHITE: GREEN-WHITE.TP, J1.3
ORANGE: J1.2, J2.4
ORANGE-WHITE: J1.1, J2.5

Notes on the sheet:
Pair Assignment: Blue: Local Phone RX (Switch TX) Green: Local Phone TX (Switch RX) Orange: Extension Phone RX (Switch TX) Brown: Extension Phone TX (Switch RX)
To Switch
To Extension
Local Phone TX
Local Phone RX

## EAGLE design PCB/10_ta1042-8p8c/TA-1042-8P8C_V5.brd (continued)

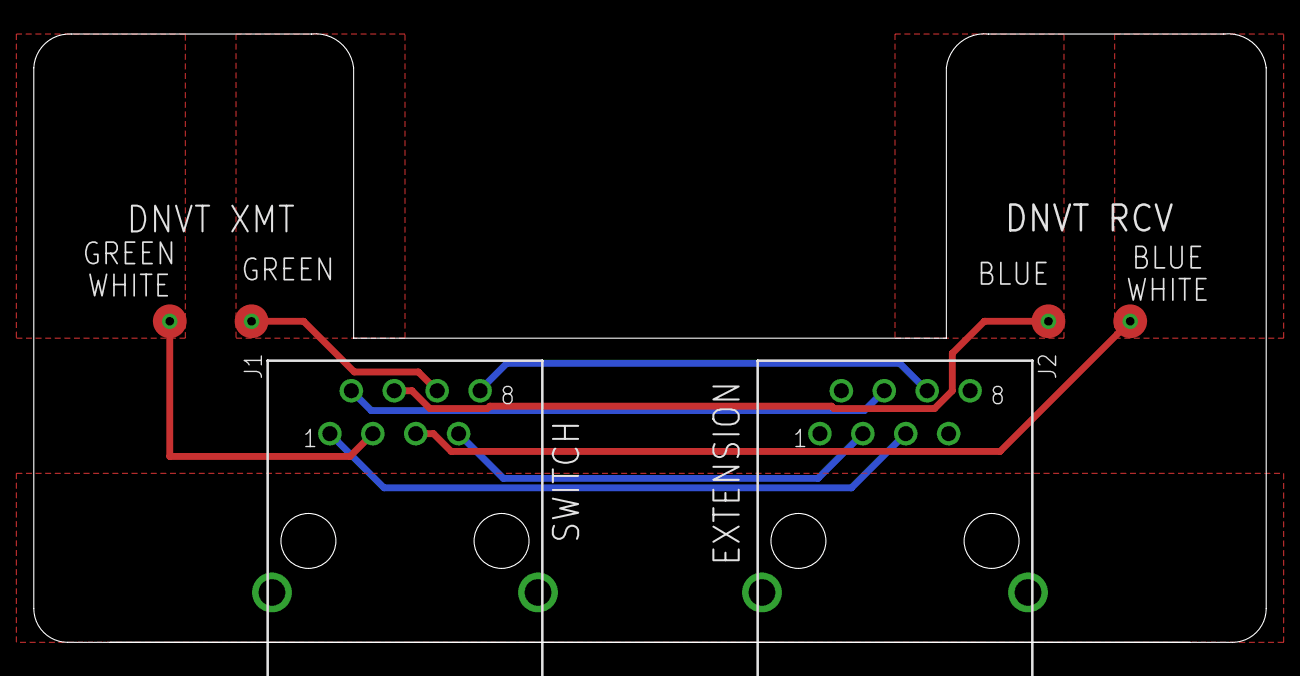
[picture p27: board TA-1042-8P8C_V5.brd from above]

Board: 2 copper layers, 72.9 x 36.0 mm, 6 parts (0 on the bottom side), 9 nets.

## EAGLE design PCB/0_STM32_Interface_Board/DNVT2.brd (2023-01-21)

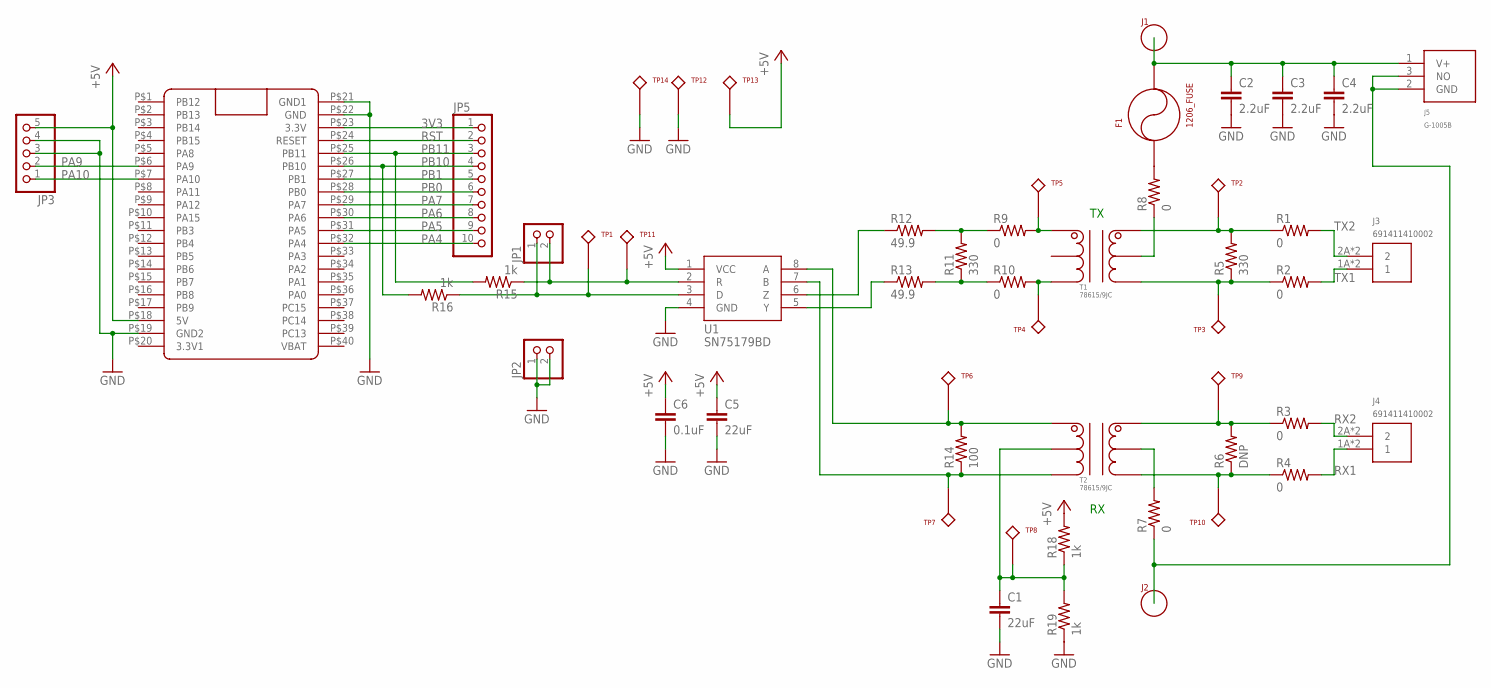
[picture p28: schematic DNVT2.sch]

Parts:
C1, C5: 22uF; 1210
C2, C3, C4: 2.2uF; 1210
C6: 0.1uF; 0603
F1: 1206_FUSE; 1206
J1, J2: BANANA
J3, J4: 691411410002
J5: G-1005B
JP1, JP2: PINHD-1X2; 1X02
JP3: PINHD-1X5; 1X05
JP5: PINHD-1X10; 1X10
R1, R2, R3, R4, R7, R8, R9, R10: 0; R0805
R5, R11: 330; R0805
R6: DNP; R0805
R12, R13: 49.9; R0805
R14: 100; R0805
R15, R16, R18, R19: 1k; 0603
T1, T2: 78615/9JC; 786
TP1, TP11, TP12, TP13, TP14: 5001
TP2, TP3, TP4, TP5, TP6, TP7, TP8, TP9, TP10: 5002; 5001
U1: SN75179BD; SOIC8
U$1: BLUE_PILL

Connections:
3V3: JP5.1, U$1.P$23 (3.3V)
+5V: C5.1, C6.1, JP3.5, R18.2, TP13.P$1, U1.1 (VCC), U$1.P$18 (5V)
GND: C1.2, C2.2, C3.2, C4.2, C5.2, C6.2, JP2.1, JP2.2, JP3.3, JP3.4, R19.1, TP12.P$1, TP14.P$1, U1.4 (GND), U$1.P$19 (GND2), U$1.P$21 (GND1), U$1.P$22 (GND)
unnamed: R1.1, R5.2, T1.6, TP2.P$1
unnamed: R2.1, R5.1, T1.4, TP3.P$1
unnamed: R3.1, R6.2, T2.6, TP9.P$1
unnamed: R4.1, R6.1, T2.4, TP10.P$1
unnamed: R7.2, T2.5
unnamed: R8.1, T1.5
unnamed: C1.1, R18.1, R19.2, T2.2, TP8.P$1
unnamed: R14.1, T2.3, TP7.P$1, U1.7 (B)
unnamed: R14.2, T2.1, TP6.P$1, U1.8 (A)
unnamed: R9.2, T1.1, TP5.P$1
unnamed: R10.2, T1.3, TP4.P$1
unnamed: R9.1, R11.2, R12.2
unnamed: R10.1, R11.1, R13.2
unnamed: R12.1, U1.6 (Z)
unnamed: R13.1, U1.5 (Y)
unnamed: F1.1, R8.2
unnamed: JP1.2, R15.1, TP11.P$1, U1.2 (R)
unnamed: C2.1, C3.1, C4.1, F1.2, J1.P$1, J5.1 (V+)
unnamed: JP1.1, R16.1, TP1.P$1, U1.3 (D)
PA4: JP5.10, U$1.P$32 (PA4)
PA5: JP5.9, U$1.P$31 (PA5)
PA6: JP5.8, U$1.P$30 (PA6)
PA7: JP5.7, U$1.P$29 (PA7)
PA9: JP3.2, U$1.P$6 (PA9)
PA10: JP3.1, U$1.P$7 (PA10)
PB0: JP5.6, U$1.P$28 (PB0)
PB1: JP5.5, U$1.P$27 (PB1)
PB10: JP5.4, R16.2, U$1.P$26 (PB10)
PB11: JP5.3, R15.2, U$1.P$25 (PB11)
RST: JP5.2, U$1.P$24 (RESET)
RTN: J2.P$1, J5.2 (GND), J5.3 (NO), R7.1
RX1: J4.1A (1), J4.1B (1), R4.2
RX2: J4.2A (2), J4.2B (2), R3.2
TX1: J3.1A (1), J3.1B (1), R2.2
TX2: J3.2A (2), J3.2B (2), R1.2

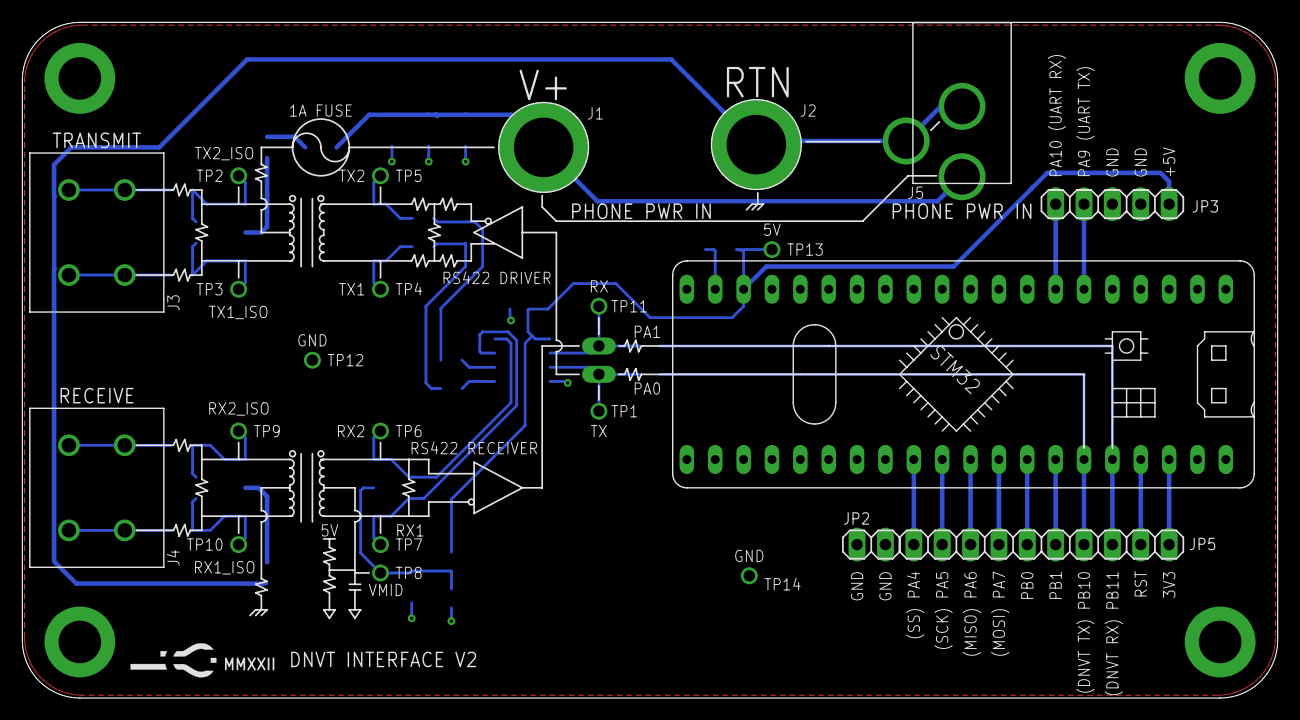
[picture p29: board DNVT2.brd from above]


Board: 2 copper layers, 112.4 x 60.5 mm, 52 parts (29 on the bottom side), 38 nets.

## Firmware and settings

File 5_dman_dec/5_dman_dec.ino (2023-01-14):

/*
 * Crappy Differential Manchester Decoding.
 * This code chokes at 32kHz, but works for 16 kHz.
 * 
 * Robert Ruark
 * 2022
 */
#include <Arduino.h>

HardwareTimer timer(TIM1);
bool txVal = false;
bool process_next_bit   = true;
bool process_next_byte  = true;
bool current_bit        = 1;
byte current_byte       = 0x00;
int state               = 0;
byte tx_byte[5]         = {0xFF,0xEB,0x55,0x14,0xAA};
int bit_index           = 0;
int half_period_pos     = 0;
bool half_period_val[2] = {1,1};

int max_reps            = 10;
int reps                = 0;
int byte_position       = 0;
int short_count         = 0;

volatile bool reading   = 0;
volatile bool last_reading = 0;
volatile int reading_duration = 0;
volatile int last_reading_duration = 0;
volatile bool process_reading = false;

void OnTimer1Interrupt() 
{
    reading = digitalRead(PB11);
    //digitalWrite(PB10,reading);
    if(reading == last_reading)
    {
      reading_duration++;
    }
    else
    {
      last_reading_duration = reading_duration;
      reading_duration = 0;
      process_reading  = true;
    }
    last_reading = reading;
}

void setup() 
{
    //pinMode(PB10, OUTPUT);
    pinMode(PB0, OUTPUT);
    pinMode(PB11, INPUT);
    pinMode(PA7, INPUT_PULLUP);
    Serial.begin(1000000);
    // Configure timer
    timer.setPrescaleFactor(125); // Set prescaler to 2564 => timer frequency = 36MHz/125 = 288000 Hz
    timer.setOverflow(4); // Set overflow to 1 => timer frequency = 288000 Hz
    timer.attachInterrupt(OnTimer1Interrupt);
    timer.refresh(); // Make register changes take effect
    timer.resume(); // Start
}
void loop() 
{
  //Serial.println(last_reading_duration);
  if(process_reading)
  {
    process_reading = false;
    if(last_reading_duration>6)
    {
      current_byte = current_byte << 1;
      current_byte = current_byte | 1;
      short_count  = 0;
      bit_index++;
    }
    else
    {
      short_count++;
      if(short_count == 2)
      {
        current_byte = current_byte << 1;
        //current_byte = 0x00;
        bit_index++;
        short_count = 0;
      }
    }
    if(!short_count)
    {
      if(bit_index ==8)
      {
        Serial.print(current_byte,HEX);
        current_byte = 0x00;
        bit_index = 0;
      }
    }
  }
}

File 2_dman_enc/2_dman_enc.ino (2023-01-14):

/*
Non-functional Differential Manchester Encoder
Robert Ruark
2022
*/
#define period 31
int rep = 5000;
byte tx_byte[2] = {0xFF,0x4B};
bool state=0;
int initial = 0;
int ind = 0;

// the setup function runs once when you press reset or power the board
void setup() {
  // initialize digital pin LED_BUILTIN as an output.
  Serial.begin(115200);
  pinMode(LED_BUILTIN, OUTPUT);
  pinMode(PA0, OUTPUT);

}

// the loop function runs over and over again forever
void loop() 
{
  if(ind == 0)
  {
    initial =0;
  }
  else
  {
    initial = 1;
  }
  
  byte temp = tx_byte[initial];
  for (int i = 0; i < 8; i++)
  {
      bool b = temp & 0x80;
      //Serial.print(b);
      temp = temp << 1;
      if(!b)
      {
        state = !state;
        digitalWrite(PA0, state);
      }
      delayMicroseconds(period);
      state = !state;
      digitalWrite(PA0, state);
      delayMicroseconds(period);
  }
    
  ind++; 
  if(ind == rep)
  {
    ind = 0;
    delay(500);
  }
}

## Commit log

2023-01-14 Adding Python DMAN decoder and CPCW calculator
    [16k_lb_start.csv, 16k_lb_start_trunk.csv, blue_pill_tx.csv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]
2023-01-21 Adding Interface Board PCB Design Files
    [DNVT.brd, DNVT.sch, DNVT2.brd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]
2023-03-11 Adding switch PCB files
    V3 SMD
    V3 SMD RJ45
    V3 SMD Through hole transformers
    V3 SMD RJ45 Through hole transformers
    [DNVT_box3.brd, DNVT_box3.sch, DNVT_box3_top_bom.csv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]
2023-03-11 Adding back plates and boms
    [DNVT_box3rt_th_bom.csv, DNVT_box_back_2.brd, DNVT_box_back_2.sch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]
2023-03-16 Adding the rest of the BOMs
    [DNVT_box3_aux_bom.csv, DNVT_box3_th_bom.csv, DNVT_box3r_aux_bom.csv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]
2023-03-16 Fixing readme for V3T
    [DNVT_box3_aux_bom.csv]
2023-04-02 Added JLCPCB THT assembly files
    The new files for the V3RT design upload without errors and require no manual tweaks. JLCPCB will assemble all parts aside from the DC barrel jack and transformers which they do not have an acceptable equivalent of in their parts library.
    [DNVT_box3r_aux_bom.csv, DNVT_box3rt.brd, DNVT_box3rt.sch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]
2023-04-06 Corrected DC Barrel Jack Part Number
    [DNVT_box3_th_bom.csv, DNVT_box3r_th_bom.csv, DNVT_box3rt_th_bom.csv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]
2023-04-11 Adding soldering fixture stl
    [Soldring_fixture.stl]
2023-04-26 manual update
    [TA-1042-8P8C_V4.brd, TA-1042-8P8C_V4.sch, TA-1042-8P8C_V4_top_bom.csv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]
2023-04-26 Updated TA-1042 to RJ45 files
    [TA-1042-8P8C_V4.brd, TA-1042-8P8C_V4_top_bom.csv, TA-1042-8P8C_V5.brd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]
2023-05-02 V4 to eliminate emissions from OLED cable
    [DNVT_box4r_aux_bom.csv, DNVT_box4rt.brd, DNVT_box4rt.sch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]
